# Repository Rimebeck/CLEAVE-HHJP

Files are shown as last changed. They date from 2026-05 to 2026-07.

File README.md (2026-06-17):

# CLEAVE HHJP
日本語配列互換 / 完全無線 / Choc MX両対応のキーボード自作キット「CLEAVE HHJP」のドキュメントリポジトリです。

<p align="center">
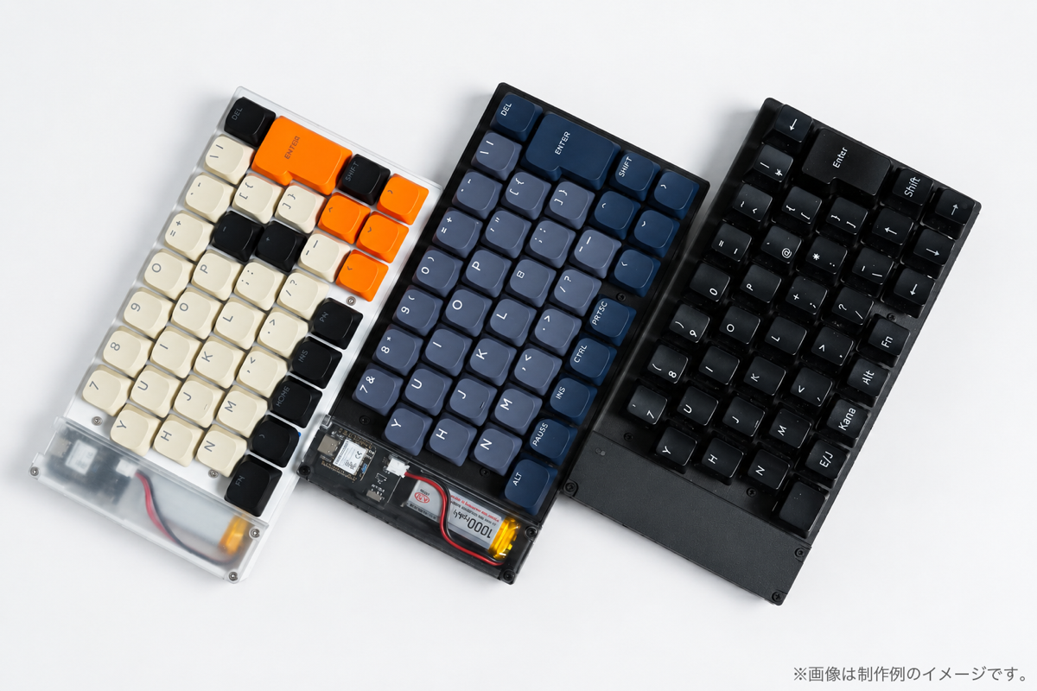
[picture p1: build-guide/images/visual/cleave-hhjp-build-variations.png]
CLEAVE HHJPの複数作例
  
</p>

<p align="center">
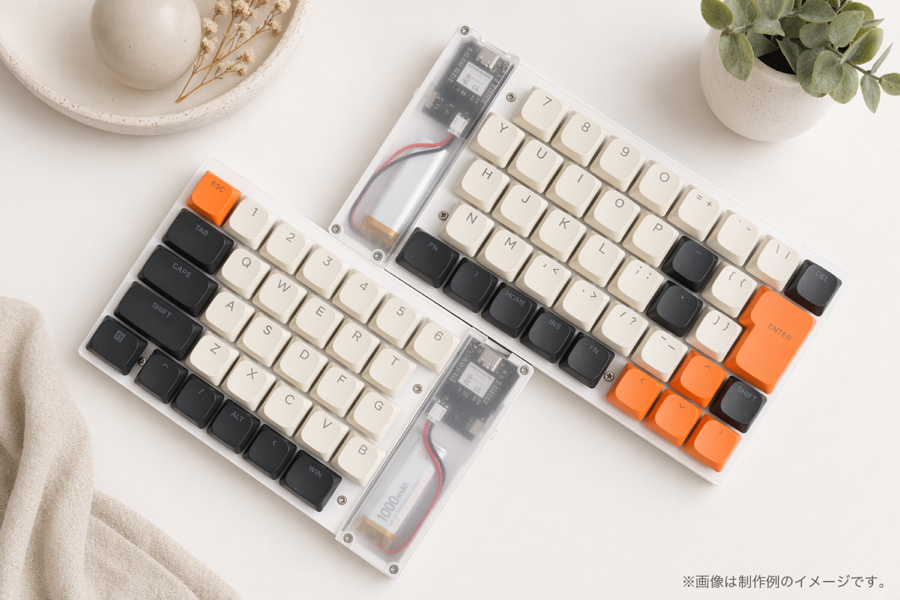
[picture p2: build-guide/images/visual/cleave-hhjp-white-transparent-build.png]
白い透明ケースのCLEAVE HHJP作例
  
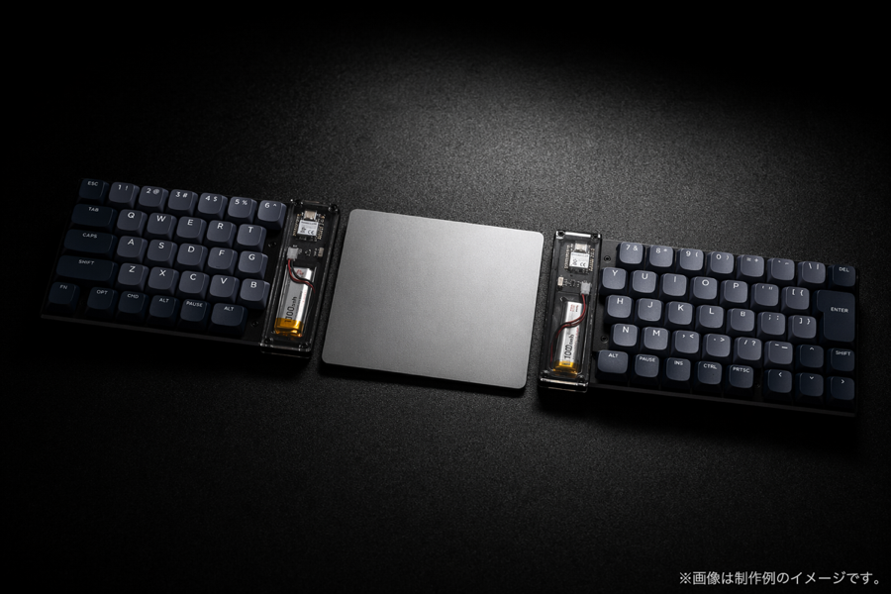
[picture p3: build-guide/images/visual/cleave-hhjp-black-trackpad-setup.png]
黒いCLEAVE HHJPとトラックパッドの作例
  
</p>

購入先：[BOOTH販売ページ](https://rimebeck.booth.pm/items/8395519)

## ドキュメント

- [ビルドガイド](build-guide/README.md)
  組み立て、ファームウェア書き込み、ケース作成、完成後の使い方、カスタマイズ方法をまとめています。

## 関連リンク

- [ファームウェア配布ページ](https://github.com/Rimebeck/Cleave-HHJP/releases)
- [ケースの3Dモデル・PCB 3Dデータ](https://github.com/Rimebeck/Cleave-HHJP/tree/main/models)

## 問い合わせ・不具合報告

ご不明な点はビルドガイドリポジトリの[Issues](https://github.com/Rimebeck/Cleave-HHJP/issues)またはBOOTHの購入者問合せからご連絡ください。

----
QRコードは株式会社デンソーウェーブの登録商標です

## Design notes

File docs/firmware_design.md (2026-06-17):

# ZMKファームウェア設計書
## HHKB JP分割Bluetoothキーボード (CLEAVE HHJP)

---

## 1. プロジェクト概要

### 1.1 キーボード仕様

| 項目 | 仕様 |
|---|---|
| 製品名 | CLEAVE HHJP (HHKB JP分割Bluetoothキーボード) |
| キー配列 | HHKB JP配列ベース |
| 総キー数 | 70キー（左31 + 右39） |
| 分割方式 | 左右分割・無線接続 |
| 接続方式 | Bluetooth 5.0 BLE |
| ホットスワップ | Kailh MX/Chocソケット対応 |

### 1.2 技術スタック

| 要素 | 採用技術 |
|---|---|
| ファームウェア | ZMK (Zephyr Mechanical Keyboard) |
| ビルドシステム | GitHub Actions |
| キーマップ編集 | ZMK Studio対応（GUIによる動的変更可能） |
| 開発環境 | West (Zephyr Build System) |
| 配布形式 | UF2ファイル（USB Mass Storageで書き込み） |

### 1.3 主要機能

- ZMK Studio対応による動的キーマップ変更
- Bluetooth 5デバイス切替
- バッテリー残量表示（内蔵RGB LED）
- 無線分割通信（左右BLE接続）
- スリープ/ウェイク機能
- USB充電（電源スイッチOFF時も充電可能）

---

## 2. ハードウェア仕様

### 2.1 マイコン (MCU)

| 項目 | 仕様 |
|---|---|
| モデル | Seeed XIAO nRF52840 Plus |
| プロセッサ | ARM Cortex-M4 64MHz (Nordic nRF52840) |
| メモリ | 256KB RAM / 1MB Flash |
| Bluetooth | Bluetooth 5.0 / BLE |
| GPIO数 | 20ピン（表面11 + 端面スルーホール9） |
| 技適認証 | 222-257139 |
| 動作電圧 | 3.3V |
| 実装方法 | 直接SMDはんだ付け（ピンヘッダ不使用） |
| 数量 | 2個（左右各1個） |

**採用理由**:
- GPIO 20本（通常版13本）で左右両側の大型マトリックスに対応
- 追加ピンは端面スルーホール（1.27mmピッチ）で裏面パッドへの細線はんだ付け不要
- 内蔵LiPo充電回路（BQ25101）とRGB LED搭載
- 技適認証済みでBluetoothキーボードの販売・頒布が可能

### 2.2 キーマトリックス構成

#### 左側PCB

| 項目 | 仕様 |
|---|---|
| マトリックス | 7列（COL0-6） × 5行（ROW0-4） |
| キー数 | 31キー |
| スキャン方式 | COL2ROW |
| ダイオード | 1N4148W (SOD-123) × 31個 |

**キー配置**:
```
Row 0: Esc, 1, 2, 3, 4, 5, 6
Row 1: Tab, Q, W, E, R, T
Row 2: Ctrl, A, S, D, F, G
Row 3: Shift, Z, X, C, V, B
Row 4: Fn, Win, Cmd, Alt, 英/日, Space (左側)
```

#### 右側PCB

| 項目 | 仕様 |
|---|---|
| マトリックス | 8列（COL0-7） × 5行（ROW0-4） |
| キー数 | 39キー |
| スキャン方式 | COL2ROW |
| ダイオード | 1N4148W (SOD-123) × 39個 |

**キー配置**:
```
Row 0: 7, 8, 9, 0, -, ^, ¥, Backspace
Row 1: Y, U, I, O, P, @, [, Enter
Row 2: H, J, K, L, ;, :, ]
Row 3: N, M, <, >, /, _, ↑, Shift
Row 4: Space (右側), 英/日, カナ, Alt, Fn, ←, ↓, →
```

### 2.3 ピンアサイン

#### 左側PCB - ピン配置

| 機能 | 論理名 | 物理ピン | nRF52840ピン | 備考 |
|---|---|---|---|---|
| COL0 | D0 | P0.02 | P0.02 | 表面パッド |
| COL1 | D1 | P0.03 | P0.03 | 表面パッド |
| COL2 | D2 | P0.28 | P0.28 | 表面パッド |
| COL3 | D3 | P0.29 | P0.29 | 表面パッド |
| COL4 | D4 | P0.04 | P0.04 | 表面パッド |
| COL5 | D5 | P0.05 | P0.05 | 表面パッド |
| COL6 | D6 | P1.11 | P1.11 | 表面パッド |
| ROW0 | D7 | P1.12 | P1.12 | 表面パッド |
| ROW1 | D8 | P1.13 | P1.13 | 表面パッド |
| ROW2 | D9 | P1.14 | P1.14 | 表面パッド |
| ROW3 | D10 | P1.15 | P1.15 | 表面パッド |
| ROW4 | D11 | P0.09 | P0.09 | **端面TH** / NFC1 |
| 予備 | D12 | P0.10 | P0.10 | **端面TH** / NFC2 |

**重要**: D11 (P0.09) はNFCピンのため、`CONFIG_NFCT_PINS_AS_GPIOS=y` の設定が**必須**です。

#### 右側PCB - ピン配置

| 機能 | 論理名 | 物理ピン | nRF52840ピン | 備考 |
|---|---|---|---|---|
| COL0 | D0 | P0.02 | P0.02 | 表面パッド |
| COL1 | D1 | P0.03 | P0.03 | 表面パッド |
| COL2 | D2 | P0.28 | P0.28 | 表面パッド |
| COL3 | D3 | P0.29 | P0.29 | 表面パッド |
| COL4 | D4 | P0.04 | P0.04 | 表面パッド |
| COL5 | D5 | P0.05 | P0.05 | 表面パッド |
| COL6 | D6 | P1.11 | P1.11 | 表面パッド |
| COL7 | D7 | P1.12 | P1.12 | 表面パッド |
| ROW0 | D8 | P1.13 | P1.13 | 表面パッド |
| ROW1 | D9 | P1.14 | P1.14 | 表面パッド |
| ROW2 | D10 | P1.15 | P1.15 | 表面パッド |
| ROW3 | D11 | P0.09 | P0.09 | **端面TH** / NFC1 |
| ROW4 | D12 | P0.10 | P0.10 | **端面TH** / NFC2 |
| 予備 | D13 | P0.13 | P0.13 | **端面TH** / 充電電流制御 |

**重要**: D11 (P0.09) とD12 (P0.10) はNFCピンのため、`CONFIG_NFCT_PINS_AS_GPIOS=y` の設定が**必須**です。

### 2.4 LED仕様

#### ステータス表示LED

| 項目 | 仕様 |
|---|---|
| LED種別 | XIAO nRF52840 Plus内蔵User LED（RGB 3-in-1） |
| 赤色ピン | P0.26 (GPIO_ACTIVE_LOW) |
| 緑色ピン | P0.30 (GPIO_ACTIVE_LOW) |
| 青色ピン | P0.06 (GPIO_ACTIVE_LOW) |
| 制御方法 | zmk-rgbled-widget（外部モジュール） |
| 外部部品 | 不要（MCU内蔵） |

**LED表示パターン** (zmk-rgbled-widget):

| 状態 | 色 | パターン | 表示タイミング |
|---|-----|---|---|
| 高バッテリー残量 (>80%) | 緑 | 約1秒点灯 | 起動時 |
| 中バッテリー残量 (20-80%) | 黄 | 約1秒点灯 | 起動時 |
| BLE接続済み | 青 | 約1秒点灯 | 接続確立時 |
| 低バッテリー残量 (<20%) | 赤 | 約1秒点灯 | 起動時または警告表示時 |
| 未接続 | 赤 | 約1秒点灯 | 切断時 |

#### 充電LED

| 項目 | 仕様 |
|---|---|
| LED種別 | XIAO nRF52840 Plus内蔵充電LED |
| 制御 | 自動（BQ25101 ICによる） |
| 緑色点灯 | 充電中 |
| 消灯 | 充電完了 |

**注**: 充電LEDはUser LEDとは別系統で、ファームウェアからの制御は不要です。

### 2.5 電源仕様

#### バッテリー

| 項目 | 仕様 |
|---|---|
| 種別 | LiPo (リチウムポリマー) |
| 容量選択肢 | 100mAh または 250mAh |
| 公称電圧 | 3.7V |
| 動作範囲 | 3.2V - 4.2V |
| コネクタ | JST PHコネクタ 2ピン |
| 数量 | 2個（左右各1個、独立動作） |

**推定動作時間**:
- 100mAh: アクティブ約1週間 / ディープスリープ約2ヶ月
- 250mAh: アクティブ約2.5週間 / ディープスリープ約5ヶ月

#### 充電回路

| 項目 | 仕様 |
|---|---|
| 充電IC | BQ25101 (XIAO内蔵) |
| 充電電流 | 100mA（P0.13 output-low による ISET 並列抵抗制御） |
| 充電方式 | USB Type-C経由 |
| 充電制御 | 自動（CC/CV方式） |

**充電電流の仕組み**:

BQ25101 の ISET ピンには固定 2.7kΩ 抵抗が接続されている（XIAO 基板上）。
P0.13 も 2.7kΩ を介して ISET に接続されており、GPIO 状態で充電電流を切替可能。

| P0.13 の状態 | 合成 RISET | 充電電流 |
|---|---|---|
| Input / Hi-Z（デフォルト） | 2.7kΩ | 50mA |
| Output LOW（ファームウェア設定） | 2.7k ∥ 2.7k = 1.35kΩ | 100mA |
| Output HIGH（**使用禁止**） | N/A（ISET 異常） | 0mA（充電停止） |

#### 電源スイッチ・バイパス回路

| 項目 | 仕様 |
|---|---|
| スイッチ | MSK-12C02 スライドスイッチ（左右各1個） |
| バイパスダイオード | B5819W ショットキーダイオード (SOD-123) |
| 特殊機能 | 電源スイッチOFF時もUSB給電で充電・動作可能 |

**回路構成**:
```
XIAO BAT+ --+-- [MSK-12C02 スイッチ] --+-- LiPo BAT+
            |                          |
            +-- [B5819W ショットキー] --+
                 (カソードをバッテリー側へ)

XIAO GND -------- LiPo BAT-
```

**動作**:
- スイッチON: 通常動作、バッテリーから直接給電
- スイッチOFF: バッテリーからの給電は停止。USB Type-C接続時はUSB給電により充電・動作可能

### 2.6 分割通信仕様

| 項目 | 仕様 |
|---|---|
| 通信方式 | **完全無線** - Bluetooth 5.0 BLE（左右分割 + ホスト接続） |
| 左側役割 | **セントラル＆ペリフェラル**（右側XIAOへ接続 + ホストPCから接続を受付） |
| 右側役割 | ペリフェラル（左側XIAOにBLE接続） |
| ホスト接続 | **Bluetooth 5.0 BLE**（常時利用は完全無線） |
| USB接続用途 | ファームウェア更新・充電・ZMK Studio接続のみ |
| 通信プロトコル | ZMK Split BLE |

**通信フロー**:
```
[ホストPC/Mac] <-- BLE --> [左側XIAO] <-- BLE --> [右側XIAO]
                           (Central &              (Peripheral)
                            Peripheral)
```

**重要な設計ポイント**:
- **左側XIAOは二重役割**: 右側XIAOに対してはセントラル、ホストPCに対してはペリフェラル
- **常時利用は完全無線**: USB接続はファームウェア更新、充電、デバッグ時のみ使用
- **遅延特性**: 右側キーは左側経由でホストに送信されるため、10-20ms程度の遅延が発生
- **USB接続時の動作**: USB接続中もBluetoothホスト接続が優先され、USBはデバッグログ出力のみに使用

---

## 3. ZMKファームウェアアーキテクチャ

### 3.1 ZMK概要

ZMKは、Zephyr RTOSをベースとした次世代キーボードファームウェアです。以下の特徴があります：

- **無線ファースト設計**: Bluetooth LEを標準サポート
- **低消費電力**: スリープ/アイドル機能による長時間動作
- **Zephyr RTOS**: 堅牢なリアルタイムOS基盤
- **デバイスツリー記述**: ハードウェア構成を宣言的に定義
- **GitHub Actions統合**: プッシュ時に自動ビルド

### 3.2 プロジェクト構造

ZMK用のファームウェアは、**zmk-configリポジトリ**として構築します。以下の構造を採用します：

```
zmk-config/
├── .github/
│   └── workflows/
│       ├── build-firmware.yml     # GitHub Actionsビルド定義
│       └── release.yml            # 手動Release昇格ワークフロー
├── config/
│   ├── boards/
│   │   └── shields/
│   │       └── cleave_hhjp/
│   │           ├── cleave_hhjp.conf            # 共通設定
│   │           ├── cleave_hhjp.dtsi            # 共通デバイスツリー
│   │           ├── cleave_hhjp.keymap          # キーマップ定義
│   │           ├── cleave_hhjp_left.overlay    # 左側ハードウェア定義
│   │           ├── cleave_hhjp_left.conf       # 左側設定
│   │           ├── cleave_hhjp_right.overlay   # 右側ハードウェア定義
│   │           ├── cleave_hhjp_right.conf      # 右側設定
│   │           ├── Kconfig.shield                # シールド宣言
│   │           └── Kconfig.defconfig             # デフォルト設定
│   └── west.yml                   # Westマニフェスト（依存関係定義）
├── build.yaml                     # ビルドターゲット定義
├── docs/
│   └── firmware_design.md         # ファームウェア設計書
└── README.md                      # プロジェクト説明
```

### 3.3 必須ファイル一覧

#### 3.3.1 GitHub Actions設定

| ファイル | 役割 |
|---|---|
| `.github/workflows/build-firmware.yml` | `main` へのpush/PR時にZMKの再利用ワークフローでUF2を生成 |
| `.github/workflows/release.yml` | 生成済みartifactを指定バージョンのGitHub Releaseへ昇格 |

#### 3.3.2 シールド定義ファイル

| ファイル | 役割 |
|---|---|
| `config/boards/shields/cleave_hhjp/Kconfig.shield` | シールド名とボード互換性の宣言 |
| `config/boards/shields/cleave_hhjp/Kconfig.defconfig` | シールド選択時のデフォルト設定 |

#### 3.3.3 ハードウェア定義ファイル (デバイスツリー)

| ファイル | 役割 |
|---|---|
| `cleave_hhjp.dtsi` | 左右共通のデバイスツリー定義（LEDなど） |
| `cleave_hhjp_left.overlay` | 左側キーマトリックス定義（7列×5行） |
| `cleave_hhjp_right.overlay` | 右側キーマトリックス定義（8列×5行） |

#### 3.3.4 設定ファイル (Kconfig)

| ファイル | 役割 |
|---|---|
| `cleave_hhjp.conf` | 左右共通設定（NFC GPIO化、分割BLE、スリープ等） |
| `cleave_hhjp_left.conf` | 左側専用設定（セントラル役割） |
| `cleave_hhjp_right.conf` | 右側専用設定（ペリフェラル役割） |

#### 3.3.5 キーマップファイル

| ファイル | 役割 |
|---|---|
| `cleave_hhjp.keymap` | キー配列定義、レイヤー定義、ZMK Studio設定 |

#### 3.3.6 依存関係・ビルド設定

| ファイル | 役割 |
|---|---|
| `config/west.yml` | Westマニフェスト（zmk-rgbled-widget等の外部依存） |
| `build.yaml` | ビルドターゲット定義（左右両側、ZMK Studio、settings resetを自動ビルド） |

### 3.4 外部依存関係

このキーボードは、以下の外部ZMKモジュールに依存します：

| モジュール | リポジトリURL | 役割 |
|---|---|---|
| zmk-rgbled-widget | `https://github.com/caksoylar/zmk-rgbled-widget` | 内蔵RGB LEDによるステータス表示 |

**west.yml への追加方法**:
- `manifest.remotes` にリポジトリ情報を追加
- `manifest.projects` に依存モジュールを追加
- zmk-configテンプレートから初期化時に自動で含まれる構造を利用

---

## 4. 必須ZMK設定項目

### 4.1 共通設定 (cleave_hhjp.conf)

以下の設定を `cleave_hhjp.conf` に記述します：

| 設定項目 | 値 | 説明 |
|---|-----|---|
| `CONFIG_NFCT_PINS_AS_GPIOS` | `y` | **必須**: D11/D12（NFC1/NFC2）をGPIOとして使用 |
| `CONFIG_ZMK_SPLIT` | `y` | 分割キーボード有効化 |
| `CONFIG_ZMK_SPLIT_BLE` | `y` | Bluetooth分割通信有効化 |
| `CONFIG_BT_CTLR_TX_PWR_PLUS_8` | `y` | BLE送信出力を+8dBmに増強（分割通信の安定化） |
| `CONFIG_ZMK_BATTERY_REPORTING` | `y` | バッテリー残量報告有効化 |
| `CONFIG_ZMK_SPLIT_BLE_CENTRAL_BATTERY_LEVEL_FETCHING` | `y` | セントラル側がペリフェラル側のバッテリー残量取得 |
| `CONFIG_ZMK_SPLIT_BLE_CENTRAL_BATTERY_LEVEL_PROXY` | `y` | ペリフェラル側バッテリー残量をホストに転送 |
| `CONFIG_ZMK_IDLE_TIMEOUT` | `30000` | アイドルタイムアウト 30秒 (30000ms) |
| `CONFIG_ZMK_SLEEP` | `y` | スリープモード有効化 |
| `CONFIG_ZMK_IDLE_SLEEP_TIMEOUT` | `900000` | スリープ移行時間 15分 (900000ms) |
| `CONFIG_SETTINGS` | `y` | キーマップ変更などの永続化に必要 |
| `CONFIG_NVS` | `y` | 設定保存用NVSストレージ有効化 |
| `CONFIG_FLASH` | `y` | フラッシュ書き込み有効化 |
| `CONFIG_FLASH_PAGE_LAYOUT` | `y` | フラッシュページ情報有効化 |
| `CONFIG_FLASH_MAP` | `y` | フラッシュ領域マップ有効化 |

**重要**: `CONFIG_NFCT_PINS_AS_GPIOS=y` がない場合、D11/D12がGPIOとして動作せず、マトリックススキャンが正常に動作しません。

**現状確認メモ**: 本設計では `CONFIG_NFCT_PINS_AS_GPIOS=y` を必須としています。実際の設定ファイルにこの項目がない場合は、ファームウェア修正タスクとして追加を確認してください。

### 4.2 左側設定 (cleave_hhjp_left.conf)

| 設定項目 | 値 | 説明 |
|---|-----|---|
| `CONFIG_ZMK_SPLIT_ROLE_CENTRAL` | `y` | セントラル役割（右側XIAOへの接続） |
| `CONFIG_ZMK_SPLIT_BLE_CENTRAL_PERIPHERALS` | `1` | セントラルが接続するペリフェラル数（右側の1台） |
| `CONFIG_ZMK_STUDIO` | `y` | ZMK Studio有効化（左側/セントラル側のみ） |
| `CONFIG_ZMK_STUDIO_LOCKING` | `n` | ZMK Studioでの変更ロックを無効化 |

**注**: 左側はセントラルとして右側に接続しつつ、ホストPCに対してはペリフェラルとして動作します。ZMKではこの構成が標準でサポートされており、追加設定は不要です。

### 4.3 右側設定 (cleave_hhjp_right.conf)

| 設定項目 | 値 | 説明 |
|---|-----|---|
| `CONFIG_ZMK_STUDIO` | `n` | ZMK Studioは左側/セントラル側のみで有効化 |

**注**: 右側は `CONFIG_ZMK_SPLIT_ROLE_CENTRAL` を設定しないことで、分割BLEのペリフェラルとして動作します。

### 4.4 完全ワイヤレス動作のための重要設定

**完全ワイヤレス動作（USB不使用）を実現するため、以下の設定が重要です**:

| 設定項目 | 値 | 説明 |
|---|-----|---|
| `CONFIG_ZMK_BLE_EXPERIMENTAL_CONN` | `y` | **推奨**: BLE接続の実験的改善（接続安定性向上） |
| `CONFIG_BT_MAX_CONN` | `6` | 最大BLE接続数（右側分割1 + ホスト5デバイス） |
| `CONFIG_BT_MAX_PAIRED` | `6` | 最大ペアリングデバイス数 |

**注**: ZMKは標準で、USB接続時はUSBを優先、USB未接続時は自動的にBluetooth動作に切り替わります。完全ワイヤレス動作のために追加の設定は不要です。

### 4.5 その他推奨設定（オプション）

以下は必要に応じて `cleave_hhjp.conf` に追加可能な設定です：

| 設定項目 | 値 | 説明 |
|---|-----|---|
| `CONFIG_ZMK_USB_LOGGING` | `y` | USB経由でのデバッグログ出力（開発時のみ、常時利用では不要） |
| `CONFIG_BT_GATT_ENFORCE_SUBSCRIPTION` | `n` | GATT購読強制を無効化（一部ホストとの互換性向上） |

---

## 5. デバイスツリー構造

### 5.1 デバイスツリー概要

ZMKでは、ハードウェア構成を**デバイスツリー**（Device Tree）形式で記述します。これはLinuxカーネルやZephyr RTOSで使用される標準的なハードウェア記述方法です。

### 5.2 共通デバイスツリー (cleave_hhjp.dtsi)

左右共通のハードウェア定義を記述します：

**記述内容**:
- zmk-rgbled-widget によるRGB LED制御設定
- User LED (Red: P0.26, Green: P0.30, Blue: P0.06) の定義
- LEDステータス表示のノード定義

**技術的ポイント**:
- `compatible = "zmk,rgbled-widget"`
- GPIOピンは`GPIO_ACTIVE_LOW`指定（XIAO仕様）
- デバイスツリーの`chosen`ノードでグローバル参照可能に設定

### 5.3 左側オーバーレイ (cleave_hhjp_left.overlay)

**記述内容**:
- キーマトリックス: 7列 × 5行
- 列ピン (COL0-6): D0-D6 (P0.02, P0.03, P0.28, P0.29, P0.04, P0.05, P1.11)
- 行ピン (ROW0-4): D7-D11 (P1.12, P1.13, P1.14, P1.15, P0.09)
- ダイオード方向: `col2row`
- キー配置: HHKB JP左側31キーの物理配置

**技術的ポイント**:
- `compatible = "zmk,matrix-transform"`
- 行・列ピンは`<&gpio0 X GPIO_ACTIVE_HIGH>`形式で指定
- 行ピンに`(GPIO_ACTIVE_HIGH | GPIO_PULL_DOWN)`でプルダウン設定
- rc-to-xy座標マッピングで物理配置を定義

### 5.4 右側オーバーレイ (cleave_hhjp_right.overlay)

**記述内容**:
- キーマトリックス: 8列 × 5行
- 列ピン (COL0-7): D0-D7 (P0.02, P0.03, P0.28, P0.29, P0.04, P0.05, P1.11, P1.12)
- 行ピン (ROW0-4): D8-D12 (P1.13, P1.14, P1.15, P0.09, P0.10)
- ダイオード方向: `col2row`
- キー配置: HHKB JP右側39キーの物理配置

**技術的ポイント**:
- 左側と同様の構造
- D11 (P0.09) とD12 (P0.10) はNFCピンのため、`CONFIG_NFCT_PINS_AS_GPIOS=y` が必須
- 右側は列が8列に増加（左側は7列）

---

## 6. キーマップ定義

### 6.1 キーマップファイル構造

`cleave_hhjp.keymap` ファイルには以下を記述します：

1. **physical_layout** - ZMK Studio用の物理レイアウト定義（70キーの座標）
2. **keymap** - 実際のキー割り当て
3. **レイヤー定義** - 複数レイヤー（デフォルト、Fn、Bluetooth制御等）

### 6.2 ZMK Studio対応 - physical_layout

ZMK Studioで動的にキーマップを変更可能にするため、`physical_layout` を定義します：

**記述内容**:
- 70キーすべての物理座標 (x, y) をミリメートル単位で定義
- キーサイズ (width, height) を定義
- キーの回転角度 (rotation) を定義（通常は0）
- transform参照を設定

**技術的ポイント**:
- `compatible = "zmk,physical-layout"`
- `display-name` でレイアウト名を指定
- `keys` プロパティに全キーの座標配列を記述
- ZMK Studioアプリで視覚的にキーマップを編集可能

### 6.3 レイヤー構成

| レイヤー番号 | レイヤー名 | 用途 |
|---|---|---|
| 0 | default_layer | デフォルトキー配列（HHKB JP配列） |
| 1 | fn_layer | Fnキー押下時（F1-F12、メディア、ナビゲーション） |

**デフォルトレイヤー (Layer 0)**:
- HHKB JP配列の標準キー配置
- 左右70キーすべてのキーコードを定義

**Fnレイヤー (Layer 1)**:
- ファンクションキー (F1-F12)
- メディアキー (再生/一時停止、音量調整等)
- 画面輝度調整
- 矢印キー等のナビゲーション
- Bluetoothプロファイル操作（`Fn` + `Ctrl` + `1`〜`5` で `BT_SEL 0`〜`BT_SEL 4`、`Fn` + `Ctrl` + `Backspace` で `BT_CLR`）

**Bluetooth操作の実装メモ**:
- 現行キーマップでは専用のBluetoothレイヤーを追加せず、Fnレイヤー上の `zmk,behavior-mod-morph` で実装します。
- `Ctrl` が押されていない場合、該当キーは通常の `F1`〜`F5` / `Delete` として動作します。

### 6.4 キーコード例

以下はZMKで使用する主なキーコード例です：

| 機能 | ZMKキーコード |
|---|---|
| 通常キー | `&kp A`, `&kp N1`, `&kp ESC` 等 |
| レイヤー切替 | `&mo 1` (押下中のみ), `&to 2` (トグル) |
| Bluetooth | `&bt BT_SEL 0`, `&bt BT_CLR` |
| メディア | `&kp C_PP` (再生/一時停止), `&kp C_VOL_UP` |
| 修飾キー | `&kp LSHIFT`, `&kp LCTRL`, `&kp LALT` |

---

## 7. ZMK Studio完全対応

### 7.1 ZMK Studioとは

ZMK Studioは、ZMKファームウェアのキーマップをGUIで動的に変更できるツールです。以下の特徴があります：

- **リアルタイム変更**: キーボードをPCに接続したまま、キーマップを即座に変更
- **ビジュアル編集**: 物理レイアウトを視覚的に表示し、ドラッグ&ドロップでキー割り当て
- **ファームウェア書き込み不要**: 変更はキーボード内のフラッシュメモリに保存
- **Webアプリ**: ブラウザから https://zmk.studio でアクセス可能

### 7.2 ZMK Studio有効化手順

**1. ファームウェア設定**

`cleave_hhjp.conf` に以下を追加：

```
CONFIG_ZMK_STUDIO=y
```

**2. physical_layout定義**

`cleave_hhjp.keymap` に70キー分の物理座標を定義（6.2節参照）

**3. ビルド・書き込み**

GitHub ActionsでビルドされたUF2ファイルをXIAOに書き込み

**4. ZMK Studioアクセス**

- ブラウザで https://zmk.studio を開く
- **左側キーボードをUSB接続**（ZMK StudioはUSB経由でのみ接続可能）
- 「Connect」ボタンでキーボードを検出
- GUIでキーマップを編集・保存

**重要**: ZMK Studioでの設定変更はUSB接続が必要ですが、設定完了後の常時利用は完全ワイヤレスで動作します。

### 7.3 ZMK Studioで可能な操作

| 操作 | 説明 |
|---|---|
| キー割り当て変更 | 任意のキーに別のキーコードを割り当て |
| レイヤー追加/削除 | 新しいレイヤーを作成、既存レイヤーを削除 |
| Bluetooth設定 | デバイス切替キーの配置変更 |
| マクロ作成 | 複数キー入力のマクロを定義 |
| 設定エクスポート | 現在のキーマップをJSON形式でエクスポート |

---

## 8. ビルドシステム（GitHub Actions）

### 8.1 GitHub Actions概要

このプロジェクトでは、GitHub Actionsを使用して以下を自動化します：

1. `config/`、`build.yaml`、ビルドワークフローへの変更を検知
2. ZMK公式の再利用ワークフローでファームウェアをビルド
3. 左側、右側、settings reset用のUF2ファイルを生成
4. 必要に応じて生成済みartifactをGitHub Releaseへ昇格

### 8.2 ビルドワークフロー (.github/workflows/build-firmware.yml)

**トリガー**:
- `main` ブランチへのプッシュ
- `main` ブランチ向けのPull Request
- `config/` ディレクトリの変更
- `build.yaml` の変更
- `.github/workflows/build-firmware.yml` の変更

**ワークフロー内容**:
```yaml
name: Build ZMK firmware
on:
   push:
      branches:
         - main
      paths:
         - 'config/**'
         - 'build.yaml'
         - '.github/workflows/build-firmware.yml'
   pull_request:
      branches:
         - main
      paths:
         - 'config/**'
         - 'build.yaml'
         - '.github/workflows/build-firmware.yml'

jobs:
   build:
      uses: zmkfirmware/zmk/.github/workflows/build-user-config.yml@v0.3
```

**ビルドターゲット** (`build.yaml` で定義):
- `xiao_ble` + `cleave_hhjp_left rgbled_adapter` (左側、ZMK Studio対応)
- `xiao_ble` + `cleave_hhjp_right rgbled_adapter` (右側)
- `xiao_ble` + `settings_reset` (設定リセット用)

**成果物**:
- Actionsの `firmware` artifact ZIP内に、各ビルドターゲットのUF2ファイルが生成されます。
- ファイル名はZMKのビルドワークフローにより、board/shield構成から生成されます。書き込み時は左側用、右側用、settings reset用を取り違えないようにしてください。

### 8.3 ビルドプロセス

1. **build.yaml読込**: ZMK公式ワークフローが `build.yaml` からビルドマトリックスを生成
2. **Westワークスペース初期化**: `config/west.yml` に基づきZMK本体と外部モジュールを取得
3. **ビルド実行**: `west build` で各ターゲットをビルド
4. **アーティファクトアップロード**: UF2ファイルを `firmware` artifactとして保存
5. **リリース昇格**: 必要に応じて `release.yml` を手動実行し、artifactをReleaseへ添付

### 8.4 build.yaml 定義

**記述内容**:
```yaml
# Copyright (c) 2025
# SPDX-License-Identifier: MIT

---
include:
- { board: xiao_ble, shield: "cleave_hhjp_left rgbled_adapter", snippet: studio-rpc-usb-uart, cmake-args: -DCONFIG_ZMK_STUDIO=y }
- { board: xiao_ble, shield: "cleave_hhjp_right rgbled_adapter" }
- { board: xiao_ble, shield: settings_reset }
```

**ポイント**:
- `xiao_ble` はXIAO nRF52840系のZMK用board名です。
- `rgbled_adapter` はzmk-rgbled-widget連携用の追加shieldです。
- `studio-rpc-usb-uart` と `CONFIG_ZMK_STUDIO=y` は、ZMK Studioを左側（セントラル側）で使うために左側ターゲットだけへ設定します。
- `settings_reset` はBluetoothペアリング情報や永続化設定を初期化するための補助UF2です。

### 8.5 ローカルビルド（Docker）

GitHub Actionsではなくローカルで確認したい場合は、ZMK公式Dockerイメージを使用できます。以下はリポジトリの最上位ディレクトリで実行する例です。

**Westワークスペース初期化（初回のみ）**:
```bash
docker run --rm -v "$PWD":/workspace -w /workspace zmkfirmware/zmk-build-arm:stable \
   sh -c "west init -l config && west update && west zephyr-export"
```

**左側ビルド（ZMK Studio対応）**:
```bash
docker run --rm -v "$PWD":/workspace -w /workspace zmkfirmware/zmk-build-arm:stable \
   west build -d build/left -p -s zmk/app -b xiao_ble -S studio-rpc-usb-uart -- \
      -DSHIELD="cleave_hhjp_left rgbled_adapter" \
      -DZMK_CONFIG=/workspace/config \
      -DCONFIG_ZMK_STUDIO=y

cp build/left/zephyr/zmk.uf2 cleave_hhjp_left-xiao_ble-zmk.uf2
```

**右側ビルド**:
```bash
docker run --rm -v "$PWD":/workspace -w /workspace zmkfirmware/zmk-build-arm:stable \
   west build -d build/right -p -s zmk/app -b xiao_ble -- \
      -DSHIELD="cleave_hhjp_right rgbled_adapter" \
      -DZMK_CONFIG=/workspace/config

cp build/right/zephyr/zmk.uf2 cleave_hhjp_right-xiao_ble-zmk.uf2
```

**settings resetビルド**:
```bash
docker run --rm -v "$PWD":/workspace -w /workspace zmkfirmware/zmk-build-arm:stable \
   west build -d build/settings_reset -p -s zmk/app -b xiao_ble -- \
      -DSHIELD=settings_reset \
      -DZMK_CONFIG=/workspace/config

cp build/settings_reset/zephyr/zmk.uf2 settings_reset-xiao_ble-zmk.uf2
```

**クリーンアップ**:
```bash
rm -rf build
```

---

## 9. ファームウェア構築手順

### 9.1 前提条件

- GitHubアカウント
- Gitクライアントインストール済み
- テキストエディタ（VS Code推奨）

### 9.2 zmk-configリポジトリの初期化

**手順**:

1. **ZMK公式テンプレートを使用**

   https://github.com/zmkfirmware/unified-zmk-config-template にアクセスし、「Use this template」→「Create a new repository」をクリック

2. **リポジトリ名設定**

   リポジトリ名: `zmk-config-hhkb-jp-split` (任意)

   Publicに設定（GitHub Actions無料枠を利用）

3. **ローカルにクローン**

   ```bash
   git clone https://github.com/<あなたのユーザー名>/zmk-config-hhkb-jp-split.git
   cd zmk-config-hhkb-jp-split
   ```

### 9.3 シールド定義ファイルの作成

**手順**:

1. **ディレクトリ作成**

   ```bash
   mkdir -p config/boards/shields/cleave_hhjp
   ```

2. **以下のファイルを作成**

   - `config/boards/shields/cleave_hhjp/Kconfig.shield`
   - `config/boards/shields/cleave_hhjp/Kconfig.defconfig`
   - `config/boards/shields/cleave_hhjp/cleave_hhjp.conf`
   - `config/boards/shields/cleave_hhjp/cleave_hhjp.dtsi`
   - `config/boards/shields/cleave_hhjp/cleave_hhjp_left.overlay`
   - `config/boards/shields/cleave_hhjp/cleave_hhjp_left.conf`
   - `config/boards/shields/cleave_hhjp/cleave_hhjp_right.overlay`
   - `config/boards/shields/cleave_hhjp/cleave_hhjp_right.conf`
   - `config/boards/shields/cleave_hhjp/cleave_hhjp.keymap`

3. **各ファイルの内容を記述**

   各ファイルの詳細は、本設計書の該当セクション（3.3節、4節、5節、6節）を参照し、ハードウェア仕様に基づいて記述します。

### 9.4 west.yml の設定

**手順**:

1. **config/west.yml を編集**

   zmk-rgbled-widget 依存関係を追加：

   ```yaml
   manifest:
     remotes:
       - name: zmkfirmware
         url-base: https://github.com/zmkfirmware
       - name: caksoylar
         url-base: https://github.com/caksoylar
     projects:
       - name: zmk
         remote: zmkfirmware
         revision: main
         import: app/west.yml
       - name: zmk-rgbled-widget
         remote: caksoylar
         revision: main
     self:
       path: config
   ```

### 9.5 build.yaml の設定

**手順**:

1. **build.yaml を編集**

   ```yaml
   ---
   include:
     - board: xiao_ble
       shield: cleave_hhjp_left rgbled_adapter
       snippet: studio-rpc-usb-uart
       cmake-args: -DCONFIG_ZMK_STUDIO=y
     - board: xiao_ble
       shield: cleave_hhjp_right rgbled_adapter
     - board: xiao_ble
       shield: settings_reset
   ```

### 9.6 GitHub Actionsの有効化

**手順**:

1. **.github/workflows/build-firmware.yml を確認**

    このリポジトリでは `build-firmware.yml` がZMK公式の再利用ワークフローを呼び出します。`config/`、`build.yaml`、ワークフロー本体を変更したときにビルドが走ることを確認します。

2. **リポジトリにプッシュ**

   ```bash
   git add .
   git commit -m "Initial HHKB JP split keyboard configuration"
   git push origin main
   ```

3. **GitHub Actionsの実行確認**

   GitHubリポジトリの「Actions」タブでビルドが開始されることを確認します。

4. **ビルド成功後**

   「Actions」→最新のワークフロー実行→「Artifacts」からUF2ファイルをダウンロードできます。

### 9.7 リリース作成（オプション）

**手順**:

1. **ビルドartifactを確認**

   GitHub ActionsのBuild ZMK firmware実行から `firmware` artifactを確認し、リリースに含めるRun IDを控えます。

2. **Promote Firmware to Releaseを手動実行**

   `.github/workflows/release.yml` の `workflow_dispatch` で以下を指定します。

   - `run_id`: artifactがあるActionsのRun ID
   - `version`: `v1.0.0` のようなリリースバージョン
   - `prerelease`: プレリリースにする場合は `true`

3. **Releaseを確認**

   ワークフローがartifactをダウンロードし、指定したタグ名のGitHub ReleaseへUF2ファイルを添付します。

---

## 10. ファームウェア書き込み手順

### 10.1 必要なもの

- 組み立て済みのキーボード（左右両側）
- USB Type-Cケーブル
- ビルド済みUF2ファイル（左右各1つ）

### 10.2 書き込み手順（左側）

1. **ブートローダーモード起動**

   - 左側キーボードの電源スイッチをONにする
   - USB Type-CケーブルでPCに接続
   - XIAOのリセットボタンを**ダブルクリック**
   - オレンジ色のLEDがゆっくり点滅開始（ブートローダーモード）

2. **USBマスストレージデバイスとして認識**

   - PCに「XIAO-SENSE」または「XIAO-nRF52」という名前のドライブがマウントされる

3. **UF2ファイルコピー**

   - 左側用UF2（例: `cleave_hhjp_left-xiao_ble-zmk.uf2`、またはartifact内で `cleave_hhjp_left` を含むUF2）をドライブにドラッグ&ドロップ
   - 自動的に書き込みが開始され、完了後に自動でアンマウント

4. **書き込み完了**

   - 左側キーボードが自動的に再起動
   - User LEDが接続状態に応じた色に約1秒点灯（BLEアドバタイジング開始）

### 10.3 書き込み手順（右側）

左側と同様の手順を右側キーボードでも実行します：

1. 右側キーボードの電源スイッチをONにする
2. USB Type-CケーブルでPCに接続
3. XIAOのリセットボタンを**ダブルクリック**
4. 右側用UF2（例: `cleave_hhjp_right-xiao_ble-zmk.uf2`、またはartifact内で `cleave_hhjp_right` を含むUF2）をコピー
5. 自動的に再起動

### 10.4 ペアリング（完全ワイヤレス動作）

**重要**: このキーボードは**完全ワイヤレス設計**です。常時利用はすべてBluetooth接続で行います。

1. **左右接続（自動）**

   - 左右両側の電源をONにする
   - 左側（セントラル）が右側（ペリフェラル）を自動検出・接続
   - 接続完了後、User LEDが青色に約1秒点灯（接続済み）

2. **ホストPC接続（Bluetooth）**

   - **USB接続を外す**（充電・ファームウェア更新が完了したら抜く）
   - PCのBluetooth設定を開く
   - 「CLEAVE HHJP」という名前のデバイスが表示される
   - ペアリング実行
   - 接続完了後、キーボードが**完全ワイヤレス**で使用可能

3. **複数デバイス切替**

   - Fnレイヤー上のBluetooth操作で最大5台のデバイスを切替可能
   - `Fn` + `Ctrl` + `1`〜`5` で `BT_SEL 0`〜`BT_SEL 4` を実行
   - `Fn` + `Ctrl` + `Backspace` で `BT_CLR` を実行
   - 例: PC、Mac、タブレット、スマートフォン等を切り替えて使用可能

### 10.5 トラブルシューティング

| 症状 | 原因 | 解決方法 |
|---|---|---|
| ブートローダーモードに入らない | リセットボタンのダブルクリック失敗 | ゆっくり2回押す（間隔0.5秒程度） |
| UF2コピー後もドライブが残る | 書き込み失敗 | 正しいUF2ファイルか確認、再度コピー |
| 左右が接続しない | ファームウェア不一致 | 左右両側に正しいUF2を書き込み直す |
| PCに接続できない | Bluetoothドライバー問題 | PCを再起動、Bluetoothをオフ/オン |
| キーが反応しない | マトリックス配線不良 | はんだ付け確認、ダイオード方向確認 |

---

## 11. 動作確認

### 11.1 初期動作確認チェックリスト

**完全ワイヤレス動作の確認**:

- [ ] 左側キーボード電源ON後、User LEDが接続状態に応じた色に約1秒点灯する
- [ ] 右側キーボード電源ON後、User LEDが接続状態に応じた色に約1秒点灯する
- [ ] 左右が自動接続し、User LEDが青色に約1秒点灯する（接続済み）
- [ ] **USB接続なし**でPCのBluetooth設定で「CLEAVE HHJP」が検出される
- [ ] **USB接続なし**でPCとペアリング完了後、全70キーが正常に入力される
- [ ] **完全ワイヤレス状態**でFnキー押下時のレイヤー切替が動作（F1-F12等）
- [ ] **完全ワイヤレス状態**でBluetoothレイヤーによるデバイス切替が動作
- [ ] USB充電時、充電LEDが緑色点灯（充電中。電源スイッチOFFでもUSB給電中は動作可能）
- [ ] USB充電完了後、充電LEDが消灯（充電完了）

**ZMK Studio確認（USB接続時のみ）**:

- [ ] ZMK Studio (https://zmk.studio) でキーボードが検出される（USB接続必須）
- [ ] ZMK Studioでキーマップ変更が可能
- [ ] キーマップ変更後、USB接続を外しても設定が保持される

### 11.2 LED動作確認

| 条件 | 期待されるLED表示 |
|---|---|
| 電源ON直後（バッテリー>80%） | 緑色に約1秒点灯 |
| BLEアドバタイジング開始時 | 黄色に約1秒点灯 |
| BLE接続済み | 青色に約1秒点灯 |
| バッテリー残量<20% | 赤色に約1秒点灯 |
| USB充電中 | 充電LED緑色点灯 |
| USB充電完了 | 充電LED消灯 |

### 11.3 ZMK Studio動作確認（USB接続時のみ）

**注意**: ZMK StudioはUSB接続時のみ使用可能です。設定変更後は、USB接続を外して完全ワイヤレスで動作させることを推奨します。

1. ブラウザで https://zmk.studio を開く
2. **左側キーボードをUSB接続**（完全ワイヤレス動作中の場合は一時的にUSB接続）
3. 「Connect」ボタンをクリック
4. 「CLEAVE HHJP」が表示されることを確認
5. 接続後、70キーの物理レイアウトが表示されることを確認
6. 任意のキーをクリックし、別のキーコードに変更
7. 「Save」ボタンで保存
8. キーボードを再起動せずに、変更したキーが動作することを確認
9. **USB接続を外し、Bluetooth接続で変更が保持されていることを確認**

---

## 12. カスタマイズ・拡張

### 12.1 キーマップのカスタマイズ

**方法1: ZMK Studioで変更（推奨）**
- GUIで直感的に変更可能
- ファームウェア再ビルド不要

**方法2: keymapファイル編集**
- `config/boards/shields/cleave_hhjp/cleave_hhjp.keymap` を編集
- より高度なカスタマイズ（マクロ、コンボ等）が可能
- 編集後、Gitにコミット・プッシュしてGitHub Actionsで自動ビルド

### 12.2 レイヤーの追加

1. `cleave_hhjp.keymap` の `keymap` ノード内に新しいレイヤーを追加
2. `bindings` プロパティに70キー分のキーコードを定義
3. 既存レイヤーに新レイヤーへの切替キー（`&mo 3` 等）を配置

### 12.3 マクロの追加

ZMKのマクロ機能を使用して、複数キー入力を1キーで実行可能：

1. `keymap` ファイルに `macros` ノードを追加
2. マクロを定義（例: `ZMK_MACRO(hello, ...)`）
3. キーマップでマクロを割り当て（例: `&hello`）

### 12.4 コンボの追加

複数キー同時押しで別のキーを出力：

1. `keymap` ファイルに `combos` ノードを追加
2. コンボを定義（例: A+Sで Escを出力）
3. タイムアウト設定（デフォルト50ms）

### 12.5 スリープ時間の変更

`cleave_hhjp.conf` で以下を変更：

- `CONFIG_ZMK_IDLE_TIMEOUT`: アイドルタイムアウト（ミリ秒）
- `CONFIG_ZMK_IDLE_SLEEP_TIMEOUT`: スリープ移行時間（ミリ秒）

### 12.6 Bluetooth出力パワーの調整

分割通信の距離や安定性を調整：

- `CONFIG_BT_CTLR_TX_PWR_PLUS_8`: +8dBm（最大）
- `CONFIG_BT_CTLR_TX_PWR_PLUS_4`: +4dBm
- `CONFIG_BT_CTLR_TX_PWR_0`: 0dBm（デフォルト）

---

## 13. デバッグ・ログ出力

### 13.1 USB経由のログ出力

開発時のデバッグには、USB経由でログを出力可能です：

**設定**:
`cleave_hhjp.conf` に以下を追加：

```
CONFIG_ZMK_USB_LOGGING=y
```

**ログ確認方法**:

**macOS**:
```bash
screen /dev/tty.usbmodem* 115200
```

**Linux**:
```bash
screen /dev/ttyACM0 115200
```

**Windows**:
- Tera TermやPuTTY等のシリアルターミナルでCOMポートに接続

### 13.2 ログレベルの設定

より詳細なログを出力：

```
CONFIG_LOG=y
CONFIG_ZMK_LOG_LEVEL_DBG=y
```

---

## 14. リファレンス

### 14.1 公式ドキュメント

| 項目 | URL |
|---|-----|
| ZMK公式ドキュメント | https://zmk.dev/ |
| ZMK Studio | https://zmk.studio |
| Zephyr RTOS | https://docs.zephyrproject.org/ |
| Nordic nRF52840 | https://www.nordicsemi.com/Products/nRF52840 |
| Seeed XIAO nRF52840 | https://wiki.seeedstudio.com/XIAO_BLE/ |

### 14.2 関連リポジトリ

| 項目 | URL |
|---|-----|
| ZMK本体 | https://github.com/zmkfirmware/zmk |
| zmk-config テンプレート | https://github.com/zmkfirmware/unified-zmk-config-template |
| zmk-rgbled-widget | https://github.com/caksoylar/zmk-rgbled-widget |

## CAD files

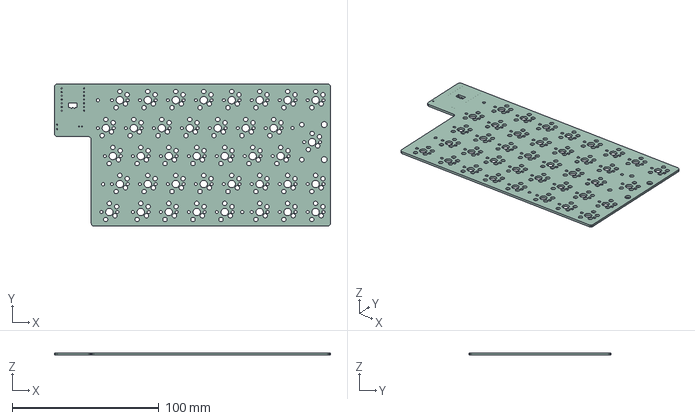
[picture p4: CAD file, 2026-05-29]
models/pcb/right.step
188.0 x 97.0 x 1.51 mm

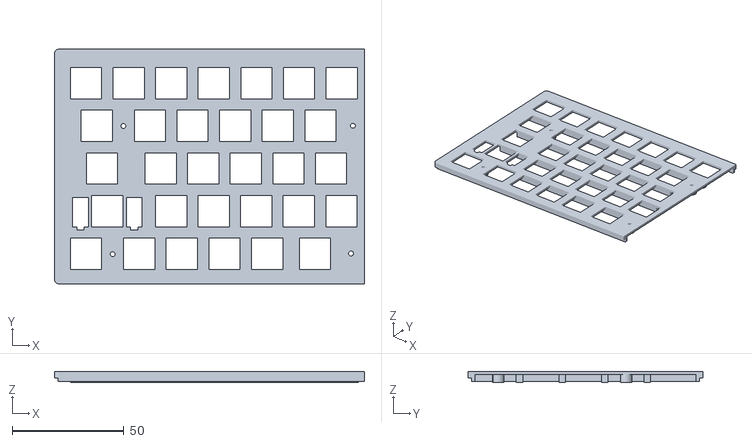
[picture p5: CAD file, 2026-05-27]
models/top_plate_mx_left.stl
138.6 x 105.0 x 5.10

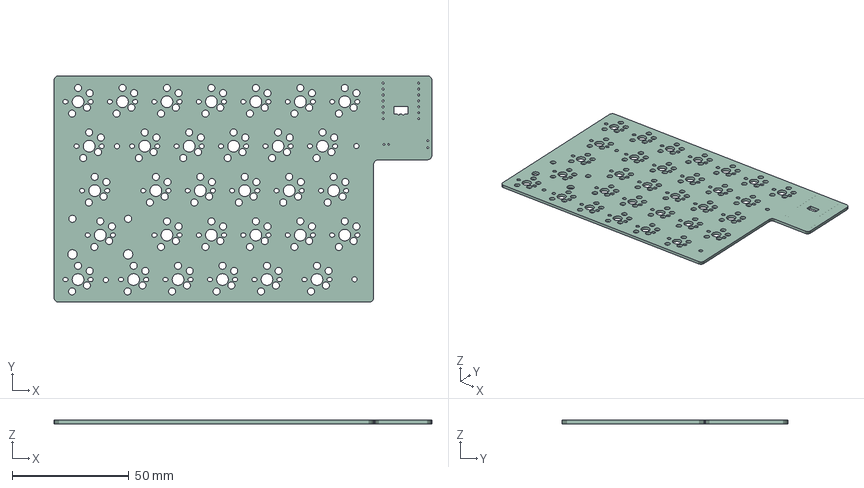
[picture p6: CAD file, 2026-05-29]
models/pcb/left.step
162.0 x 97.0 x 1.51 mm

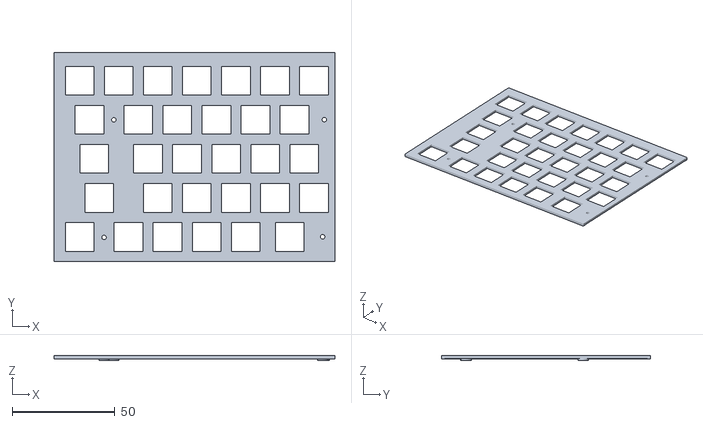
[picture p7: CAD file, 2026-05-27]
models/top_plate_choc_left.stl
137.0 x 101.8 x 2.29

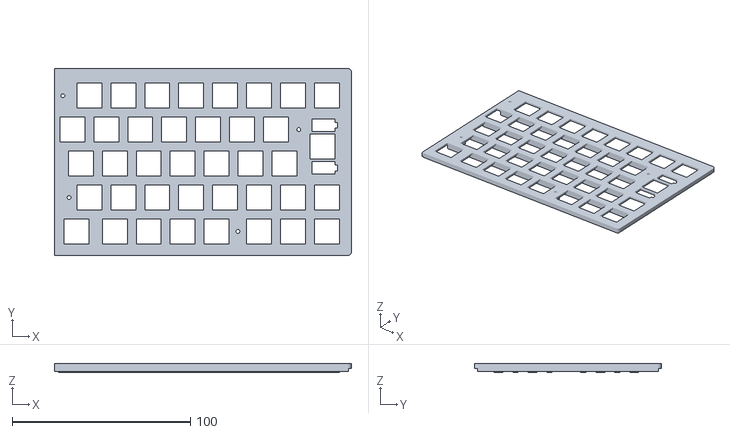
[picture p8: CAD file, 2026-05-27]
models/top_plate_mx_right.stl
166.8 x 105.0 x 5.10

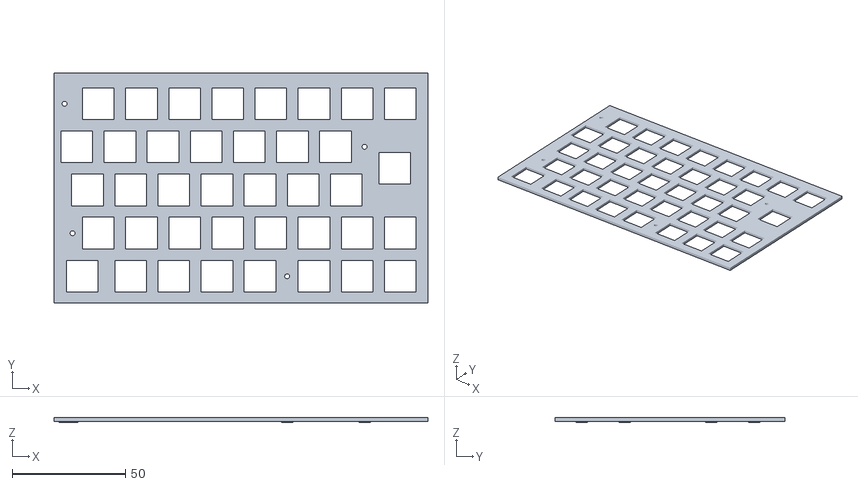
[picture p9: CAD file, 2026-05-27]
models/top_plate_choc_right.stl
165.2 x 101.8 x 2.29

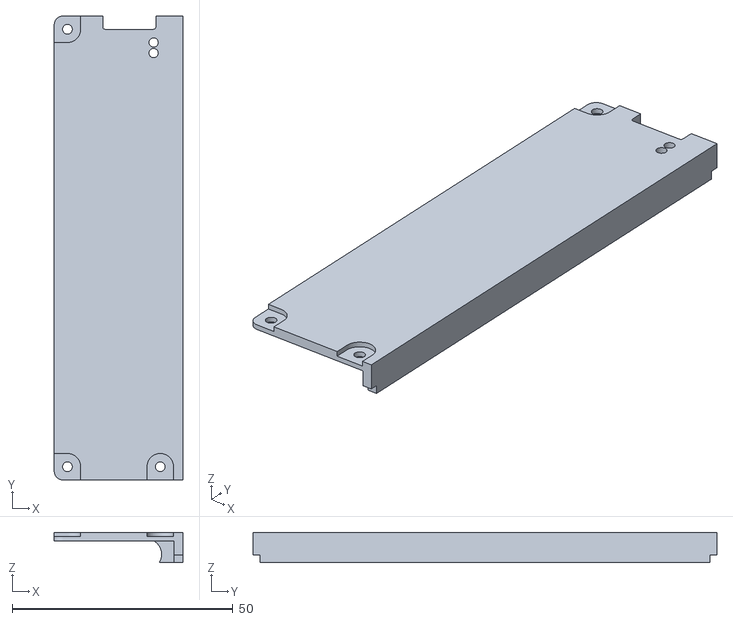
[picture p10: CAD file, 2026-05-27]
models/top_cover_right.stl
29.1 x 105.0 x 6.90

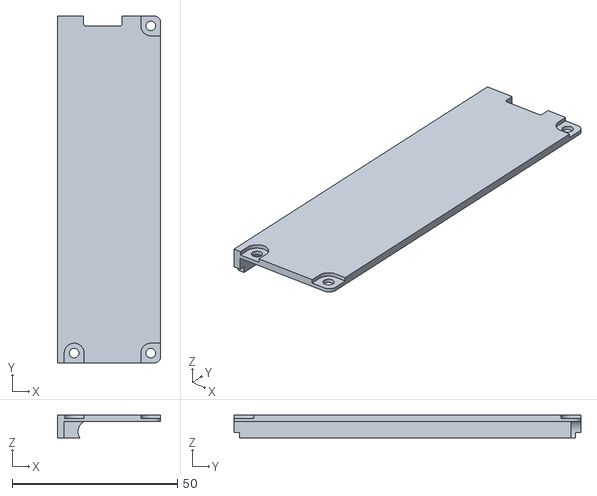
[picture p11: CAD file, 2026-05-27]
models/top_cover_left_no_indicator_hole.stl
31.3 x 105.0 x 6.90

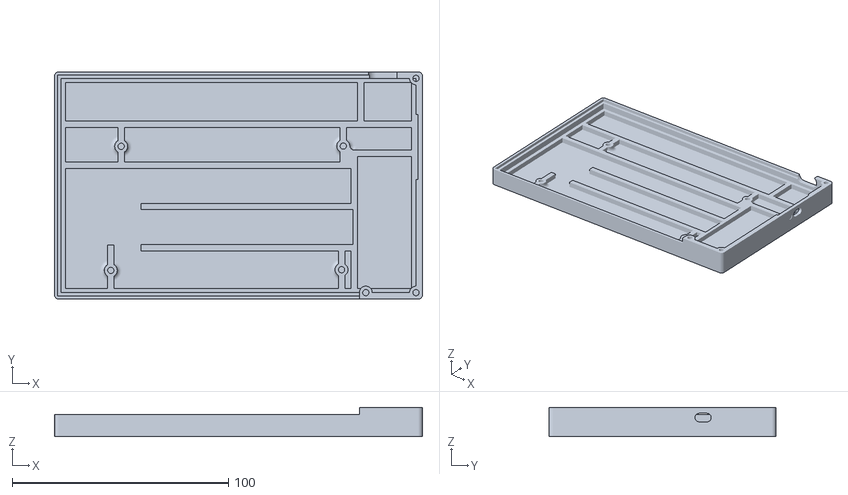
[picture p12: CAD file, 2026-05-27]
models/base_case_left.stl
170.0 x 105.0 x 13.5

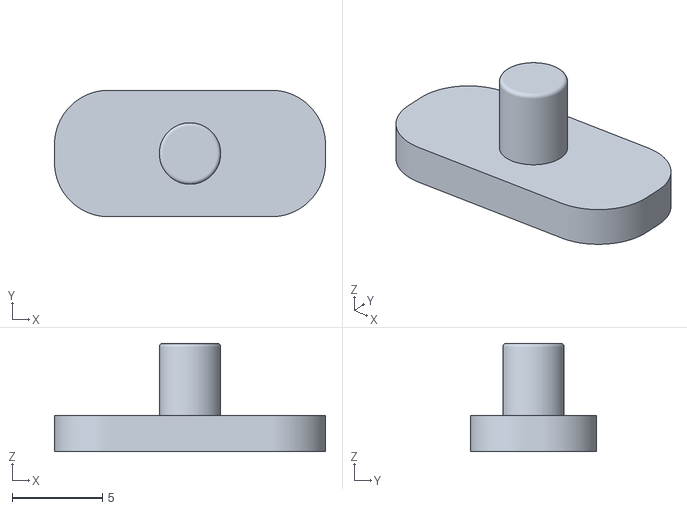
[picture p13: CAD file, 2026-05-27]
models/power_switch_knob.stl
15.0 x 7.00 x 6.00

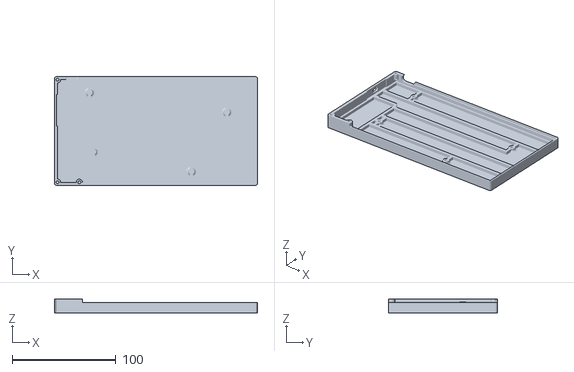
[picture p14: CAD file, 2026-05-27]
models/base_case_right.stl
196.0 x 105.0 x 13.5

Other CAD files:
models/top_cover_right_no_indicator_hole.stl
models/top_cover_left.stl

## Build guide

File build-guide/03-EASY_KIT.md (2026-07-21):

# CLEAVE HHJP お手軽キット組み立てガイド

[目次に戻る](README.md)

お手軽キットは、電子部品の実装とファームウェアの書き込みが完了した状態で届きます。このガイドでは、付属のケースへ基板を組み込みます。

## 目次

- [キット内容](#キット内容)
- [ケースの構成](#ケースの構成)
- [組み立て前の状態確認](#組み立て前の状態確認)
- [組み立て手順](#組み立て手順)
- [参考: 完成状態](#参考-完成状態)

## キット内容

部品一覧の画像はホワイト版です。基板、スペーサー、ネジなどは色違いの場合があります。

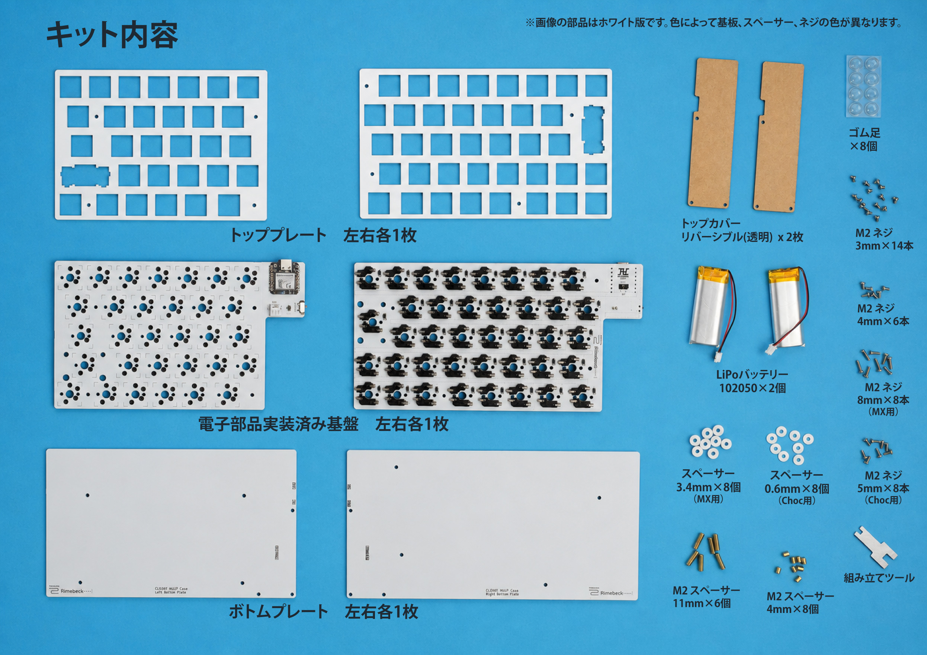
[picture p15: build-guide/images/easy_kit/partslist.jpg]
お手軽キットの内容


### キットに含まれるもの

| 部品名 | 数量 | 備考 |
|---|---:|---|
| 電子部品実装済み基板 | 左右各1枚 | ファームウェア書き込み・基板単体動作確認済み |
| トッププレート | 左右各1枚 | MX/Choc共通 |
| ボトムプレート | 左右各1枚 |  |
| トップカバー | 2枚 | リバーシブル、透明 |
| LiPoバッテリー 102050 | 2個 |  |
| M2スペーサー 4mm | 8個 | ボトムプレートと基板の固定用 |
| M2スペーサー 11mm | 6個 | ボトムプレートとトップカバーの固定用 |
| スペーサー 3.4mm | 8個 | MXスイッチ使用時 |
| スペーサー 0.6mm | 8個 | Chocスイッチ使用時 |
| M2 3mmネジ | 14本 |  |
| M2 4mmネジ | 6本 | トップカバー固定用 |
| M2 8mmネジ | 8本 | MXスイッチ使用時 |
| M2 5mmネジ | 8本 | Chocスイッチ使用時 |
| ゴム足 | 8個 |  |
| 組み立てツール | 1個 | 六角スペーサー押さえ・バッテリーコネクタ外し |

### 組み立てツールの使い方

付属の組み立てツールは、六角スペーサーの固定とバッテリーコネクタの取り外しに使用します。

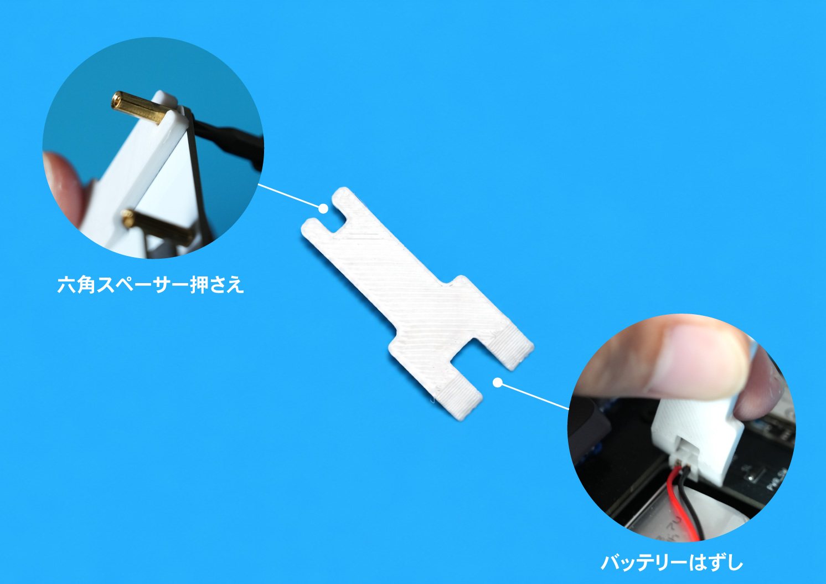
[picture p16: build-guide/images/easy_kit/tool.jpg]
組み立てツールの六角スペーサー押さえとバッテリーコネクタ外しの使い方


- **六角スペーサー押さえ**：ネジを締める際に六角スペーサーを挟み、空回りしないように押さえます。

> [!IMPORTANT]
> 組み立てツールは、六角スペーサーを回すためのスパナではありません。ツールでスペーサーを押さえ、反対側のM2ネジをプラス精密ドライバーで締めてください。ツールは樹脂製のため、スパナのように回してトルクをかけると溝が広がり、スペーサーを保持できなくなるおそれがあります。

- **バッテリーコネクタ外し**：ツールをコネクタのハウジングに掛け、基板に対してまっすぐ引き抜きます。ケーブルを持って引っ張らないでください。

### 別途用意するもの

#### 部品・材料

| 必要性 | 部品・材料 | 数量 | 備考 |
|---|---|---:|---|
| 必須 | 両面テープ | 適量 | スペーサーとバッテリーの固定用 |
| 必須 | お好みのMXまたはChocキースイッチ | 70個 |  |
| 必須 | お好みのMXまたはChocキーキャップ | 70個分 | JIS配列 |

#### 道具

| 必要性 | 道具 | 数量 | 備考 |
|---|---|---:|---|
| 必須 | プラス精密ドライバー | 1本 |  |
| 任意 | ピンセット | 1本 | 両面テープの貼り付けに使用 |

## ケースの構成

ケースは、ボトムプレートとトッププレートでPCBを挟み込む「サンドイッチ構造」です。加えてトップカバーなどを組み合わせて作成します。

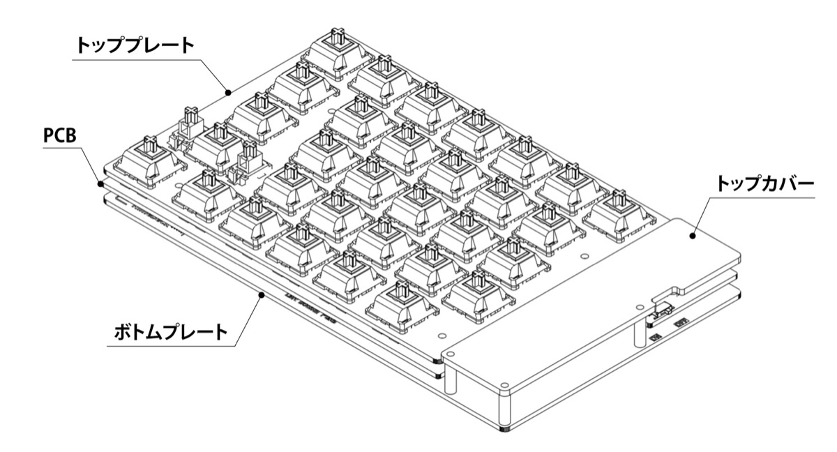
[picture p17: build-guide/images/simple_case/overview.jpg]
ケースの概略図


## 組み立て前の状態確認

お手軽キットは、基板の電子部品実装、ファームウェア書き込み、基板単体での動作確認が完了しています。組み立てを始める前に、以下を確認してください。

- USBケーブルを基板から外している
- 左右の電源スイッチがOFFになっている
- バッテリーを接続していない

## 組み立て手順

> [!NOTE]
> **左右両方で作業してください**
>
> このガイドでは写真が左側のみ掲載されている場合がありますが、特に記載がない限り、同じ手順を左右の両方で行ってください。

### 1. 部品の確認

「キット内容」に記載した付属部品と、別途用意する部品・材料・道具が揃っていることを確認します。

MXスイッチを使用する場合は3.4mmスペーサーとM2 8mmネジ、Chocスイッチを使用する場合は0.6mmスペーサーとM2 5mmネジを使用します。

**完了チェック**

- [ ] 組み立てに必要な部品・材料・道具をすべて用意した
- [ ] 使用するスイッチに合ったスペーサーとネジを確認した

### 2. スペーサーネジの取り付け

ボトムプレートの印字がされている面に、M2スペーサー 4mmとM2スペーサー 11mmを配置し、それぞれ裏面からM2 3mmネジで固定します。
4mmと11mmの取り付け位置は下図を参考にしてください。

緑色：4mm / オレンジ色：11mm

#### 右側

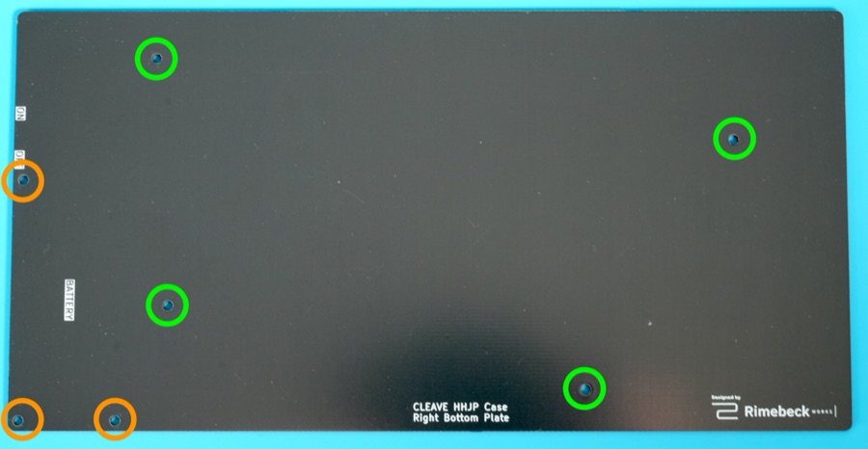
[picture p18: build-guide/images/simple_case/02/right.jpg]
右側スペーサー取り付け


#### 左側

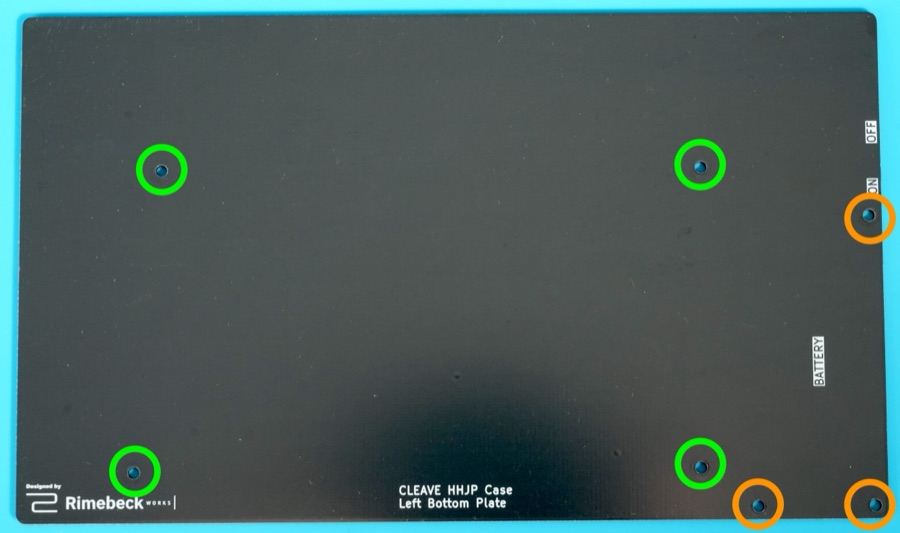
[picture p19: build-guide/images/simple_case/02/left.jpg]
左側スペーサー取り付け


このステップが完了すると以下のようになります。

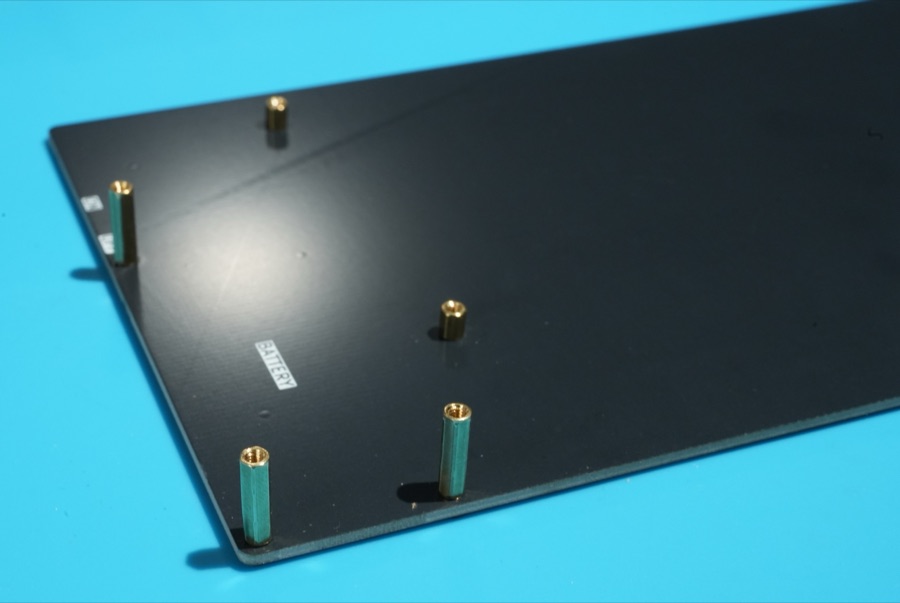
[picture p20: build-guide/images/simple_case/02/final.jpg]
ボトムプレートにスペーサーを取り付けた状態


**完了チェック**

- [ ] 4mmスペーサーを全8箇所取り付けた
- [ ] 11mmスペーサーを全6箇所取り付けた

### 3. スペーサーの取り付け

トッププレートの裏面（文字が印字してある面）に、使用するスイッチに合ったスペーサーを取り付けます。

- MX互換スイッチ：3.4mmスペーサー
- ChocV1/V2互換スイッチ：0.6mmスペーサー

ネジ穴を塞がないように両面テープでトッププレートとスペーサーを貼り付けます。穴とスペーサーにネジを通して位置決めすると、正確に貼り付けられます。

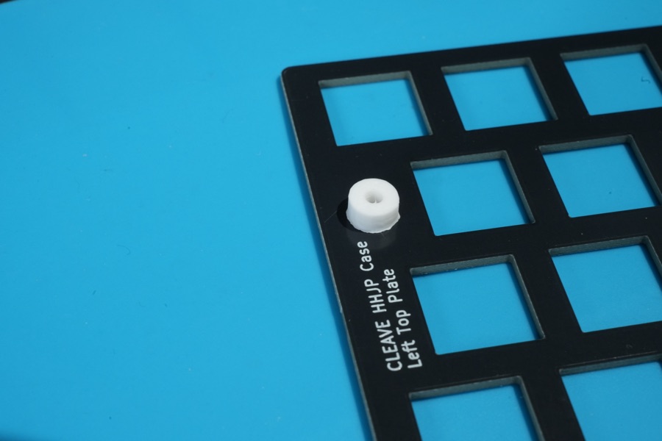
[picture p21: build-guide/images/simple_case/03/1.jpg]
トッププレートにスペーサーを貼り付けた状態


> [!NOTE]
> 画像はわかりやすいようにトッププレートとスペーサーの色を変えていますが、実際にはトッププレートと同系色のスペーサーが付属します。

**完了チェック**

- [ ] 使用するスイッチに応じたスペーサーを全8箇所取り付けた

### 4. キースイッチ取り付け

MX互換スイッチまたはChocV1/V2互換スイッチをトッププレートにはめ込みます。

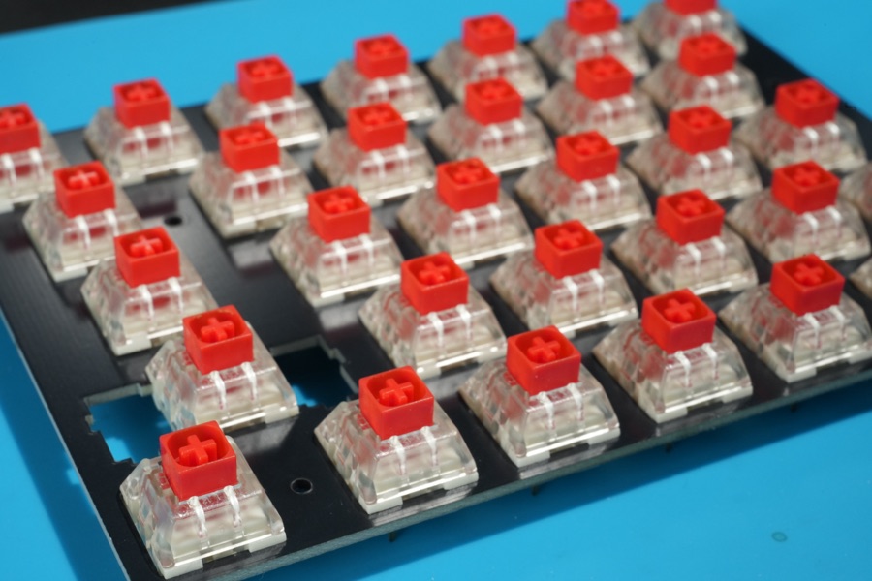
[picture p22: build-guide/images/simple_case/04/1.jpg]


PCBを確認しながら、スイッチの上下の向きに注意してください。

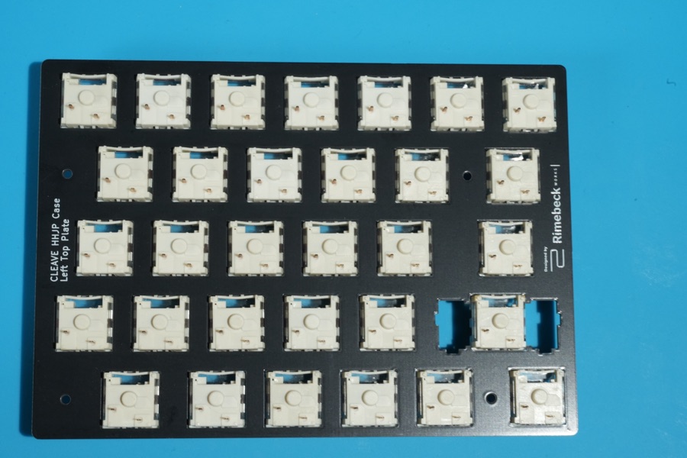
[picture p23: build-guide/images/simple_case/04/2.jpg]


> [!NOTE]
> 右側エンターキーのみ、スタビライザー穴の都合上スイッチが保持されづらくなっています。そのスイッチのみ次のステップで取り付けても問題ありません。

**完了チェック**

- [ ] 70個のスイッチがトッププレートにはまっている
- [ ] スイッチの向きが正しい

### 5. トッププレートの取り付け

MXスタビライザーを使う場合は、このタイミングでPCBへ取り付けます。トッププレートやPCBと干渉しないことを確認しながら、PCBの左右それぞれにスタビライザーをはめ込みます。

PCBにスイッチを差し込みながらトッププレートとPCBを組み合わせます。一気に差し込まず、端のスイッチから徐々にソケットへ差し込んでください。スペーサーがずれないように注意します。

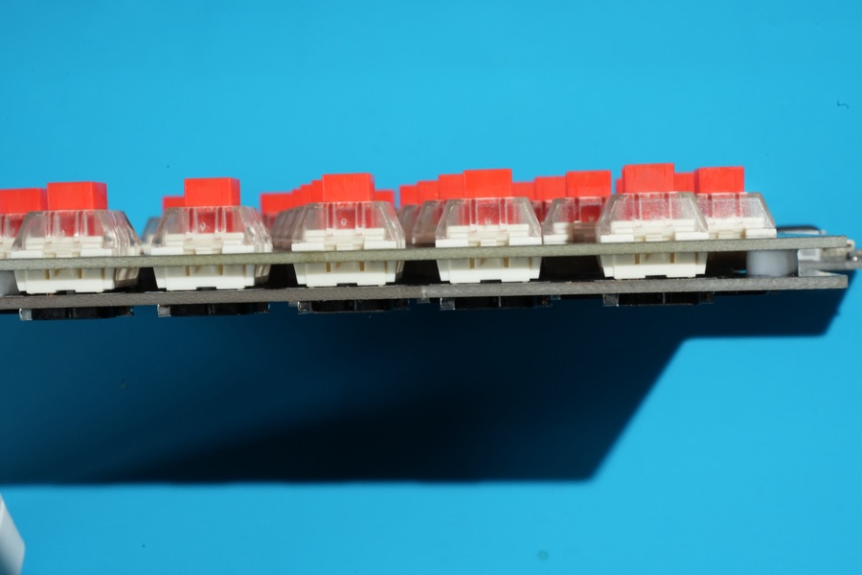
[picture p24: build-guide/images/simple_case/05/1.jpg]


> [!NOTE]
> Chocスイッチを使用する場合、PCBとトッププレートの隙間が微小になりますが、接触することはありません。接触している場合は、スイッチがトッププレートに完全にはまっていない状態のことがあります。
>
> 参考画像：
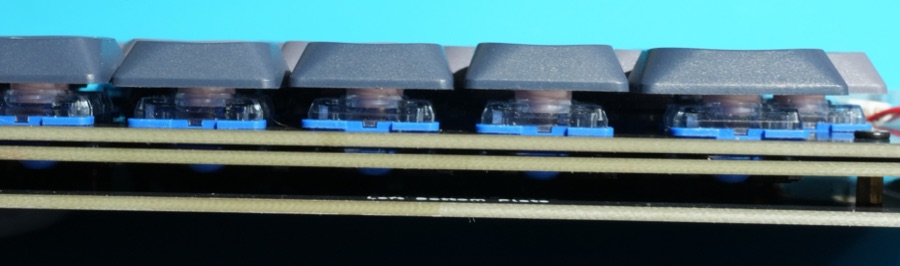
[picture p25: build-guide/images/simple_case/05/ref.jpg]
> 

スイッチのピンが折れ曲がらないように注意します。PCBを裏返して、ソケットにピンが正常に差し込まれていることを確認します。

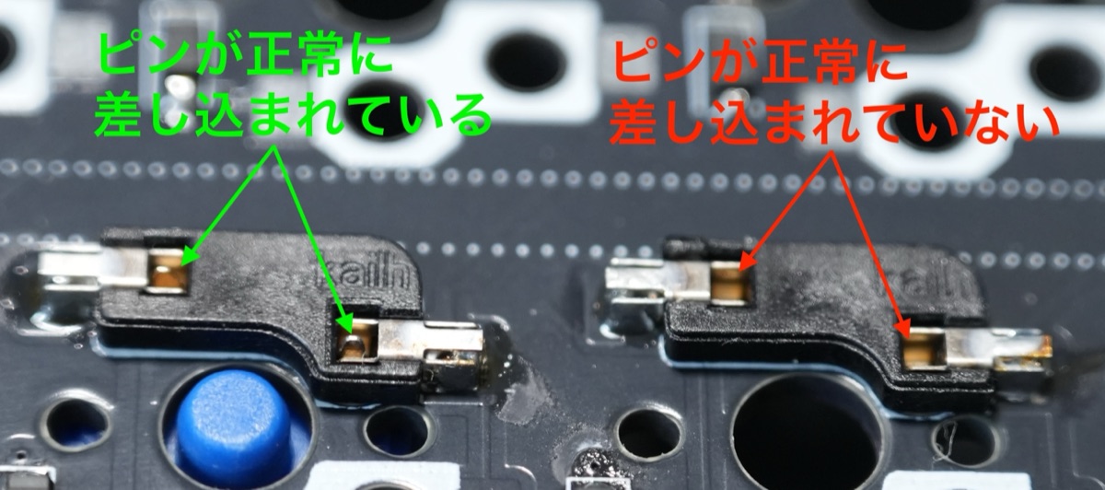
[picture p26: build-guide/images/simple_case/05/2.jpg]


完了すると以下のようになります。

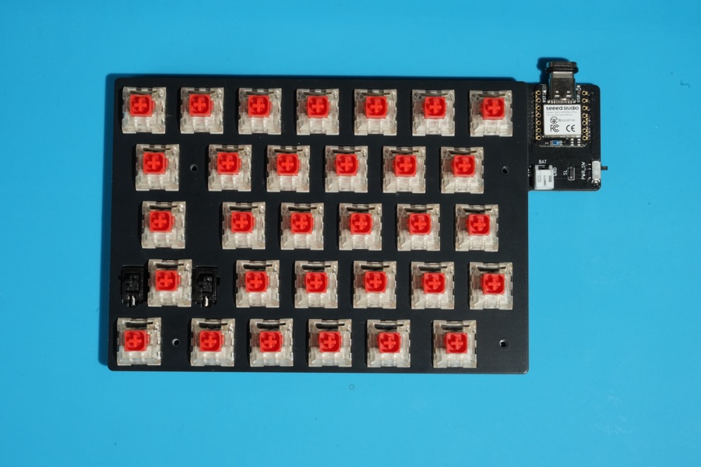
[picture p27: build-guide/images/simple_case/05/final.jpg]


**完了チェック**

- [ ] スイッチがトッププレートとPCBの両方に正しく入っている
- [ ] スイッチのピンが曲がらず、PCBのソケットに入っている

### 6. PCBの取り付け

M2スペーサー 4mmを取り付けたボトムプレートに、PCB、トッププレート、キースイッチが一体になった部品を装着します。

- MX互換スイッチ：M2 8mmネジ
- ChocV1/V2互換スイッチ：M2 5mmネジ

トッププレートのネジ穴とボトムプレートの4mmスペーサーの位置を合わせ、左右それぞれ4箇所をトッププレート側からネジ止めします。組み立てツールは回さず、六角スペーサー押さえでスペーサーを固定したまま、反対側のM2ネジをプラス精密ドライバーで締めてください。

**完了チェック**

- [ ] 左右それぞれ4箇所を、使用するスイッチに合ったM2ネジで固定した
- [ ] ネジを締めすぎてケースやトッププレートが変形していない

### 7. バッテリーの固定

USBケーブルを抜き、電源スイッチがOFFになっていることを再確認します。LiPoバッテリーをコネクタに差し込み、ボトムプレートの「BATTERY」と記載された部分に両面テープで貼り付けます。

| シルクスクリーンの印刷 | 極性 |
|---|---|
| BAT+ | 正極（赤色のケーブル） |
| GND | 負極（黒色のケーブル） |

> [!CAUTION]
> LiPoバッテリーはショートや強い曲げ、穴あき、圧迫で発熱・発火する可能性があります。赤黒のリード線やコネクタ端子を金属工具で同時に触れないでください。バッテリーやケーブルがネジ穴、トップカバー、PCBに挟まれないことも確認してください。

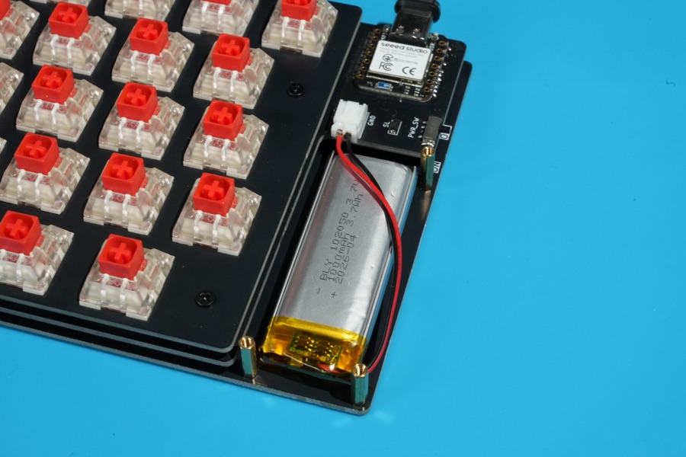
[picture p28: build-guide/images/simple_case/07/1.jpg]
バッテリーをケース内のスペースに収めた状態


**完了チェック**

- [ ] バッテリーコネクタが奥まで差し込まれている
- [ ] `BAT+`に赤色のケーブル、`GND`に黒色のケーブルが接続されている
- [ ] バッテリーがケース内のスペースに収まっている
- [ ] バッテリーやケーブルがトップカバー、PCBなどに挟まれない
- [ ] バッテリーがケース内で動かないように固定されている

### 8. トップカバーの取り付け

トップカバーの裏表の保護フィルムを剥がし、透明な状態にします。左右それぞれ3箇所をM2 4mmネジで固定します。

組み立てツールは回さず、六角スペーサー押さえでスペーサーを固定したまま、反対側のM2ネジをプラス精密ドライバーで締めてください。

> [!NOTE]
> トップカバーはリバーシブルです。左右どちらにも同じトップカバーを裏返して取り付けられます。

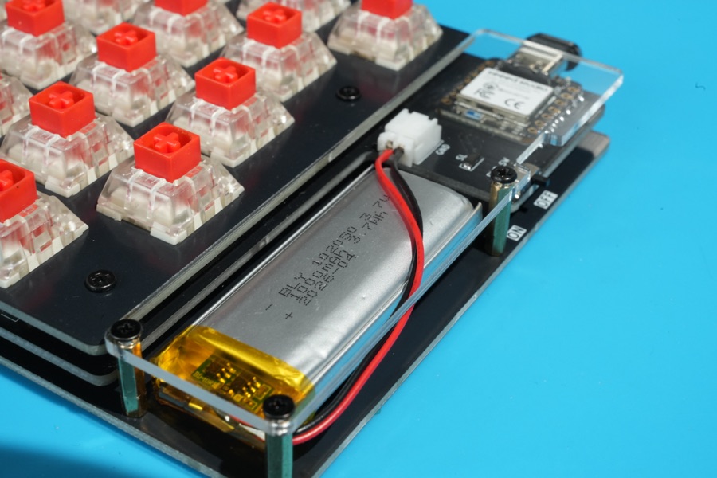
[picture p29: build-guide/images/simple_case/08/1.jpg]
トップカバーの取り付け


**完了チェック**

- [ ] トップカバーを左右それぞれ3箇所のM2 4mmネジで固定した

### 9. ゴム足の取り付け

本体を裏返して、ボトムプレートの四隅にゴム足を貼り付けます。ネジを避けて貼り付けてください。

キーボードに傾斜を付けたい場合は、奥側のみに貼り付けることもできます。

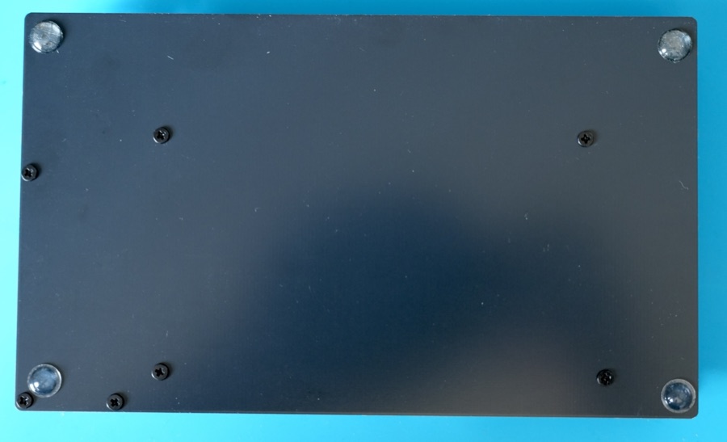
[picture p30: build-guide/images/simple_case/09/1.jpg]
ゴム足の取り付け


**完了チェック**

- [ ] ゴム足を貼り、キーボードを置いたときにがたつきがない

## 参考: 完成状態

ケースの組み立てが完了すると、以下のような状態になります。お好みのキーキャップを取り付ければ使用準備は完了です。

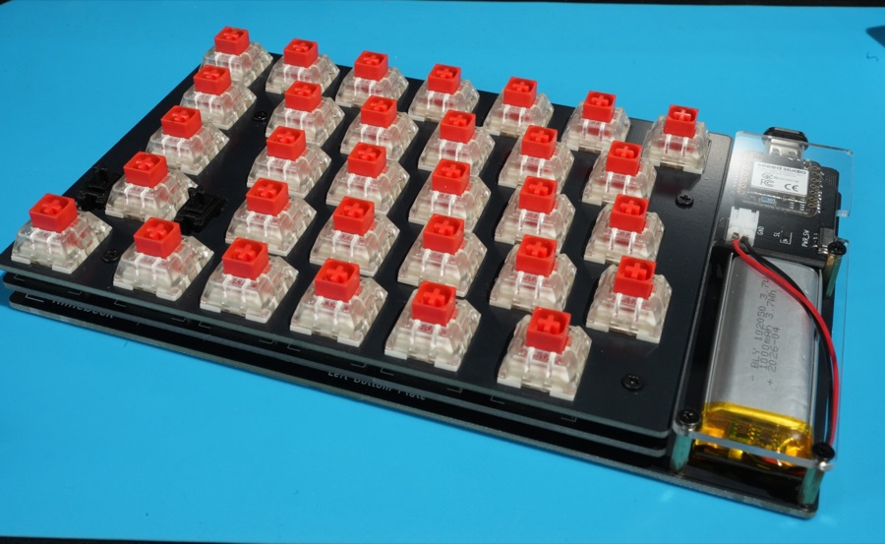
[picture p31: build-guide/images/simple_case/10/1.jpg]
完成状態


## ステップの完了

お手軽キットの組み立てが完了しました。次のガイドでキーボードの使い方を確認してください。

- [次: 完成後の使い方](04-USAGE.md)
- [目次に戻る](README.md)

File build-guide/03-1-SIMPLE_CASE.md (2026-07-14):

# CLEAVE HHJP 簡易ケースビルドガイド

[目次に戻る](README.md)

簡易ケースキットを使用して、CLEAVE HHJP のケースを作成する方法について説明します。

## 目次

- [ケースの構成](#ケースの構成)
- [ケース組み立て前の状態確認](#ケース組み立て前の状態確認)
- [ケース組み立て手順](#ケース組み立て手順)
- [参考: 完成状態](#参考-完成状態)

## ケースの構成

簡易ケースは、ボトムプレートとトッププレートでPCBを挟み込む「サンドイッチ構造」のケースです。加えてトップカバーなどを組み合わせて作成します。

簡易ケースの概略図

## ケース組み立て前の状態確認

基板単体でのファームウェア書き込みと動作確認が済んだら、以下の状態に応じてケースへ組み込みます。

| 現在の状態 | 進め方 |
|---|---|
| 前のステップで動作確認のためにキースイッチやバッテリーを取り付けている | いったんスイッチやバッテリーを外してください。このガイドで他の部品と組み合わせて組み立て直します。 |
| キースイッチやバッテリーをまだ取り付けていない | このガイドの手順に沿って進めてください。 |

## ケース組み立て手順

> [!NOTE]
> **左右両方で作業してください**
>
> このガイドでは写真が左側のみ掲載されていますが、特に記載がない限り、同じ手順を左右の両方で行ってください。

### 1. 簡易ケース部品の確認
組み立てを始める前に、以下の簡易ケースキットの内容物、本体キットから流用する部品、別途用意する材料・道具が揃っていることを確認します。

#### 簡易ケースキットの内容物
| 部品名 | 数量 | 備考 |
|---|---|---|
|ボトムプレート|左右各1枚||
|トッププレート|左右各1枚||
|トップカバー|2枚||
|スペーサー M2ネジ付き 4mm|8個|ボトムケース - 基板|
|スペーサー M2ネジ付き 11mm|6個|ボトムケース - トップカバー|
|スペーサー ネジなし 3.4mm|8個|MXスイッチ使用時 / 3Dプリント品|
|スペーサー ネジなし 0.6mm|8個|Chocスイッチ使用時 / 3Dプリント品|
|M2 3mmネジ|14本||
|M2 5mmネジ|8本|Chocスイッチ使用時|
|ゴム足|8個||

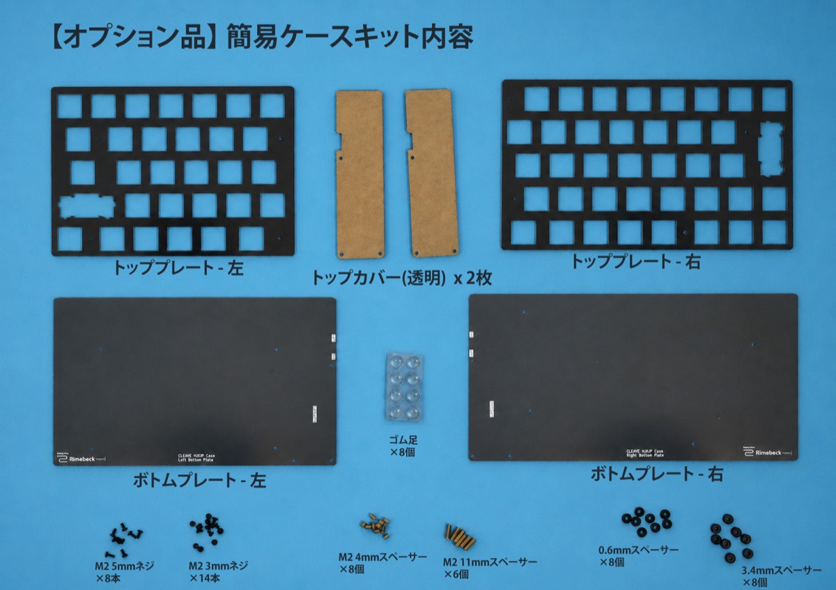
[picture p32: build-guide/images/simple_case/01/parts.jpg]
簡易ケースキット内容


#### 本体キットの標準ケース用部品から流用する部品
| 部品名 | 数量 | 備考 |
|---|---|---|
|M2 4mmネジ|6本|トップカバー固定用|
|M2 8mmネジ|8本|MXスイッチ使用時|

> [!NOTE]
> 簡易ケースでは、トッププレート固定用のネジ長が標準ケースと異なります。MX互換スイッチではM2 8mmネジ、ChocV1/V2互換スイッチではM2 5mmネジを使用します。

#### 別途用意する材料
| 部品名 | 数量 | 備考 |
|---|---|---|
|両面テープ（0.1mm厚程度）|適量|スペーサー固定用|

#### 別途用意する道具
| 道具名 | 数量 | 備考 |
|---|---|---|
|プラス精密ドライバー|必須||
|ピンセット|任意||
|スパナ・ラジオペンチ|任意|対辺3mmの六角スペーサーを保持できるもの|

**完了チェック**

- [ ] 簡易ケース組み立てに必要な部品・道具をすべて用意した

### 2. スペーサーネジの取り付け
ボトムプレートの印字がされている面にスペーサー M2ネジ付き 4mmとスペーサー M2ネジ付き 11mmを配置し、それぞれ裏面からM2 3mmネジで固定します。
4mmと11mmどちらを取り付けるかは下記の図を参考にしてください。

緑色：4mm / オレンジ色：11mm

#### 右側
右側スペーサー取り付け

#### 左側
左側スペーサー取り付け

このステップが完了すると以下のようになります。

ボトムプレートにスペーサーを取り付けた状態

**完了チェック**

- [ ] 4mm スペーサーを全8箇所取り付けた
- [ ] 11mmスペーサーを全6箇所取り付けた

### 3. スペーサーの取り付け
トッププレートの裏面（文字が印字してある面）にスペーサーを取り付けます。
- MX互換スイッチを使用する場合は3.4mm 
- ChocV1/V2互換スイッチを使用する場合は0.6mm

のスペーサーを使用します。ネジ穴を塞がないように両面テープでトッププレートとスペーサーを貼り付けます。
このときに穴とスペーサーにネジを通して位置決めをすると正確に貼り付けることができます。

トッププレートにスペーサーを貼り付けた状態

> [!NOTE]
> 画像はわかりやすいようにトッププレートとスペーサーの色を変えていますが、実際にはトッププレートと同系色のスペーサーが提供されます。

**完了チェック**

- [ ] 使用するスイッチに応じたスペーサーを全8箇所取り付けた

### 4. キースイッチ取り付け
MX互換スイッチとChocV1/V2互換スイッチのどちらかをトッププレートにはめ込みます。

トッププレートにキースイッチを取り付けた状態

PCBを確認しながらスイッチの上下の向き（ピンが上下どちらに位置するか）に注意してください。

トッププレートにキースイッチを取り付けた状態

> [!NOTE]
> 右側エンターキーのみスタビライザー穴の都合上スイッチが保持されづらくなっています。そのスイッチのみ次のステップで取り付けても問題ありません。

**完了チェック**

- [ ] スイッチがトッププレートにはまっており、向きが正しい

### 5. トッププレートの取り付け
**MXスタビライザーを使う場合はこのタイミングでPCBへ取り付けます。トッププレートやPCBと干渉しないことを確認しながらPCBの左右それぞれにスタビライザーをはめ込みます。**

PCBにスイッチを差し込みながらトッププレートとPCBを組み合わせます。
一気に差し込むのではなく、端のスイッチから徐々にソケットに差し込むと安定的に差し込めます。
スペーサーがずれないように注意してください。

PCBとトッププレートでキースイッチを挟み込んだ状態

> [!NOTE]
> Chocスイッチを使用する場合、PCBとトッププレートの隙間が微小になりますが、接触することはありません。
> 接触している場合はスイッチがトッププレートに完全にはまっていない状態なので完全にはめ込んでください。
> 参考画像：
> PCBとトッププレートでキースイッチを挟み込んだ状態

このときにスイッチのピンが折れ曲がらないように注意します。PCBを裏返してソケットにピンが正常に差し込まれているか確認できます。

PCBとトッププレートでキースイッチを挟み込んだ状態

完了すると以下のようになります。（MXスイッチ、スタビライザーありの場合）

PCBとトッププレートでキースイッチを挟み込んだ状態

**完了チェック**

- [ ] スイッチがトッププレートとPCBの両方に正しく入っている
- [ ] スイッチのピンが曲がらず、PCBのソケットに入っている

### 6. PCBの取り付け
「2. スペーサーネジの取り付け」でネジ付きスペーサーを装着したボトムプレートにPCBとトッププレートとキースイッチが一体になった部品を装着します。

- MX互換スイッチを使用する場合はM2 8mmネジ（本体キットの標準ケース用部品を流用）
- ChocV1/V2互換スイッチを使用する場合はM2 5mmネジ

を使用します。

トッププレートのネジ穴とボトムプレートの4mmスペーサーの位置が合うように調整し、左右それぞれ4箇所をトッププレート側からネジ止めします。
このときにネジ付きスペーサーが緩まないようにスパナやラジオペンチなどで押さえながら取り付けると確実にネジを締め付けることができます。

**完了チェック**

- [ ] 左右それぞれ4箇所を、使用するスイッチに合った長さのM2ネジで固定した
- [ ] ネジを締めすぎてケースやトッププレートが変形していない

### 7. バッテリーの固定
バッテリーをコネクタに差し込み、ボトムプレートの「BATTERY」と記載のある部分に両面テープで貼り付けます。

|シルクスクリーンの印刷|極性|
|---|---|
|BAT+|正極（赤色のケーブル）|
|GND|負極（黒色のケーブル）|

> [!CAUTION]
> LiPoバッテリーはショートや強い曲げ、穴あき、圧迫で発熱・発火する可能性があります。接続作業中はUSBケーブルを抜き、電源スイッチをOFFにします。赤黒のリード線やコネクタ端子を金属工具で同時に触れないでください。
> バッテリーの極性を間違えて接続するとマイコンが壊れて修復不能になる場合があります。バッテリーやケーブルがネジ穴、トップカバー、PCBに挟まれないことも確認してください。

バッテリーをケース内のスペースに収めた状態

**完了チェック**

- [ ] バッテリーコネクタが奥まで差し込まれている
- [ ] `BAT+`に赤色のケーブル、`GND`に黒色のケーブルが接続されている
- [ ] バッテリーがケース内のスペースに収まっている
- [ ] バッテリーやケーブルがトップカバー、PCBなどに挟まれない
- [ ] バッテリーがケース内で動かないように固定されている

### 8. トップカバーの取り付け
裏表の保護フィルムを剥がして透明なアクリルの状態にしたトップカバーを左右それぞれ3箇所のM2 4mmネジ（本体キットの標準ケース用部品を流用）で固定します。
このときにネジ付きスペーサーが緩まないようにスパナやラジオペンチなどで押さえながら取り付けると確実にネジを締め付けることができます。

> [!NOTE]
> トップカバーはリバーシブルです。左右どちらにも同じトップカバーを裏返して取り付けることができます。

トップカバーの取り付け

**完了チェック**

- [ ] トップカバーを左右それぞれ3箇所のM2 4mmネジで固定した

### 9. ゴム足の取り付け
本体を裏返してボトムプレートにゴム足を貼り付けます。ネジを避けてボトムプレートの四隅に貼り付けます。
キーボードに傾斜を付けたい場合は奥側のみに貼り付けることもできます。お好みに応じて位置や個数を変更してください。

ゴム足の取り付け

**完了チェック**

- [ ] ゴム足を貼り、キーボードを置いたときにがたつきがないことを確認した

## 参考: 完成状態
ケースの組み立てが完了すると、以下のような状態になります。
お好みのキーキャップを取り付ければ使用準備は完了です。

完成状態

## ステップの完了
ついにキーボードが完成しました。
次のガイドではこのキーボードの使い方を確認しましょう。
- [前: ファームウェアのダウンロード・書き込み・接続確認](02-FIRMWARE.md)
- [次: 完成後の使い方](04-USAGE.md)
- [目次に戻る](README.md)

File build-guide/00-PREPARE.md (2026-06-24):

# CLEAVE HHJP 準備ガイド

[目次に戻る](README.md)

CLEAVE HHJP を組み立てる前に、購入・発注・作業環境の準備をまとめて行うためのガイドです。
基板組み立てとケース組み立ての各ガイドでは、このガイドで用意した部品を使って作業する前提で説明します。

## 目次

- [購入・発注前に決めること](#購入発注前に決めること)
- [用意する道具](#用意する道具)
- [電子部品・基板まわり](#電子部品基板まわり)
- [キースイッチ関連](#キースイッチ関連)
- [ケース関連](#ケース関連)
- [準備完了チェック](#準備完了チェック)

## 購入・発注前に決めること

部品を購入・発注する前に、以下を決めておくと必要なものをまとめて揃えやすくなります。

| 決めること | 選択肢 | 影響するもの |
|---|---|---|
| 使用するキースイッチ | MX互換 / ChocV1・V2互換 / 両対応 | ホットスワップソケット、キースイッチ、キーキャップ、トッププレート、トッププレート固定ネジ |
| ケース作成方法 | 標準ケース（3Dプリント） / 簡易ケースキット / オリジナルケースを設計 | ケース部品、ケース部材、参照するケースガイド |
| 標準ケース選択時の部品用意方法と素材 | 自家プリント / 3Dプリントサービス（JLC3DP等）に発注 | 標準ケース用3Dプリント部品、ケース部材 |
| 標準ケース選択時のトップカバータイプ | インジケーター穴あり / 穴なし | トップカバーのモデル、透明プラ棒の有無 |
| MX用スタビライザー | 使う / 使わない | 2Uスタビライザー |

> [!TIP]
> MXとChocの両方に対応させたい場合は、MX用とChoc用のホットスワップソケットを両方実装します。
> 完成後に切り替えるには、交換先のスイッチ、キーキャップ、トッププレート、対応する長さのM2ネジも必要です。

## 用意する道具

| 道具 | 説明 |
|---|---|
| はんだごてセット | 基板部品のはんだ付けと、ベースケースへのインサートナット熱圧入に使用します。 |
| 先細ピンセット | 小さいチップ部品を扱うために使用します。 |
| マスキングテープ | スルーホールタイプの部品をはんだ付けする際の固定に使用します。 |
| テスター | 電気的な導通テストやバッテリー極性の確認に使用します。必須ではありませんが、強く推奨します。 |
| 精密ドライバー | ケース組み立て時にM2ネジを締めるために使用します。 |
| ニッパーまたはカッター | フォームテープ、滑り止め、透明プラ棒の長さ調整に使用します。 |
| USB Type-Cケーブル | ファームウェアの書き込み、動作確認、充電に使用します。 |

## 電子部品・基板まわり

キットには、基板、基板実装用の電子部品、ケース組み立て用のネジ類などが含まれます。下の表で、キット付属品と別途用意する部品を確認してください。

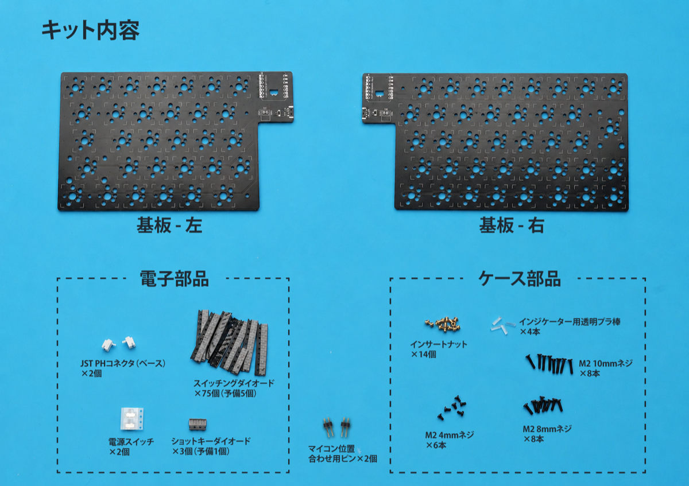
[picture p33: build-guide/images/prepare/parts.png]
CLEAVE HHJPのキット内容


CLEAVE HHJPをキーボードとして動作させるために最低限必要な部品は以下の通りです。

| 役割 | 部品名 | 数量 | キット付属 | 備考 |
|---|---|---|---|---|
| 基板 | CLEAVE HHJP 基板 - 右 | 1 | ◯ |  |
| 基板 | CLEAVE HHJP 基板 - 左 | 1 | ◯ |  |
| 電源スイッチ | MSK-12C02 2.5H | 2 | ◯ | ノブが高い2.5Hを推奨 |
| スイッチングダイオード | 1N4148W (SOD-123) | 70 | ◯ | チップ表面に「T4」と表記があるもの |
| ショットキーバリアダイオード | B5819W (SOD-123) | 2 | ◯ | チップ表面に「SL」と表記があるもの |
| バッテリーコネクタ | PHコネクター ベース付ポスト サイド型 2P | 2 | ◯ |  |
| 位置合わせ用 | 1x2ピンヘッダ（2.54mmピッチ） | 2 | ◯ | XIAO nRF52840 Plus実装時の位置合わせに一時的に使用します。本実装には使用しません。ロットによりXIAO nRF52840 Plusに付属していることがあります。 |
| バッテリー | LiPoバッテリー JST PHコネクタ付き | 2 |  | 標準ケース・簡易ケースキットは最大102050サイズ（厚み10mm × 幅20mm × 長さ50mm）のバッテリーまで対応。購入先例: [Amazon](https://www.amazon.co.jp/dp/B0GFD6DQPP) |
| マイコンボード | XIAO nRF52840 Plus | 2 |  | 左右両側に1個ずつ。"Plus"が必要です。購入先例: [スイッチサイエンス](https://www.switch-science.com/products/10468) / [遊舎工房](https://shop.yushakobo.jp/products/10946) / [seeedstudio公式ストア](https://jp.seeedstudio.com/Seeed-Studio-XIAO-nRF52840-Plus-p-6359.html) |

## キースイッチ関連

CLEAVE HHJPは、MX互換スイッチとChocV1/V2互換スイッチの両方に対応しており、1つの基板にMX用とChoc用の両方のホットスワップソケットを実装しておくと、一度組み立てた後も気分によって切り替えることも可能です。
使うスイッチのタイプに応じて、以下の部品を用意してください。

### MX互換スイッチを使用する場合

| 役割 | 部品名 | 数量 | 備考 |
|---|---|---|---|
| ホットスワップソケット | CPG151101S11 | 70 | 購入先例: [Amazon](https://www.amazon.co.jp/dp/B0BVH64NXR) |
| キースイッチ | MX互換 | 70 |  |
| キーキャップ | MX互換 | 70個分 | キーレイアウトに合わせて用意します。 |
| スタビライザー | PCBマウント2U | 2 | 任意。購入先例: [遊舎工房](https://shop.yushakobo.jp/products/a0500st) |

### ChocV1/V2互換スイッチを使用する場合

| 役割 | 部品名 | 数量 | 備考 |
|---|---|---|---|
| ホットスワップソケット | CPG135001S30 | 70 | 購入先例: [遊舎工房](https://shop.yushakobo.jp/products/a01ps?variant=37665172553889) |
| キースイッチ | ChocV1/V2 | 70 |  |
| キーキャップ | 使用するChocスイッチのステムに合うキーキャップ | 70個分 | キーレイアウトに合わせて用意します。 |

## ケース関連

CLEAVE HHJP のケース作成方法は、標準ケース、簡易ケースキット、オリジナルケースの3つです。
どの方法を選ぶかによって、準備するケース部品や参照するガイドが変わります。

| 方法 | 説明 | 用意するもの | 参照先 |
|---|---|---|---|
| 標準ケース（3Dプリント） | 配布されているSTLを3Dプリントしてケースを作成する方式です。 | 配布STL、3Dプリント部品、インサートナット、M2ネジ、フォームテープなど | [標準ケースビルドガイド](03-0-STANDARD_CASE.md) |
| 簡易ケースキット | ボトムプレートとトッププレートでPCBを挟み込む、サンドイッチ構造のケースキットを使う方式です。 | 簡易ケースキット、M2ネジ、スペーサー固定用の両面テープなど | [簡易ケースビルドガイド](03-1-SIMPLE_CASE.md) |
| オリジナルケース（STEP参照） | PCB外形STEPデータを元に、自分でケース構造を設計・製作する方式です。 | PCB外形STEPデータ、CAD環境、独自に設計・製作したケース部品 | [オリジナルケース作成ガイド](03-2-CUSTOM_CASE.md) |

ここで決めたケース方式に応じて、ファームウェア書き込みと基板単体確認のあとに該当するケースガイドへ進みます。

### 標準ケース用3Dプリント部品

標準ケースを作る場合は、以下の3Dプリント部品を用意します。使用するキースイッチとトップカバーのタイプに合わせて、表の選択条件から必要なモデルを選びます。

後からMX/Chocを切り替えたい場合は、両方のトッププレートを用意しておきます。

| 部品 | モデルファイル | 必要数 | 選択条件 |
|---|---|---|---|
| 左ベースケース | [base_case_left.stl](../models/base_case_left.stl) | 1個 | 必須 |
| 右ベースケース | [base_case_right.stl](../models/base_case_right.stl) | 1個 | 必須 |
| 電源スイッチノブ | [power_switch_knob.stl](../models/power_switch_knob.stl) | **2個** | 必須 |
| 左トップカバー | [top_cover_left.stl](../models/top_cover_left.stl) | 1個 | インジケーター穴ありを選択する場合 |
| 右トップカバー | [top_cover_right.stl](../models/top_cover_right.stl) | 1個 | インジケーター穴ありを選択する場合 |
| 左トップカバー | [top_cover_left_no_indicator_hole.stl](../models/top_cover_left_no_indicator_hole.stl) | 1個 | 穴なし。透明樹脂などを使用する場合 |
| 右トップカバー | [top_cover_right_no_indicator_hole.stl](../models/top_cover_right_no_indicator_hole.stl) | 1個 | 穴なし。透明樹脂などを使用する場合 |
| 左MXトッププレート | [top_plate_mx_left.stl](../models/top_plate_mx_left.stl) | 1枚 | MX互換スイッチを使用する場合 |
| 右MXトッププレート | [top_plate_mx_right.stl](../models/top_plate_mx_right.stl) | 1枚 | MX互換スイッチを使用する場合 |
| 左Chocトッププレート | [top_plate_choc_left.stl](../models/top_plate_choc_left.stl) | 1枚 | ChocV1/V2互換スイッチを使用する場合 |
| 右Chocトッププレート | [top_plate_choc_right.stl](../models/top_plate_choc_right.stl) | 1枚 | ChocV1/V2互換スイッチを使用する場合 |

上の表から、決めた構成に対応するモデルを選んで3Dプリントします。
簡易ケースキットを使う場合は、ここに記載している標準ケース用3Dプリント部品は使用しません。キット内容物は[簡易ケースビルドガイド](03-1-SIMPLE_CASE.md#1-簡易ケース部品の確認)で確認してください。
オリジナルケースを作る場合は、[PCB外形STEPデータ](../models/pcb)を参照して独自に設計します。

### 標準ケースのベースケース素材の選び方

標準ケースの左右のベースケースは、ケース組み立て時にインサートナットをはんだごてで熱圧入するため、ベースケースには熱可塑性樹脂を選びます。
JLC3DPで発注する場合は、以下の印刷方法と材料が熱可塑性樹脂として使えます。

| 印刷方法 | 材料 |
|---|---|
| MJF | PA12-HP Nylon |
| MJF | PAC-HP Nylon |
| MJF | PA11-HP Nylon |
| SLS | 3301PA Nylon |
| SLS | 3201PA-F Nylon |
| SLS | 1172 Pro Nylon |
| FDM | PLA Plastic |
| FDM | ABS Plastic |
| FDM | ASA Plastic |
| FDM | PA12-CF Plastic（カーボンファイバー入りPA12） |
| FDM | TPU（実用的には非推奨） |

> [!TIP]
> 左右のベースケース素材はPA12-HP Nylonが強度と仕上がりのバランスがよくおすすめですが、ほかの候補と比べるとやや高めです。

> [!NOTE]
> ベースケースは薄く広い構造上、多少の反りが発生することがありますが、PCBをネジ止めすることにより矯正できる場合がほとんどです。
> 気になる場合はドライヤーなどで加熱することで多少の矯正効果が期待できます。

ベースケース以外のトップカバー、電源スイッチノブ、トッププレートはインサートナットを熱圧入しないため、SLA（レジン）やアクリルなど、見た目や加工方法に合わせて自由に選んで構いません。例えばトップカバーを8001レジン（透明や半透明）で印刷するとバッテリーやマイコンが透けて見えます。

### 標準ケースで3Dプリント部品以外に用意する部材

標準ケースでは、3Dプリントしたケース部品に加えて、以下の部材も必要になります。

| 役割 | 部品名 | 数量 | キット付属 | 備考 |
|---|---|---|---|---|
| インサートナット | M2xL3xOD3.2 | 14個 | ◯ |  |
| ネジ | M2 8mm | 8本 | ◯ | Chocトッププレート用 |
| ネジ | M2 10mm | 8本 | ◯ | MXトッププレート用 |
| ネジ | M2 4mm | 6本 | ◯ | トップカバー用 |
| インジケーターランプ | 直径2mm透明プラ棒（3mm程度） | 4本 | ◯ | インジケーター穴ありトップカバーを使う場合に使用。穴なしまたは透明トップカバーを使う場合は不要 |
| フォームテープ | フォームテープ2mm厚/~3mm幅 | 2m程度 |  | 購入例: [Amazon](https://www.amazon.co.jp/dp/B0CG9N7B5M)<br>購入例は幅5mmのため、半分程度に割いて使用します。 |
| バッテリー固定用両面テープ | 薄手の両面テープ | 2枚程度 |  | ケース内でバッテリーを固定するために使用します。 |
| 滑り止めシート | ポロンシートなど |  |  | 任意。購入例: [Amazon](https://www.amazon.co.jp/gp/product/B00G4682FY) |

## 準備完了チェック

- [ ] 使用するキースイッチの種類（MX / Choc / 両対応）を決めた
- [ ] ケース作成方法（標準ケース / 簡易ケースキット / オリジナルケース）を決めた
- [ ] 標準ケースを選ぶ場合は、ケース部品の用意方法（自家プリント / 3Dプリントサービスに発注）を決めた
- [ ] 標準ケースを選ぶ場合は、トップカバーのタイプ（インジケーター穴あり / 穴なし）を決めた
- [ ] 必要な工具とUSB Type-Cケーブルを用意した
- [ ] 必要な部品をすべて揃えた

準備ができたら、次のガイドに進んでください。

- [次: 基板組み立てガイド](01-ASSEMBLY.md)
- [目次に戻る](README.md)

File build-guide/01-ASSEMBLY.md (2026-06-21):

# CLEAVE HHJP 基板組み立てガイド

[目次に戻る](README.md)

このガイドでは、[準備ガイド](00-PREPARE.md)で用意した部品を基板へ実装します。
使用するキースイッチに対応したホットスワップソケット、XIAO nRF52840 Plus、LiPoバッテリーなどを手元に揃えてから作業を始めてください。

> [!NOTE]
> 電子部品実装済み版をご購入いただいた場合はこのガイドの「5. XIAO nRF52840 Plusのはんだ付け」と「バッテリーの接続（基板単体での動作確認準備）」のみ行ってください。

## 目次

- [組み立て手順](#組み立て手順)
- [テスターを使った導通テスト](#テスターを使った導通テスト)
- [バッテリーの接続（基板単体での動作確認準備）](#バッテリーの接続基板単体での動作確認準備)
- [ステップの完了](#ステップの完了)

## 組み立て手順

### 1. ホットスワップソケットのはんだ付け
基板のウラ面（CLEAVE HHJPのロゴが印刷されている方）を上にして置きます。
左右の基板で、使用するソケット種別ごとに合計70箇所（右39箇所、左31箇所）へホットスワップ用のソケットをはんだ付けします。
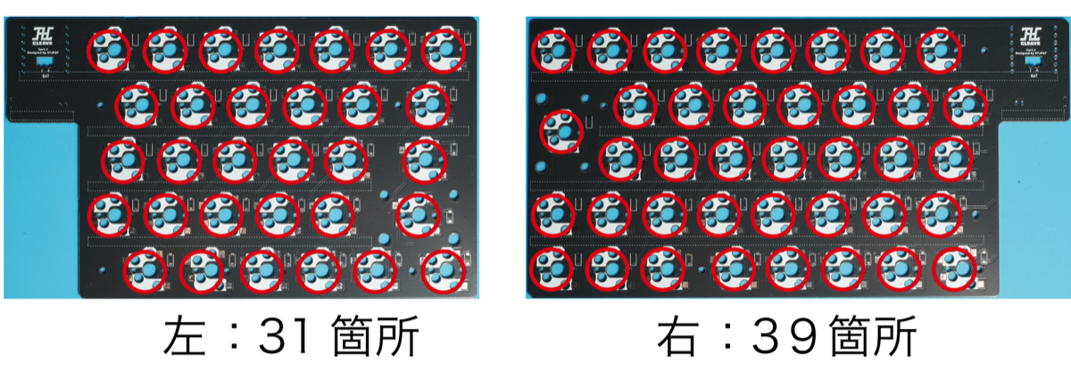
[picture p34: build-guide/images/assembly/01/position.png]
ホットスワップソケットの実装位置


MX/Choc両対応をする場合は、MX用70個とChoc用70個の両方を実装します。どちらかのみの場合は対応する片方のソケットを実装してください。
<u>Chocソケットはリバーシブルに見えますが、向きがあります。面取がされている方をシルクスクリーンに合わせて実装してください。</u>

| 取り付ける部品 | 取り付け基板箇所 |
|---|---|
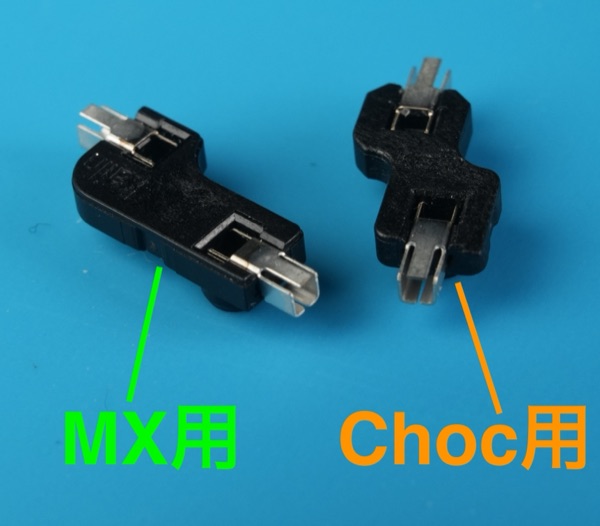
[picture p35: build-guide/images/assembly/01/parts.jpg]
ホットスワップソケット部品
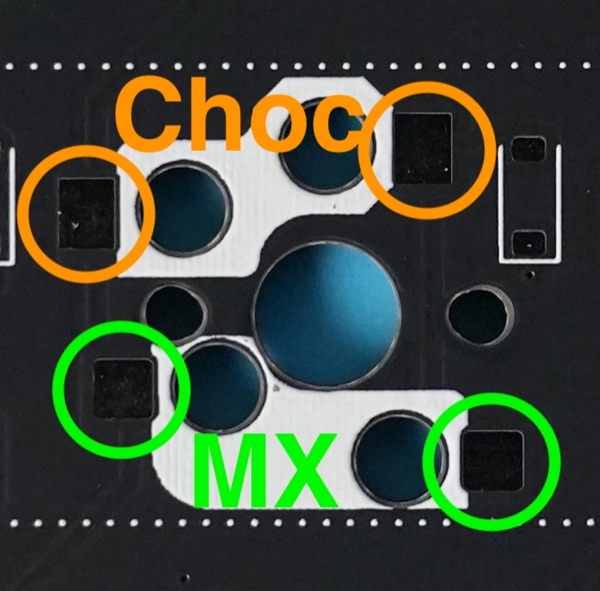
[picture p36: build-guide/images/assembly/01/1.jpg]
ホットスワップソケットを取り付ける基板上の位置
|  |  |

> [!NOTE]
> **はんだ付けのコツ**
>
> はじめにどちらか一方のランドに予備はんだをし、それを溶かしながらソケットを載せます。ソケットとはんだが馴染んだらはんだごてを離し、残るもう片方のパッドとソケットをはんだ付けします。
>
> スイッチソケットのはんだパッドは他の部品と比較して広く、熱容量が大きいため十分に加熱してください。

ソケットのはんだ付けが完了すると以下のような状態になります。（画像はMX/Choc両対応の例）

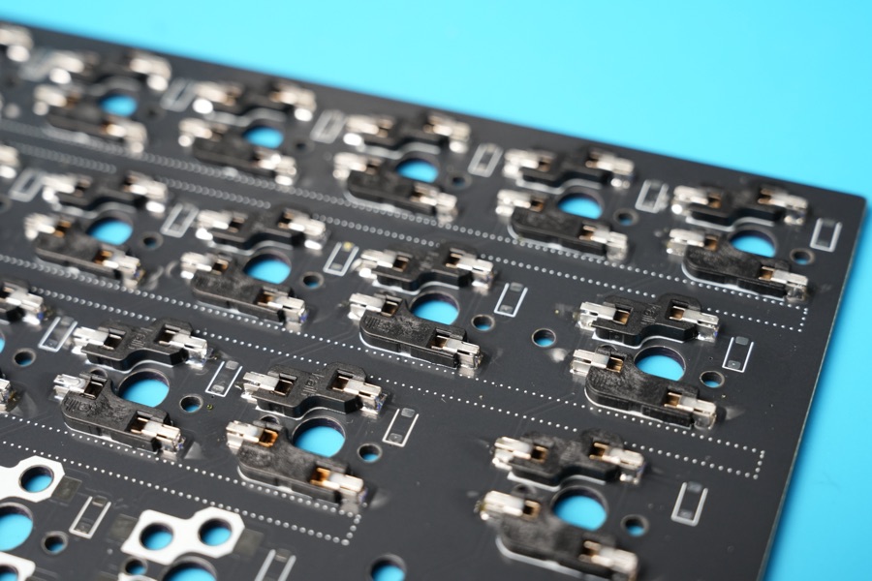
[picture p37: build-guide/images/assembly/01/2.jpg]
MXとChoc両対応でホットスワップソケットをはんだ付けした状態


**完了チェック**

- [ ] 使用する構成に必要なソケットを、ソケット種別ごとに左右合計70箇所（右39箇所、左31箇所）へ実装した
- [ ] ソケットが基板に密着していて、浮いている箇所がない
- [ ] はんだがランドとソケット端子の両方に流れている

### 2. スイッチングダイオードのはんだ付け
左右の基板で合計70箇所（右39箇所、左31箇所）にスイッチングダイオード（チップ表面に「T4」と表記があるもの）をはんだ付けします。
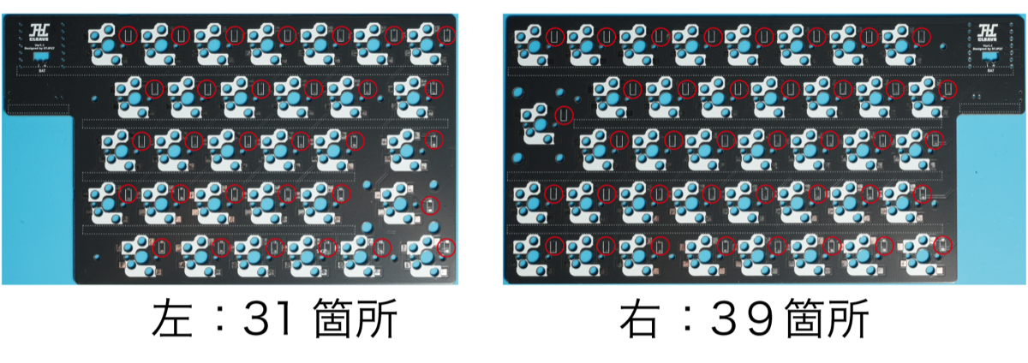
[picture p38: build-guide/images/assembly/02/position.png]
スイッチングダイオードの実装位置


> [!IMPORTANT]
> ダイオードには向きがあります。フットプリントのコの字に閉じている方をダイオードの線がついている方（カソード）に合わせます。

| 取り付ける部品 | 取り付け基板箇所 |
|---|---|
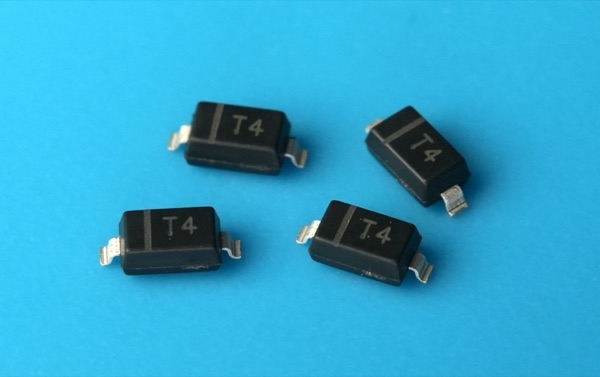
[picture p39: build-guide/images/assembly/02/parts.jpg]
スイッチングダイオード部品
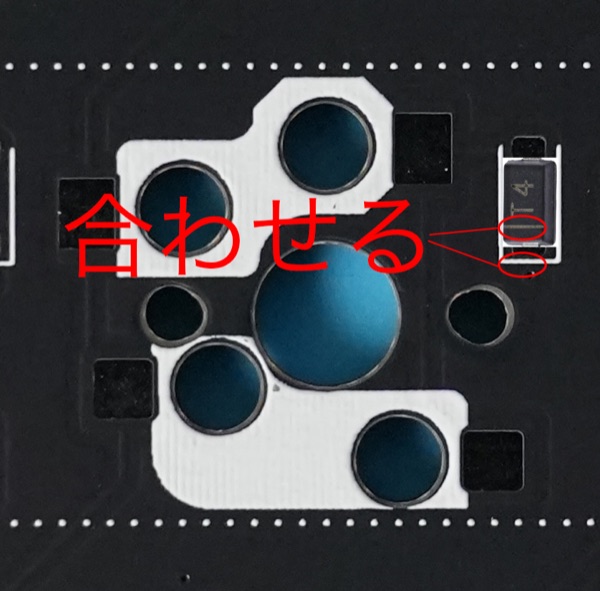
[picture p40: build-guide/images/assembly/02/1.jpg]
スイッチングダイオードを取り付ける基板上の位置
|  |  |

スイッチングダイオードのはんだ付けが完了すると以下のような状態になります。（画像はMX/Choc両ソケット対応の例）
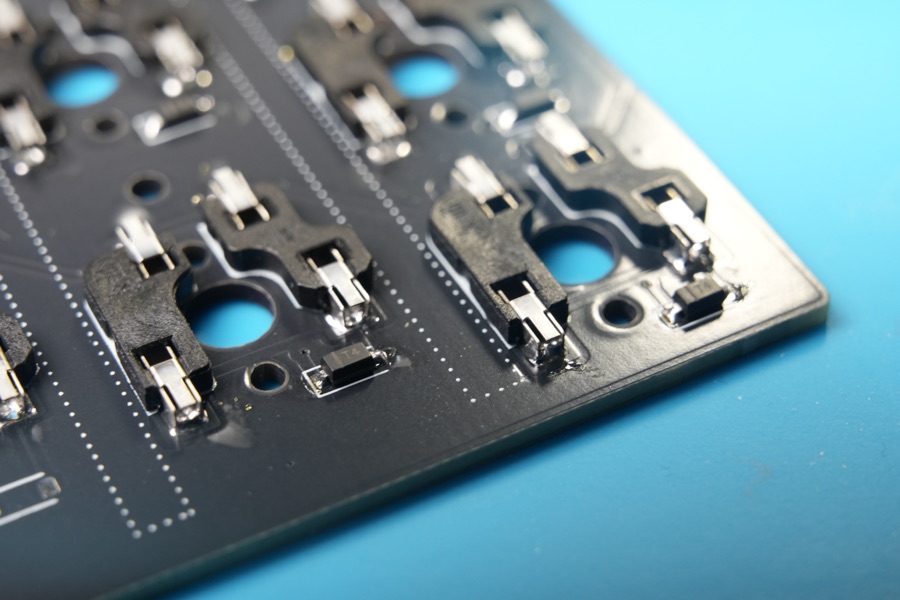
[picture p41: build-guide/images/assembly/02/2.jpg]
スイッチングダイオードをはんだ付けした状態


**完了チェック**

- [ ] 右39箇所、左31箇所にスイッチングダイオードを実装した
- [ ] すべてのダイオードの線がフットプリントのコの字側に合っている
- [ ] 浮いているダイオードや片側だけ未はんだの箇所がない

これで基板ウラ面の実装は完了しました。続いて基板を裏返しにしてオモテ面の実装をします。

### 3. 電源スイッチのはんだ付け
基板オモテ面の`PWR_SW`とシルクスクリーンが印刷されている箇所に電源スイッチ「MSK-12C02」を実装します。
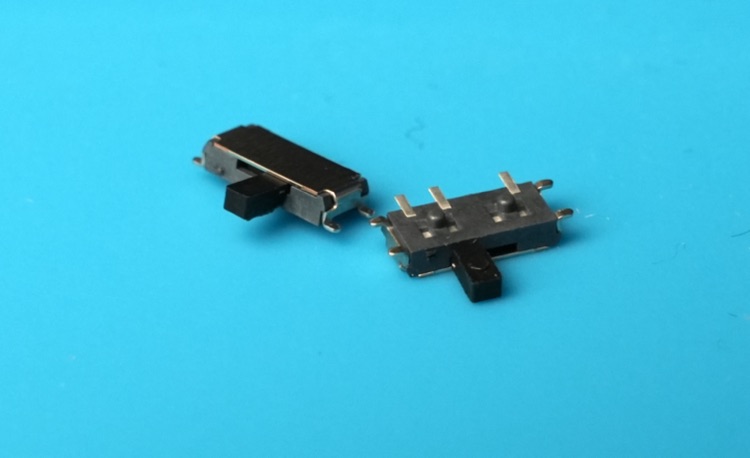
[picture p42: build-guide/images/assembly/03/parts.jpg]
電源スイッチ MSK-12C02 部品


位置合わせ用の穴が2つ空いているので、それに合わせて3つのピンをはんだ付けします。
固定できたらスイッチ両脇にある固定用のはんだパッドもはんだ付けして固定します。

> [!NOTE]
> 左右の基板で向かい合うようにどちらもはんだ付けします。

電源スイッチのはんだ付けが完了すると以下のような状態になります。

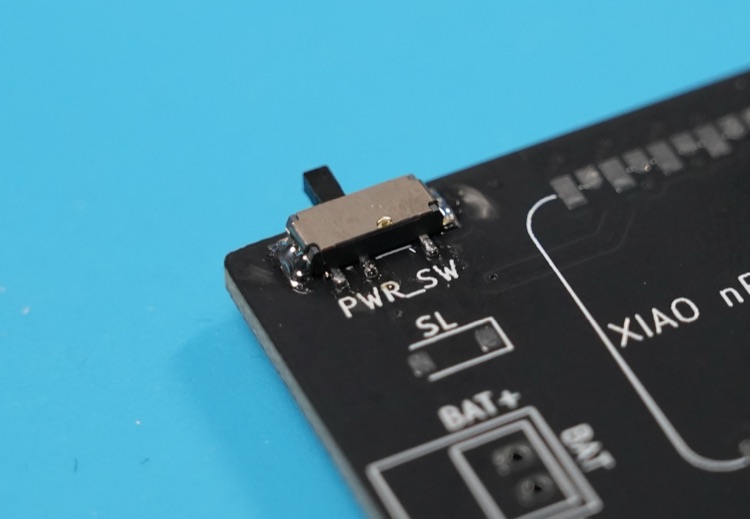
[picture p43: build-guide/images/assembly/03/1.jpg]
電源スイッチを基板に実装した状態


**完了チェック**

- [ ] 左右の基板に電源スイッチを実装した
- [ ] スイッチ本体が基板に密着している
- [ ] 3本のピンと両脇の固定用パッドをはんだ付けした
- [ ] スイッチのノブを動かしても部品がぐらつかない

> [!WARNING]
> これ以降の作業では、基板からはみ出した電源スイッチのノブに過剰な負荷（落下・衝撃）をかけないように注意してください。過剰な負荷がかかると電源スイッチが破損するおそれがあります。心配な場合はマスキングテープ等で養生したり、電源スイッチの取り付けを組み立ての最後にしても問題ありません。

### 4. ショットキーダイオードのはんだ付け
バッテリー充電の逆流防止ダイオード（チップ表面に「SL」と表記があるもの）を実装します。

| 取り付ける部品 | 取り付け基板箇所 |
|---|---|
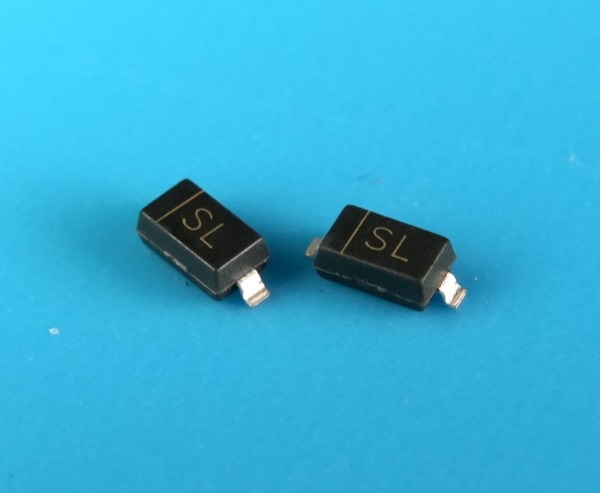
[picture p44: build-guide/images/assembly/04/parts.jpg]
ショットキーバリアダイオード部品
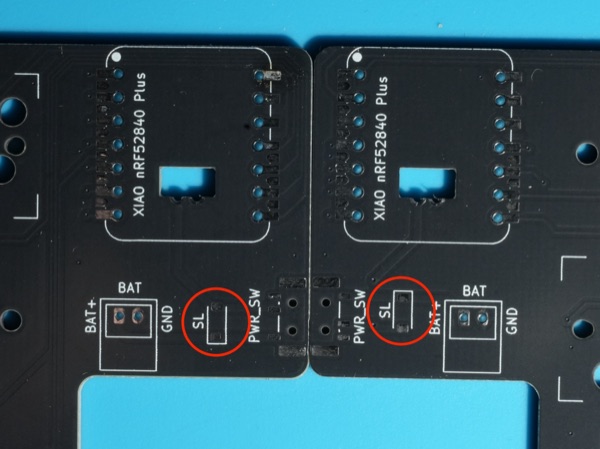
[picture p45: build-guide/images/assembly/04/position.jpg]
ショットキーダイオードを取り付ける基板上の位置
|  |  |

> [!IMPORTANT]
> ショットキーダイオードは左右の基板で向きが異なります。はんだ付け前に、フットプリントのコの字側とダイオードの線（カソード）が合っていることを左右それぞれ確認してください。

> [!TIP]
> 下の図で、左基板と右基板それぞれの取り付け向きを確認します。
>
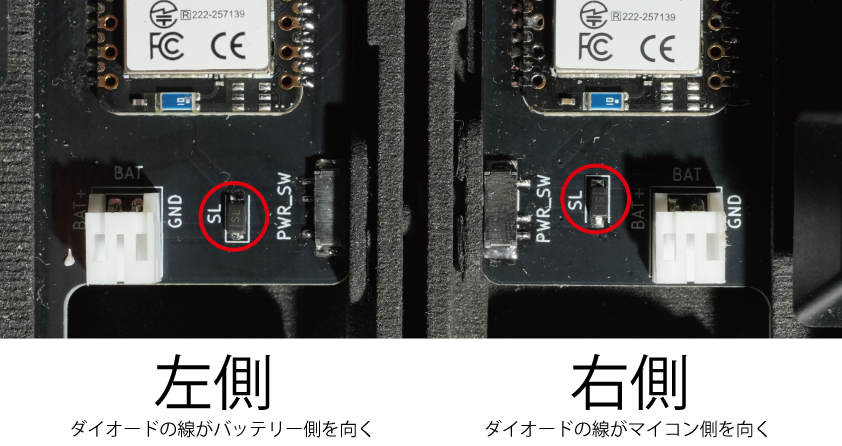
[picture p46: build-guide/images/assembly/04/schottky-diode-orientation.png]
左基板と右基板のショットキーダイオードの向き
> 

ダイオードのはんだ付けが完了すると以下のような状態になります。

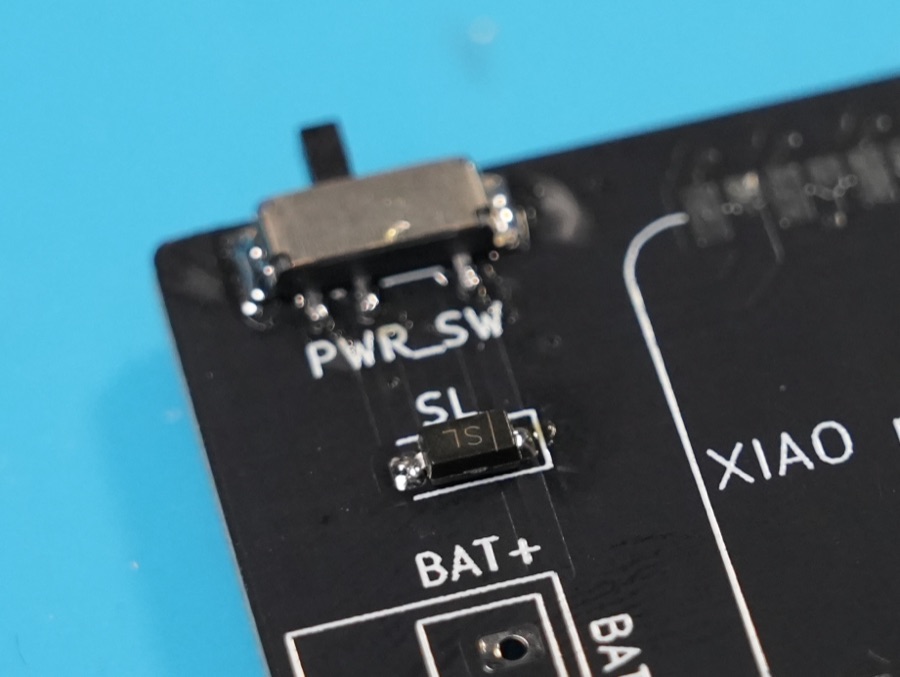
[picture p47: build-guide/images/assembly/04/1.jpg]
ショットキーダイオードをはんだ付けした状態


**完了チェック**

- [ ] 左右の基板にショットキーダイオードを実装した(左右で取り付け向きが異なることに注意)
- [ ] ダイオードの線がフットプリントのコの字側に合っている

### 5. XIAO nRF52840 Plusのはんだ付け
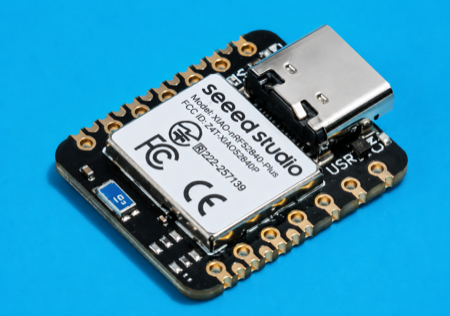
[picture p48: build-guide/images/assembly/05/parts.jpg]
XIAO nRF52840 Plus部品


XIAO nRF52840 Plusはピンの間が非常に狭く、位置合わせがこの作業の成功を左右します。以下のステップでキーボード本体の基板とXIAO nRF52840 Plusの位置合わせをしてください。

白い「XIAO nRF52840 Plus」と書かれたラベルが見えるオモテ面を上にしてXIAO nRF52840 Plusを乗せます。USB Type-Cコネクタが基板の外周側を向き、XIAOの端面パッドと基板側のパッドが左右とも揃う向きで取り付けます。

> [!NOTE]
> 準備ガイドで用意した位置合わせ用ピンヘッダは、この工程でXIAO nRF52840 Plusの位置を合わせるためだけに使います。
> ピンヘッダははんだ付けせず、仮止め後に抜き取ります。

| 手順 | 画像 |
|---|---|
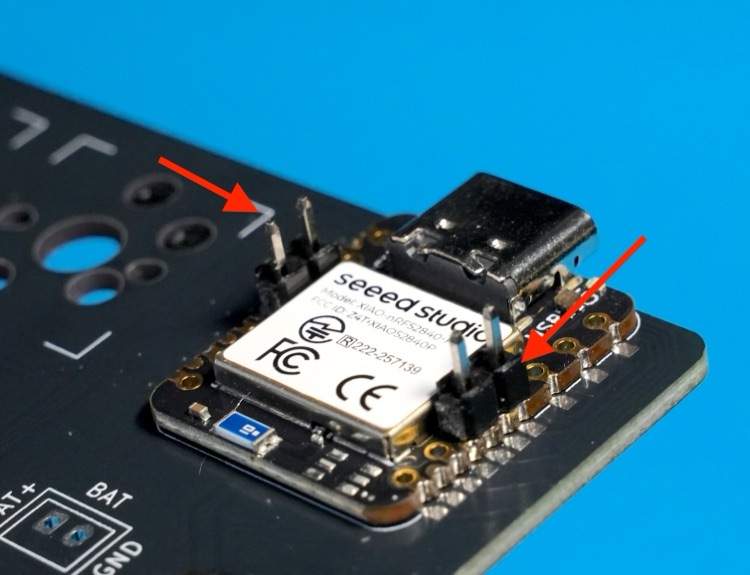
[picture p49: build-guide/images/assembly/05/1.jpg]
XIAO nRF52840 Plusを基板上に載せ、ピンヘッダで位置合わせしている状態
| XIAOを基板のオモテ面に乗せて"**その上から**"位置合わせ用ピンヘッダを任意のスルーホールに差し込んで位置を合わせます。 |  |
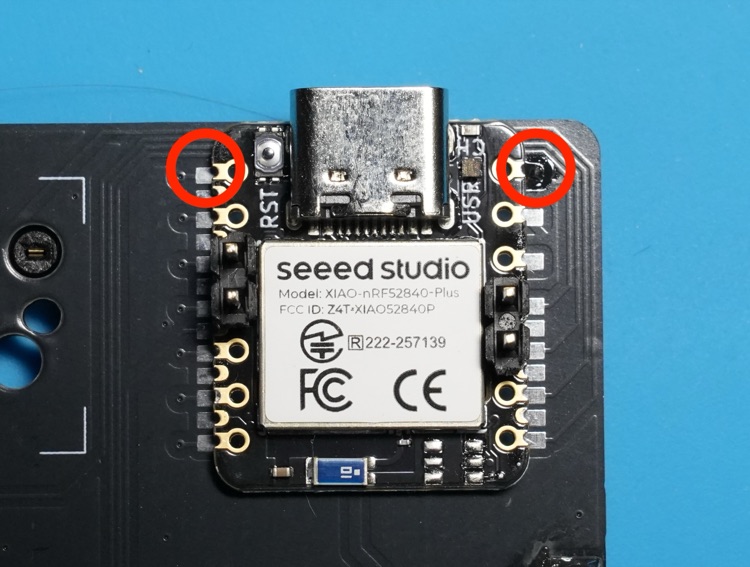
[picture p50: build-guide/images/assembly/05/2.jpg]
XIAO nRF52840 Plusの端のパッドを仮止めした状態
| 両側面の端を1つずつはんだ付けして仮止めします。このときにマイコンが基板から浮いていないことを確認してください。 |  |
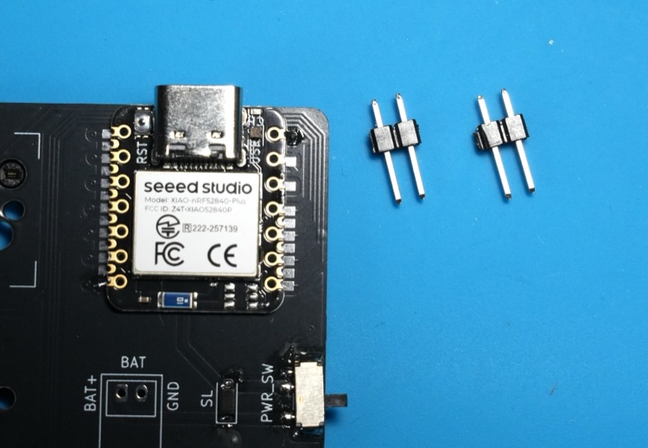
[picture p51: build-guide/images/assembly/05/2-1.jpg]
仮止め後に位置合わせ用ピンヘッダを抜いた状態
| ピンヘッダを抜きます。 |  |
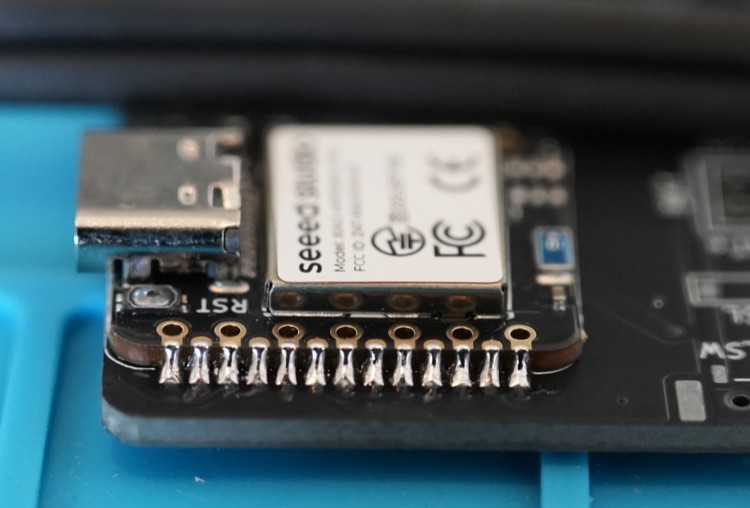
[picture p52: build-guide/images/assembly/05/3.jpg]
XIAO nRF52840 Plusの全パッドをはんだ付けした状態
| XIAO nRF52840 Plusの全てのパッドを本はんだ付けします。 |  |

> [!IMPORTANT]
> XIAO nRF52840 Plusはピンの間が非常に狭く、はんだがブリッジしやすいため、はんだ付け後に目視とテスターの導通チェックモードで各ピンがショートしていないことを確認することを推奨します。
> 
> キーボードとして最低限動作させるだけであれば、以下の画像で赤く示したパッドをはんだ付けすれば十分です。ただし、マイコンのモゲ防止のため、可能な限りすべてのパッドをはんだ付けして固定することを推奨します。
> 
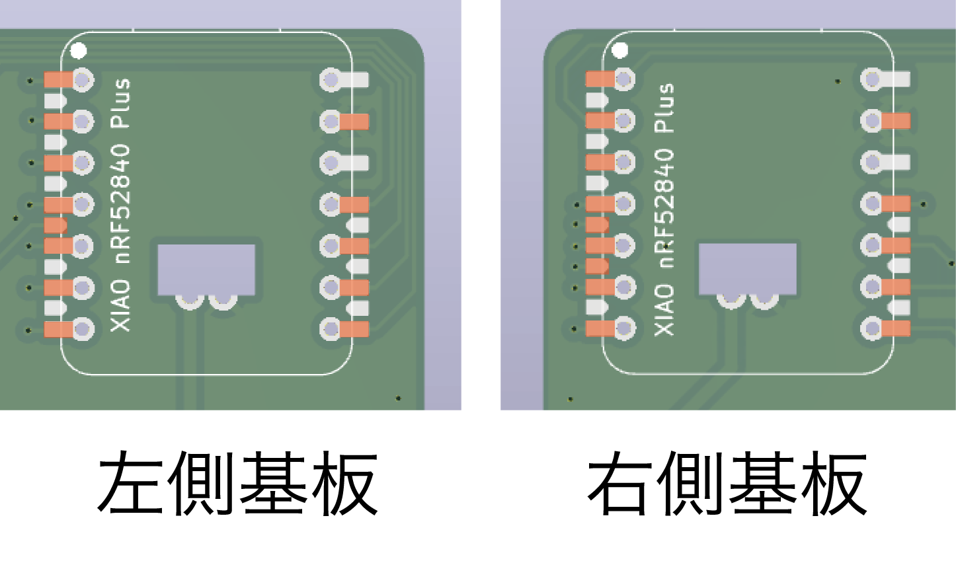
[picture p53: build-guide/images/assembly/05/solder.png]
XIAO nRF52840 Plus必須はんだ付けパッド
> 

基板を裏返してウラ面のバッテリーパッドの2箇所もはんだ付けして完了です。

> [!NOTE]
> キーボード本体のバッテリーパッドはスルーホールの穴を半分に削った際の銅箔の切れ端が付いていることがあります。
> その場合はピンセットなどで取り除き、パッドが銀色であることを確認してからはんだ付けします。
> パッドの銅箔は非常に剥がれやすいため慎重に取り除いてください。
> 
> 万が一、スルーホール部分の銅箔が剥がれてしまっても、XIAO nRF52840 Plus側のバッテリーパッドと基板ウラ面のパッドが確実にはんだ付けできていればれば、そのまま使用できます。

| ウラ面のバッテリーパッド | はんだ付け後 |
|---|---|
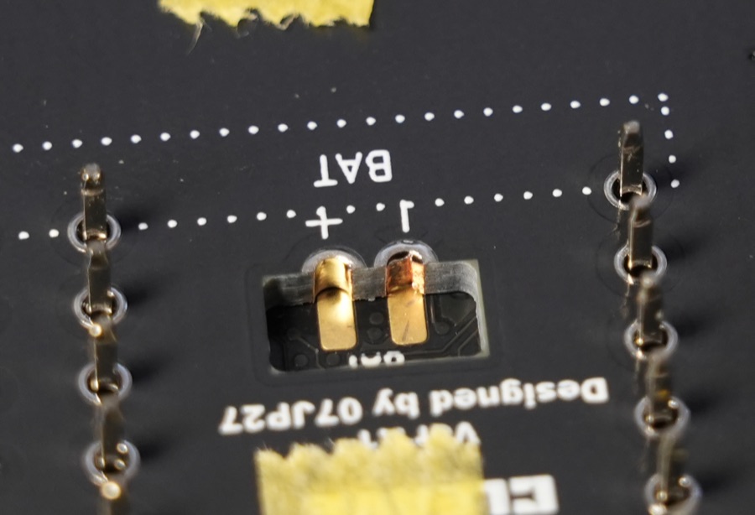
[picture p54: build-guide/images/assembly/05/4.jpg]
XIAO nRF52840 Plusウラ面のバッテリーパッド
|  | ウラ面のバッテリーパッドをはんだ付けした状態 |

> [!NOTE]
> 左右の基板どちらも同じようにはんだ付けします。

**完了チェック**

- [ ] XIAO nRF52840 Plusの向きが左右とも正しい
- [ ] XIAO nRF52840 Plusが基板に対して浮かず、水平に載っている
- [ ] すべてのピンにはんだが回っている
- [ ] 隣り合うピンがブリッジしていないことを目視またはテスターで確認した

### 6. バッテリーコネクタのはんだ付け
バッテリー用のJST PHコネクタを基板に取り付けます。

バッテリー用JST PHコネクタ部品

コネクタの開口部を基板の外向きになるようにスルーホールに差し込み、マスキングテープなどで固定してウラ面からはんだ付けします。

| オモテ面から差し込んで | ウラ面からはんだ付け |
|---|---|
| バッテリーコネクタを基板のオモテ面から差し込んだ状態 | バッテリーコネクタを基板のウラ面からはんだ付けした状態 |

> [!NOTE]
> 左右の基板どちらも同じようにはんだ付けします。

**完了チェック**

- [ ] 左右の基板にバッテリーコネクタを実装した
- [ ] コネクタの開口部が基板の外側を向いている
- [ ] コネクタが基板に対して傾かず、奥まで差し込まれている
- [ ] ウラ面のピンにはんだが十分に回っている

### 7. キースイッチの仮取り付け（基板単体での動作確認準備）
> [!NOTE]
> このステップは、ファームウェア書き込み後のキー入力確認を、ケースへ組み込む前に基板単体で行えるようにするための仮取り付けです。

「1. ホットスワップソケットのはんだ付け」ではんだ付けしたソケットに差し込むようにMX/Chocどちらかのスイッチを差し込みます。
スイッチの種類によっては位置合わせ穴に隙間ができる場合がありますが、ケース装着時にトッププレートで固定するため問題ありません。MX構成でスタビライザーを使用する場合は、このタイミングで仮取り付けして、取り付け位置や干渉がないことを確認します。

- 右：39個
- 左：31個

基板単体での動作確認準備としてキースイッチを仮取り付けした状態

**完了チェック**

- [ ] スイッチのピンが曲がらず、ソケットにまっすぐ入っている
- [ ] ファームウェア書き込み後のキー入力確認に使うキースイッチを仮取り付けした
- [ ] スイッチを押しても大きく傾いたり抜けたりしない

## テスターを使った導通テスト
### Col方向のテスト
画像の赤丸で示したソケット端子は、同じ赤線でつながっている端子同士が導通します。
テスターを導通モード（短絡すると音が鳴るモード）にして、赤線でつながっている端子同士にプローブを当て、導通することを確認します。
| 左基板 | 右基板 |
|---|---|
| 左基板の列方向導通テスト位置 | 右基板の列方向導通テスト位置 |

### Row方向のテスト（ダイオード含む）
各スイッチ位置では、赤丸で示したソケット端子とダイオード片側のパッドが同じRow配線につながっています。まずテスターを導通モードにして、赤丸同士が導通することを確認します。

赤丸と青丸の間にはダイオードが入っているため、導通モードではなくダイオードモードで確認します。ダイオードモードではプローブの極性が関係するため、赤丸側に+プローブ、青丸側にCOM（黒色）プローブを当ててください。

Row方向で導通する赤丸同士と、ダイオードモードで確認する赤丸と青丸の位置

### 不良時の対応

**Col方向のテスト、またはRow方向の赤丸同士が導通しない場合**

- ソケット端子やダイオード片側のパッドが、基板のランドとはんだでつながっていない可能性があります。
- 該当箇所のはんだ付けを確認し、はんだごてで再加熱します。
- 端子とランドの両方にはんだが流れていない場合は、少量のはんだを足して接続し直します。

**Row方向の赤丸と青丸をダイオードモードで確認できない場合**

- まず、赤丸側に+プローブ、青丸側にCOM（黒色）プローブを当てているか確認します。
- 極性が正しくても反応しない場合は、ダイオードの向きを確認します。
- ダイオードが逆向きの場合は、はんだ吸い取り線などで外して実装し直します。
- 向きが正しく、はんだ付けにも問題がない場合は、ダイオードの部品不良が考えられるため交換します。

## バッテリーの接続（基板単体での動作確認準備）
> [!NOTE]
> このステップは、ファームウェア書き込み後の接続確認・動作確認を、ケースへ組み込む前に基板単体で行えるようにするための接続手順です。

接続前にUSBケーブルを抜き、左右の電源スイッチがOFFになっていることを確認します。
スイッチのピンが2本ある側へノブをスライドするとOFFです。左右でスイッチの向きが逆になるため注意してください。

電源スイッチをOFFにする方向

その後、LiPoバッテリーの極性に注意しながら、赤黒2本のリード線を以下のシルクスクリーン印刷に合わせて差し込みます。
|シルクスクリーンの印刷|極性|
|---|---|
|BAT+|正極（赤色のケーブル）|
|GND|負極（黒色のケーブル）|

> [!CAUTION]
> LiPoバッテリーはショートや強い曲げ、穴あき、圧迫で発熱・発火する可能性があります。赤黒のリード線やコネクタ端子を金属工具で同時に触れないでください。
> バッテリーの極性を間違えて接続するとマイコンが壊れて修復不能になる場合があります。十分注意してください。極性が不安な場合はテスターで電圧を測るなどして極性を確認することを推奨します。

LiPoバッテリーをBAT+とGNDの極性に合わせて接続した状態

**完了チェック**

- [ ] 左右それぞれのバッテリーを接続した
- [ ] `BAT+`に赤色のケーブル、`GND`に黒色のケーブルが接続されている
- [ ] コネクタが奥まで差し込まれている
- [ ] ケーブルや端子がショートしそうな状態になっていない

> [!NOTE]
> すでにバッテリーに付いているJST PHコネクタの極性が逆になっている場合、以下のサイトの方法を参考に極性を差し換えてください。
> [コネクタの自作！電子工作の圧着工具と圧着方法](https://xn--p8jqu4215bemxd.com/archives/397#:~:text=%E3%81%8F%E3%81%AA%E3%82%8A%E3%81%BE%E3%81%99%E3%80%82-,%E3%82%B3%E3%83%8D%E3%82%AF%E3%82%BF%E3%83%94%E3%83%B3%E3%81%AE%E5%A4%96%E3%81%97%E6%96%B9,-%E3%81%82%EF%BC%81%E9%96%93%E9%81%95)

## ステップの完了
おめでとうございます！これではんだ付けが必要な実装は全て完了しました。
次のステップでは左右それぞれのXIAO nRF52840 Plusへファームウェアを書き込み、基板単体で接続確認を行います。

- [前: 準備ガイド](00-PREPARE.md)
- [次: ファームウェアのダウンロード・書き込み・接続確認](02-FIRMWARE.md)
- [目次に戻る](README.md)

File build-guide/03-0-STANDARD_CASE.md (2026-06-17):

# CLEAVE HHJP 標準ケースビルドガイド

[目次に戻る](README.md)

配布されている3Dモデルを3Dプリントして、CLEAVE HHJP の標準ケースを作成する方法について説明します。

## 目次

- [ケースの構成](#ケースの構成)
- [ケース組み立て前の状態確認](#ケース組み立て前の状態確認)
- [ケース組み立て手順](#ケース組み立て手順)
- [参考: 完成状態](#参考-完成状態)

## ケースの構成

ケースは、ベースケース（Base case）、PCB、トッププレート、トップカバー、キースイッチなどを組み合わせて作成します。

CLEAVE HHJPのケース分解図

3Dプリント部品、ケース部材、素材の選び方は[準備ガイドのケース関連](00-PREPARE.md#ケース関連)にまとめています。

## ケース組み立て前の状態確認

基板単体でのファームウェア書き込みと動作確認が済んだら、以下の状態に応じてケースへ組み込みます。

| 現在の状態 | 進め方 |
|---|---|
| キースイッチを基板単体での動作確認準備として仮取り付けしている | いったんスイッチを外し、このガイドの「4. キースイッチ取り付け」でトッププレートと一緒に取り付け直します。 |
| MXスタビライザーを使う | 仮取り付け済みの場合は外す必要はありません。まだ取り付けていない場合は、キースイッチを取り付ける前にPCBへ取り付けます。トッププレートやPCBと干渉しないことを確認しながら組み込みます。 |
| バッテリーを基板単体での動作確認準備として接続している | ケースへ組み込む前にいったんバッテリーを外し、このガイドの「8. バッテリーの固定」で接続し直して収まりと固定を確認します。 |
| キースイッチやバッテリーをまだ取り付けていない | このガイドの手順に沿って、キースイッチ取り付けとバッテリー固定を行います。 |

## ケース組み立て手順

> [!NOTE]
> **左右両方で作業してください**
>
> このガイドでは写真や説明が片側のみの場合がありますが、特に記載がない限り、同じ手順を左用・右用の両方で行ってください。

### 1. ケース部品の確認
組み立てを始める前に、準備ガイドで決めた構成の部品が揃っていることを確認します。

**確認するもの**

- 左右のベースケース
- 左右のトップカバー
- 左右の電源スイッチノブ
- 使用するキースイッチに対応した左右のトッププレート
- インサートナット、M2ネジ、フォームテープ
- インジケーター穴ありトップカバーを使う場合は、透明プラ棒
- 必要に応じて滑り止めシート

**完了チェック**

- [ ] 選択した構成に必要なケース部品をすべて用意した
- [ ] 組み立てに必要なネジ、インサートナット、フォームテープなどの部材を用意した
- [ ] ねじ穴、インサートナット穴、スイッチ穴などに造形残りや穴詰まりがない

### 2. インサートナットの取り付け
下図の赤丸で示した左右それぞれ7箇所に、インサートナットをはんだごてで熱圧入します。
ナットの上面とケースの上面が揃うところまで押し込みます。
インサートナットの取り付け位置

インサートナットは細い方をケース側に向けて差し込みます。
インサートナットの向き

はんだごてのこて先でインサートナットを温めながら、ケースの穴にまっすぐ押し込みます。
ナットの上面がケースの天面と同じ高さになるまで押し込み、はんだごてを抜きます。
このときにピンセットなどでナットが抜けないようにナットの上面を押さえながらはんだごてを抜くと確実です。
はんだごてでインサートナットを熱圧入している状態

以下のような状態になればOKです。
ベースケースのインサートナットを熱圧入した状態

**完了チェック**

- [ ] 左右それぞれ7箇所にインサートナットを取り付けた
- [ ] インサートナットの上面がケースの上面から大きく飛び出していない
- [ ] インサートナットが傾いていない
- [ ] ネジを軽く入れて、無理なく回ることを確認した

### 3. フォームテープの貼り付け
下図のオレンジ色で示した梁の部分にフォームテープを貼ります。
インサートナットやネジ穴を塞がないようにしてください。
フォームテープの貼付位置

ベースケース内側の梁にフォームテープを貼った状態

**完了チェック**

- [ ] フォームテープがケース内側の梁に沿って貼られている
- [ ] インサートナットやネジ穴をフォームテープで塞いでいない

### 4. キースイッチ取り付け
MX互換スイッチとChocV1/V2互換スイッチでは、使用するトッププレートが異なります。
上下の向きに注意してスイッチをトッププレートにはめ込みます。
トッププレートにキースイッチを取り付けた状態

**完了チェック**

- [ ] 使用するキースイッチに合ったトッププレートを用意した
- [ ] スイッチのピンが曲がっていない
- [ ] スイッチがトッププレートにはまっている

### 5. トッププレートの取り付け
PCBにスイッチを差し込みながらサンドイッチします。
このときにスイッチのピンが折れ曲がらないように注意します。一気に差し込むのではなく、端のスイッチから徐々にソケットに差し込むと安定的に差し込めます。
PCBとトッププレートでキースイッチを挟み込んだ状態

**完了チェック**

- [ ] スイッチがトッププレートとPCBの両方に正しく入っている
- [ ] スイッチのピンが曲がらず、PCBのソケットに入っている

### 6. 電源スイッチノブの取り付け
ケースの内側から電源スイッチノブを差し込みます。

| 電源スイッチノブをケースの裏側から通して→ | ケースの外側にノブを出す |
|---|---|
| 電源スイッチノブをケースの裏側から通す状態 | 電源スイッチノブがケース外側に出た状態 |

**完了チェック**

- [ ] 電源スイッチノブを取り付け、引っかからず左右に動くことを確認した

### 7. PCBの取り付け
ベースケースにPCBとトッププレートとキースイッチが一体になった部品を装着します。
電源スイッチの窪みにPCBの電源スイッチのノブが刺さるようにスライドさせながらはめ込みます。

PCB、トッププレート、キースイッチをベースケースに収めた状態

トッププレートのフチがベースケースにぴったり合うように調整し、左右それぞれ4箇所を、ChocトッププレートではM2 8mm、MXトッププレートではM2 10mmのネジで固定します。

トッププレートを固定するM2ネジ位置

**完了チェック**

- [ ] PCB、トッププレート、キースイッチがベースケースに収まっている
- [ ] 電源スイッチノブで基板上の電源スイッチを操作できる
- [ ] トッププレートのフチがベースケースに沿っている
- [ ] 左右それぞれ4箇所を、使用するトッププレートに合った長さのM2ネジで固定した
- [ ] ネジを締めすぎてケースやトッププレートが変形していない

### 8. バッテリーの固定
外しておいたバッテリーをコネクタに差し込み直して、バッテリー用のスペースに格納します。
バッテリーが振動などで破損しないように、バッテリー裏面を両面テープなどでケースに固定することを強く推奨します。

|シルクスクリーンの印刷|極性|
|---|---|
|BAT+|正極（赤色のケーブル）|
|GND|負極（黒色のケーブル）|

> [!CAUTION]
> LiPoバッテリーはショートや強い曲げ、穴あき、圧迫で発熱・発火する可能性があります。接続作業中はUSBケーブルを抜き、電源スイッチをOFFにします。赤黒のリード線やコネクタ端子を金属工具で同時に触れないでください。
> バッテリーの極性を間違えて接続するとマイコンが壊れて修復不能になる場合があります。バッテリーやケーブルがネジ穴、トップカバー、PCBに挟まれないことも確認してください。

バッテリーをケース内のスペースに収めた状態

**完了チェック**

- [ ] バッテリーコネクタが奥まで差し込まれている
- [ ] `BAT+`に赤色のケーブル、`GND`に黒色のケーブルが接続されている
- [ ] バッテリーがケース内のスペースに収まっている
- [ ] バッテリーやケーブルがネジ穴、トップカバー、PCBに挟まれない
- [ ] バッテリーがケース内で動かないように固定されている

### 9. インジケーターの取り付け
> [!NOTE]
> インジケーター穴ありトップカバーを使う場合のみ行います。穴なしトップカバーを使う場合は、このステップは実施不要です。

直径2mm透明プラ棒（3mm程度）をトップカバーに差し込みます。
FDMプリントなど熱収縮がある素材と3Dプリント方法の場合、プラ棒が入らない場合があるため、カッターやドリルなどで穴径を広げます。
接着はまだしません。

トップカバーのインジケーター穴に透明プラ棒を差し込んだ状態

**完了チェック**

- [ ] 透明プラ棒を左右それぞれ必要な位置に差し込んだ

### 10. トップカバーの取り付け
インジケーターを付けた場合はここでPCBとインジケーターの隙間を調整し、上面に出ている不要な分はニッパーなどで切って調整したあとに接着剤などを使ってカバーの側から接着してください。
トップカバーをベースケースに固定した状態

トップカバーを左右それぞれ3箇所のM2 4mmネジで固定します。
トップカバーを固定するM2ネジ位置

**完了チェック**

- [ ] （インジケーターありの場合）透明プラ棒の長さを調整して固定した
- [ ] トップカバーを左右それぞれ3箇所のM2 4mmネジで固定した
- [ ] トップカバーが浮かず、ベースケースに沿っている

### 11. キーキャップの取り付け
用意したキーキャップをスイッチに装着します。

**完了チェック**

- [ ] すべてのキーキャップを取り付けた
- [ ] キーキャップが隣のキーやケースに干渉せず、必要なキーを押せることを確認した

### 12. 滑り止めの取り付け（任意）
3Dプリントしたケースや使うデスクの材質によってはキーボードが滑ることがあるので、お好みに応じてケースの裏側に両面テープなどでポロンシートやすべり止めシートを貼り付けます。

**完了チェック**

- [ ] 必要に応じて滑り止めを貼り、キーボードを置いたときにがたつきがないことを確認した

## 参考: 完成状態
ケースの組み立てが完了すると、以下のような状態になります。写真はChocキースイッチとChoc用キーキャップを使用した例です。

ChocキースイッチとChoc用キーキャップで組み立てたCLEAVE HHJPの完成状態

## ステップの完了
ついにキーボードが完成しました。
次のガイドではこのキーボードの使い方を確認しましょう。
- [前: ファームウェアのダウンロード・書き込み・接続確認](02-FIRMWARE.md)
- [次: 完成後の使い方](04-USAGE.md)
- [目次に戻る](README.md)

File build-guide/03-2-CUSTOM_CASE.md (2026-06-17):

# CLEAVE HHJP オリジナルケース作成ガイド

[目次に戻る](README.md)

このガイドでは、PCB外形STEPデータを参照して CLEAVE HHJP のオリジナルケースを作る場合に確認することをまとめます。

## 目次

- [このガイドの位置付け](#このガイドの位置付け)
- [参照できるデータ](#参照できるデータ)
- [設計前に決めること](#設計前に決めること)
- [設計時のチェックポイント](#設計時のチェックポイント)
- [製作後の組み込み確認](#製作後の組み込み確認)
- [ステップの完了](#ステップの完了)

## このガイドの位置付け

オリジナルケースは、標準ケースや簡易ケースキットを使わず、自分でケース構造を設計・製作する選択肢です。
配布されているSTEPファイルはPCB外形の参照用であり、ケースとしてそのまま使えるデータではありません。

> [!IMPORTANT]
> オリジナルケースの設計・製作は自己責任で行ってください。
> PCB、LiPoバッテリー、USBポート、電源スイッチ、キースイッチ、ネジなどに無理な力がかからないように設計し、組み込み後に安全性を確認してください。

## 参照できるデータ

左右PCBの外形データとして、以下のSTEPファイルを参照できます。これらはKiCadから出力したmm単位のデータです。

| 対象 | ファイル |
|---|---|
| 左PCB | [left.step](../models/pcb/left.step) |
| 右PCB | [right.step](../models/pcb/right.step) |

標準ケースの構造を参考にしたい場合は、[ケースの3Dモデル](../models)も確認できます。

## 設計前に決めること

ケースを設計する前に、以下を決めておくと必要な寸法や固定方法を整理しやすくなります。

| 決めること | 確認する内容 |
|---|---|
| 使用するキースイッチ | MX互換、ChocV1/V2互換、または両対応にするかを決めます。 |
| トッププレート構造 | スイッチをどの部品で保持し、PCBへどのように固定するかを決めます。 |
| バッテリー位置 | 使用するLiPoバッテリーのサイズ、固定方法、ケーブルの逃げを決めます。 |
| 電源スイッチの操作方法 | 基板上の電源スイッチに指やノブが無理なく届く構造を決めます。 |
| USBポートへのアクセス | ファームウェア書き込み、充電、ZMK Studio使用時にUSB Type-Cケーブルを接続できる形状にします。 |
| ケース固定方法 | ネジ、スペーサー、インサートナットなど、PCBやトッププレートに無理がかからない固定方法を決めます。 |

## 設計時のチェックポイント

設計中は、少なくとも以下を確認してください。

- PCB外形、部品実装面、XIAO nRF52840 Plus、バッテリーコネクタ、ホットスワップソケットがケースと干渉しない
- キースイッチのピンが曲がらず、ホットスワップソケットへまっすぐ入る
- キースイッチ、キーキャップ、トッププレート、ケースが互いに干渉しない
- 電源スイッチをON/OFFでき、スイッチ本体に横方向の過剰な力がかからない
- USB Type-Cケーブルを無理なく抜き差しできる
- LiPoバッテリーが圧迫、穴あき、強い曲げ、ショートの危険がない状態で固定できる
- バッテリーケーブルがネジ、トップカバー、PCBなどに挟まれない
- 金属部品を使う場合、PCBの露出パッドやバッテリー端子と短絡しない

> [!CAUTION]
> LiPoバッテリーはショートや強い曲げ、穴あき、圧迫で発熱・発火する可能性があります。
> ケース設計時は、バッテリー本体とケーブルに力がかからず、導電部へ触れない固定方法を必ず確保してください。

## 製作後の組み込み確認

製作したケースに基板を組み込む前に、まずケース単体でネジ穴、スイッチ穴、USBポート周辺、電源スイッチ周辺に加工不良や干渉がないか確認します。

基板、キースイッチ、バッテリーを組み込んだら、以下を確認します。

- [ ] 左右の基板がケース内で動かないように固定されている
- [ ] スイッチのピンが曲がらず、ソケットに入っている
- [ ] バッテリーコネクタが奥まで差し込まれている
- [ ] `BAT+`に赤色のケーブル、`GND`に黒色のケーブルが接続されている
- [ ] バッテリーやケーブルがケース、ネジ、PCBに挟まれていない
- [ ] USB Type-Cケーブルを接続できる
- [ ] 電源スイッチを操作できる
- [ ] 左右すべてのキーが入力できる

標準ケースや簡易ケースの組み込み手順を参考にしたい場合は、[標準ケースビルドガイド](03-0-STANDARD_CASE.md)または[簡易ケースビルドガイド](03-1-SIMPLE_CASE.md)も確認してください。

## ステップの完了

オリジナルケースへの組み込みが完了したら、完成後の使い方を確認します。

- [前: ファームウェアのダウンロード・書き込み・接続確認](02-FIRMWARE.md)
- [次: 完成後の使い方](04-USAGE.md)
- [目次に戻る](README.md)

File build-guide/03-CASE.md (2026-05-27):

# CLEAVE HHJP ケースビルドガイド

[目次に戻る](README.md)

配布されている3Dモデルを使用して、CLEAVE HHJP のケースを作成する方法について説明します。

## 目次

- [ケースの構成](#ケースの構成)
- [ケース組み立て前の状態確認](#ケース組み立て前の状態確認)
- [ケース組み立て手順](#ケース組み立て手順)
- [参考: 完成状態](#参考-完成状態)

## ケースの構成

ケースは、ベースケース（Base case）、PCB、トッププレート、トップカバー、キースイッチなどを組み合わせて作成します。

CLEAVE HHJPのケース分解図

ケースに必要な3Dプリント部品、ケース部材、素材の選び方は[準備ガイドのケース関連](00-PREPARE.md#ケース関連)で確認してください。

## ケース組み立て前の状態確認

基板単体でのファームウェア書き込みと動作確認が済んだら、以下の状態に応じてケースへ組み込みます。

| 現在の状態 | 進め方 |
|---|---|
| キースイッチを基板単体での動作確認準備として仮取り付けしている | いったんスイッチを外し、このガイドの「4. キースイッチ取り付け」でトッププレートと一緒に取り付け直します。 |
| MXスタビライザーを使う | 仮取り付け済みの場合は外す必要はありません。まだ取り付けていない場合は、キースイッチを取り付ける前にPCBへ取り付けます。トッププレートやPCBと干渉しないことを確認しながら組み込みます。 |
| バッテリーを基板単体での動作確認準備として接続している | ケースへ組み込む前にいったんバッテリーを外し、このガイドの「8. バッテリーの固定」で接続し直して収まりと固定を確認します。 |
| キースイッチやバッテリーをまだ取り付けていない | このガイドの手順に沿って、キースイッチ取り付けとバッテリー固定を行います。 |

## ケース組み立て手順

> [!NOTE]
> **左右両方で作業してください**
>
> このガイドでは写真や説明が片側のみの場合がありますが、特に記載がない限り、同じ手順を左用・右用の両方で行ってください。

### 1. ケース部品の確認
組み立てを始める前に、[準備ガイドのケース関連](00-PREPARE.md#ケース関連)で用意した部品が揃っていることを確認します。
3Dプリント部品のモデル選択、ベースケース素材、トップカバーのタイプは準備ガイドで決めた内容に従ってください。

**確認するもの**

- 左右のベースケース
- 左右のトップカバー
- 左右の電源スイッチノブ
- 使用するキースイッチに対応した左右のトッププレート
- インサートナット、M2ネジ、フォームテープ
- インジケーター穴ありトップカバーを使う場合は、透明プラ棒
- 必要に応じて滑り止めシート

**完了チェック**

- [ ] 選択した構成に必要なケース部品をすべて用意した
- [ ] 組み立てに必要なネジ、インサートナット、フォームテープなどの部材を用意した
- [ ] ねじ穴、インサートナット穴、スイッチ穴などに造形残りや穴詰まりがない

### 2. インサートナットの取り付け
下図の赤丸で示した左右それぞれ7箇所に、インサートナットをはんだごてで熱圧入します。
ナットの上面とケースの上面が揃うところまで押し込みます。
インサートナットの取り付け位置

インサートナットは細い方をケース側に向けて差し込みます。
インサートナットの向き

はんだごてのこて先でインサートナットを温めながら、ケースの穴にまっすぐ押し込みます。
ナットの上面がケースの天面と同じ高さになるまで押し込み、はんだごてを抜きます。
このときにピンセットなどでナットが抜けないようにナットの上面を押さえながらはんだごてを抜くと確実です。
はんだごてでインサートナットを熱圧入している状態

以下のような状態になればOKです。
ベースケースのインサートナットを熱圧入した状態

**完了チェック**

- [ ] 左右それぞれ7箇所にインサートナットを取り付けた
- [ ] インサートナットの上面がケースの上面から大きく飛び出していない
- [ ] インサートナットが傾いていない
- [ ] ネジを軽く入れて、無理なく回ることを確認した

### 3. フォームテープの貼り付け
下図のオレンジ色で示した梁の部分にフォームテープを貼ります。
インサートナットやネジ穴を塞がないようにしてください。
フォームテープの貼付位置

ベースケース内側の梁にフォームテープを貼った状態

**完了チェック**

- [ ] フォームテープがケース内側の梁に沿って貼られている
- [ ] インサートナットやネジ穴をフォームテープで塞いでいない

### 4. キースイッチ取り付け
MX互換スイッチとChocV1/V2互換スイッチでは、使用するトッププレートが異なります。
上下の向きに注意してスイッチをトッププレートにはめ込みます。
トッププレートにキースイッチを取り付けた状態

**完了チェック**

- [ ] 使用するキースイッチに合ったトッププレートを用意した
- [ ] スイッチのピンが曲がっていない
- [ ] スイッチがトッププレートにはまっている

### 5. トッププレートの取り付け
PCBにスイッチを差し込みながらサンドイッチします。
このときにスイッチのピンが折れ曲がらないように注意します。一気に差し込むのではなく、端のスイッチから徐々にソケットに差し込むと安定的に差し込めます。
PCBとトッププレートでキースイッチを挟み込んだ状態

**完了チェック**

- [ ] スイッチがトッププレートとPCBの両方に正しく入っている
- [ ] スイッチのピンが曲がらず、PCBのソケットに入っている

### 6. 電源スイッチノブの取り付け
ケースの内側から電源スイッチノブを差し込みます。

| 電源スイッチノブをケースの裏側から通して→ | ケースの外側にノブを出す |
|---|---|
| 電源スイッチノブをケースの裏側から通す状態 | 電源スイッチノブがケース外側に出た状態 |

**完了チェック**

- [ ] 電源スイッチノブを取り付け、引っかからず左右に動くことを確認した

### 7. PCBの取り付け
ベースケースにPCBとトッププレートとキースイッチが一体になった部品を装着します。
電源スイッチの窪みにPCBの電源スイッチのノブが刺さるようにスライドさせながらはめ込みます。

PCB、トッププレート、キースイッチをベースケースに収めた状態

トッププレートのフチがベースケースにぴったり合うように調整し、左右それぞれ4箇所を、ChocトッププレートではM2 8mm、MXトッププレートではM2 10mmのネジで固定します。

トッププレートを固定するM2ネジ位置

**完了チェック**

- [ ] PCB、トッププレート、キースイッチがベースケースに収まっている
- [ ] 電源スイッチノブで基板上の電源スイッチを操作できる
- [ ] トッププレートのフチがベースケースに沿っている
- [ ] 左右それぞれ4箇所を、使用するトッププレートに合った長さのM2ネジで固定した
- [ ] ネジを締めすぎてケースやトッププレートが変形していない

### 8. バッテリーの固定
外しておいたバッテリーをコネクタに差し込み直して、バッテリー用のスペースに格納します。
バッテリーが振動などで破損しないように、バッテリー裏面を両面テープなどでケースに固定することを強く推奨します。

|シルクスクリーンの印刷|極性|
|---|---|
|BAT+|正極（赤色のケーブル）|
|GND|負極（黒色のケーブル）|

> [!CAUTION]
> LiPoバッテリーはショートや強い曲げ、穴あき、圧迫で発熱・発火する可能性があります。接続作業中はUSBケーブルを抜き、電源スイッチをOFFにします。赤黒のリード線やコネクタ端子を金属工具で同時に触れないでください。
> バッテリーの極性を間違えて接続するとマイコンが壊れて修復不能になる場合があります。バッテリーやケーブルがネジ穴、トップカバー、PCBに挟まれないことも確認してください。

バッテリーをケース内のスペースに収めた状態

**完了チェック**

- [ ] バッテリーコネクタが奥まで差し込まれている
- [ ] `BAT+`に赤色のケーブル、`GND`に黒色のケーブルが接続されている
- [ ] バッテリーがケース内のスペースに収まっている
- [ ] バッテリーやケーブルがネジ穴、トップカバー、PCBに挟まれない
- [ ] バッテリーがケース内で動かないように固定されている

### 9. インジケーターの取り付け
> [!NOTE]
> インジケーター穴ありトップカバーを使う場合のみ行います。穴なしトップカバーを使う場合は、このステップは実施不要です。

直径2mm透明プラ棒（3mm程度）をトップカバーに差し込みます。
FDMプリントなど熱収縮がある素材と3Dプリント方法の場合、プラ棒が入らない場合があるため、カッターやドリルなどで穴径を広げます。
接着はまだしません。

トップカバーのインジケーター穴に透明プラ棒を差し込んだ状態

**完了チェック**

- [ ] 透明プラ棒を左右それぞれ必要な位置に差し込んだ

### 10. トップカバーの取り付け
インジケーターを付けた場合はここでPCBとインジケーターの隙間を調整し、上面に出ている不要な分はニッパーなどで切って調整したあとに接着剤などを使ってカバーの側から接着してください。
トップカバーをベースケースに固定した状態

トップカバーを左右それぞれ3箇所のM2 4mmネジで固定します。
トップカバーを固定するM2ネジ位置

**完了チェック**

- [ ] （インジケーターありの場合）透明プラ棒の長さを調整して固定した
- [ ] トップカバーを左右それぞれ3箇所のM2 4mmネジで固定した
- [ ] トップカバーが浮かず、ベースケースに沿っている

### 11. キーキャップの取り付け
用意したキーキャップをスイッチに装着します。

**完了チェック**

- [ ] すべてのキーキャップを取り付けた
- [ ] キーキャップが隣のキーやケースに干渉せず、必要なキーを押せることを確認した

### 12. 滑り止めの取り付け（任意）
3Dプリントしたケースや使うデスクの材質によってはキーボードが滑ることがあるので、お好みに応じてケースの裏側に両面テープなどでポロンシートやすべり止めシートを貼り付けます。

**完了チェック**

- [ ] 必要に応じて滑り止めを貼り、キーボードを置いたときにがたつきがないことを確認した

## 参考: 完成状態
ケースの組み立てが完了すると、以下のような状態になります。写真はChocキースイッチとChoc用キーキャップを使用した例です。

ChocキースイッチとChoc用キーキャップで組み立てたCLEAVE HHJPの完成状態

## ステップの完了
ついにキーボードが完成しました。
次のガイドではこのキーボードの使い方を確認しましょう。
- [次: 完成後の使い方](04-USAGE.md)
- [目次に戻る](README.md)

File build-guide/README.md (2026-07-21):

# CLEAVE HHJP ビルドガイド

CLEAVE HHJP の組み立て、ファームウェア書き込み、ケース作成、完成後の使い方、カスタマイズ方法をまとめたガイドです。

> [!WARNING]
> CLEAVE HHJPを組み立てる際は、関連するガイドをよく読んでから作業を開始してください。
> ガイドを遵守しない場合、故障や事故の原因となる可能性があります。

## 概算費用

総額：¥20,000~

工具代と送料を除いた目安です。価格は購入先、在庫、為替、MX/Choc両対応か、選ぶケース方式や素材によって大きく変わります。

| 項目 | 目安 | 内容 |
|---|---|---|
| キット | 7,000円 | PCB、ダイオード、電源スイッチ、バッテリーコネクタ、ケース用ネジ類など |
| マイコン | 4,000円程度 | XIAO nRF52840 Plus 2個 |
| ケース部品 | 自家プリント: 約1,000〜3,000円<br>外注: 約8,000〜10,000円 | 標準ケースを3Dプリントする場合の目安です。簡易ケースキットやオリジナルケースでは必要な部品と費用が変わります。 |
| 購入者が独自に用意するもの | 〜5,000円 | LiPoバッテリー、ホットスワップソケット、フォームテープ、滑り止めなど |

※キースイッチおよびキーキャップは上記に含まれません。

## ビルドの進め方

### お手軽キット

お手軽キットは、電子部品の実装とファームウェアの書き込みが完了した状態で届きます。[お手軽キット組み立てガイド](03-EASY_KIT.md)から開始し、組み立てが完了したら[完成後の使い方](04-USAGE.md)、必要に応じて[カスタマイズガイド](05-CUSTOMIZE.md)へ進んでください。

### 通常キット

このガイドでは、必要なものをまとめて準備したあと、基板を組み立て、ファームウェアを書き込んで基板単体で動作確認し、その後、準備ガイドで決めたケース方式に沿ってケースへ組み込む流れを標準的な進め方とします。

> [!NOTE]
> ガイド内の画像には、開発途中の基板やケースが写っているものが含まれます。
> そのため実際の見た目と完全には一致しない場合がありますが、説明している箇所には影響ありません。

| 順番 | ガイド | 作業の位置付け |
|---|---|---|
| 0 | [準備ガイド](00-PREPARE.md) | 購入・発注前に決めること、必要な工具、電子部品、選ぶケース方式ごとに必要な部材を確認します。 |
| 1 | [基板組み立てガイド](01-ASSEMBLY.md) | 準備した部品を基板へ実装し、ファームウェア書き込み後の基板単体確認に備えてキースイッチとバッテリーを接続します。 |
| 2 | [ファームウェアのダウンロード・書き込み・接続確認](02-FIRMWARE.md) | 左右それぞれのXIAO nRF52840 PlusへUF2ファイルを書き込み、基板単体で動作確認します。 |
| 3-A | [標準ケースビルドガイド](03-0-STANDARD_CASE.md) | 配布されている3Dモデルを使って標準ケースを作成し、基板を組み込みます。 |
| 3-B | [簡易ケースビルドガイド](03-1-SIMPLE_CASE.md) | 簡易ケースキットを使って基板を組み込みます。 |
| 3-C | [オリジナルケース作成ガイド](03-2-CUSTOM_CASE.md) | STEPファイルを参照して、独自に設計したケースへ基板を組み込みます。 |
| 4 | [完成後の使い方](04-USAGE.md) | ケース組み立て後の最終確認、電源、Bluetooth接続、充電方法を確認します。 |
| 5 | [カスタマイズガイド](05-CUSTOMIZE.md) | 必要に応じてキーマップやファームウェア設定の変更方法を確認します。 |

ケース方式は、購入・発注前に[準備ガイド](00-PREPARE.md#ケース関連)で決めておきます。
ケースなしの状態での常用は端子短絡などの危険性があるため推奨しません。

## ビルド関連リンク

- [ファームウェア配布ページ](https://github.com/Rimebeck/Cleave-HHJP/releases)
- [ケースの3Dモデル・PCB 3Dデータ](https://github.com/Rimebeck/Cleave-HHJP/tree/main/models)
- [ZMK Studio](https://zmk.studio)

## 問い合わせ・不具合報告

ご不明な点はビルドガイドリポジトリの[Issues](https://github.com/Rimebeck/Cleave-HHJP/issues)またはBOOTHの購入者問合せからご連絡ください。

## 著作権・利用条件

本ビルドガイドに掲載している文章、写真、図版などの著作権は、特に記載のない限りRimebeck Worksに帰属します。
無断転載、再配布、本キーボードに関連する用途以外での利用はご遠慮ください。

引用、紹介、レビュー、個人利用の範囲での参照については、出典として本リポジトリまたはBOOTH販売ページへのリンクを記載してください。

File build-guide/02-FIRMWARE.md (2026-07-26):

# ファームウェアのダウンロード・書き込み・接続確認

[目次に戻る](README.md)

CLEAVE HHJPはファームウェアをダウンロードし、左右それぞれのXIAO nRF52840 Plusへ書き込み、接続確認を行います。

## 目次

- [ファームウェアのダウンロード](#ファームウェアのダウンロード)
- [ブートローダーモードへの入り方](#ブートローダーモードへの入り方)
- [ファームウェアの書き込み](#ファームウェアの書き込み)
- [接続確認・動作確認](#接続確認動作確認)
- [トラブルシューティング](#トラブルシューティング)

## ファームウェアのダウンロード

[ファームウェアのダウンロードページ](https://github.com/Rimebeck/Cleave-HHJP/releases)から最新バージョンの以下のUF2ファイルをダウンロードしてください。

- `settings_reset-seeeduino_xiao_ble-zmk.uf2`
- `cleave_hhjp_left rgbled_adapter-seeeduino_xiao_ble-zmk.uf2`
- `cleave_hhjp_right rgbled_adapter-seeeduino_xiao_ble-zmk.uf2`

> [!NOTE]
> `settings_reset`用ファームウェアは、分割キーボードのペアリングやBluetooth接続に関する設定を初期化するために書き込むクリーンアップ用のファームウェアです。

## ブートローダーモードへの入り方

XIAO nRF52840 Plusをブートローダーモードにすると、`XIAO-SENSE`（別の名前で認識される場合があります）という名前のUSBドライブとして認識されます。

1. PCと書き込み対象のXIAO nRF52840 PlusをUSB Type-Cケーブルで接続します。
2. RESETボタンを爪楊枝の柄側など尖りすぎていない道具を使って素早く2回押します。（ダブルクリック）

    XIAO nRF52840 PlusのRESETボタン位置

3. `XIAO-SENSE`（別の名前で認識される場合があります）ドライブが表示されます。

## ファームウェアの書き込み

UF2ファイルは、`XIAO-SENSE`ドライブへドラッグ&ドロップ、またはFinder / エクスプローラーからコピーして書き込みます。

1. 左側のXIAO nRF52840 Plusをブートローダーモードにします。
2. `XIAO-SENSE`ドライブに`settings_reset-seeeduino_xiao_ble-zmk.uf2`を書き込みます。
3. 書き込みが完了すると`XIAO-SENSE`ドライブが消え、自動的に再起動します。
4. もう一度ブートローダーモードにします。
5. `XIAO-SENSE`ドライブに`cleave_hhjp_left rgbled_adapter-seeeduino_xiao_ble-zmk.uf2`を書き込みます。
6. 右側も同様に、`settings_reset-seeeduino_xiao_ble-zmk.uf2`と`cleave_hhjp_right rgbled_adapter-seeeduino_xiao_ble-zmk.uf2`を順番に書き込みます。
7. 両方の書き込みが完了したら、次の接続確認・動作確認に進みます。
> [!NOTE]
> macOSではUF2ファイルのコピー後にエラーが表示される場合がありますが、コピー後に`XIAO-SENSE`ドライブが消えて自動的に再起動していれば、書き込みは完了しています。

## 接続確認・動作確認

ケースへ組み込む前に、左右の基板がBluetoothで接続でき、仮取り付けしたキースイッチが入力として認識されることを確認します。

1. 近くに他のCLEAVE HHJPがある場合は、ほかのペアの電源を切ります。
2. 左右のUSBケーブルを抜き、左右の電源スイッチをONにします。左右間のペアリングは電源を入れると自動的に行われます。
3. 右側のXIAO nRF52840 Plusの内蔵LEDを確認します。右側のLEDは左右のキーボード間の接続状態を示し、左側と接続済みになると青色、ペアリング待ちや接続先の左側を探している間は黄色、未接続のときは赤色に一回点灯します。これは充電LEDとは別の表示です。
4. PCやスマートフォンのBluetooth設定を開き、`CLEAVE HHJP`を選択して接続します。
5. 左側のXIAO nRF52840 Plusの内蔵LEDを確認します。左側のLEDはPCやスマートフォンとの接続状態を示し、ファーム書き込み直後など空のBluetoothプロファイルでペアリング待ちになっている間は黄色、接続済みになると青色に一回点灯します。
6. 以下のリンクからキーテスターを開き、仮取り付けしたキースイッチを押します。
https://rimebeck.github.io/Keyboard-tester/?keyboard=wlsphhjp

7. 左右どちらの基板に取り付けたキースイッチも入力できることを確認します。

`CLEAVE HHJP`が表示されない、接続できない、または一部のキーが反応しない場合は、[トラブルシューティング](#トラブルシューティング)を確認してください。

> [!NOTE]
> 左右のペアリングは、ZMKがシールド名から生成するBluetooth UUIDを使って自動的に行われます。複数のCLEAVE HHJPを同時にセットアップすると意図しない左右の組み合わせでペアリングされる可能性があるため、初回セットアップ時やペアリングリセット後は1ペアずつ電源を入れてください。一度正しくペアリングが確立すれば、以降は複数ペアを同時に使用しても問題ありません。

## トラブルシューティング

### ブートローダーモードに入らない

- RESETボタンを素早く2回押しているか確認します。うまく入らない場合は、少し間隔を空けて2回押し直してください。
- USB Type-Cケーブルが充電専用ではなく、データ通信に対応しているものか確認します。
- `XIAO-SENSE`ドライブが表示されない場合は、一度USBケーブルを抜き差ししてから再度RESETボタンを2回押します。
- 左右をケースに入れた後は、RESETボタンに工具が届くか確認してから作業してください。

### UF2コピー後にドライブが消えない

UF2ファイルの書き込みが成功すると、`XIAO-SENSE`ドライブは自動的に消えて再起動します。

- コピーしたUF2ファイルが対象の側と合っているか確認します。左側には`cleave_hhjp_left...uf2`、右側には`cleave_hhjp_right...uf2`を書き込みます。
- `settings_reset`を書き込んだ後は、もう一度ブートローダーモードに入ってから左右それぞれのUF2を書き込みます。
- ドライブが消えない場合は、ファイルを削除してやり直すのではなく、USBケーブルを抜き差ししてブートローダーモードに入り直してから再度コピーします。
- macOSではコピー後にエラーが表示される場合がありますが、`XIAO-SENSE`ドライブが消えて再起動していれば書き込みは完了しています。

### Bluetoothに表示されない

- 左右両方の電源スイッチがONになっているか確認します。
- PCやスマートフォン側に古い`CLEAVE HHJP`の登録が残っている場合は、OS側の登録を削除してから再検索します。キーボード側のペアリング情報も消す場合は`Ctrl` + `Fn` + `Backspace`で現在のプロファイルをクリアします。
- 初回セットアップでは、近くにある他のCLEAVE HHJPの電源を切り、1ペアだけを起動してペアリングします。
- 左右のUF2を書き込む前に`settings_reset`を書き込んだか確認します。未実施の場合は、左右とも`settings_reset`から書き込み直します。

### 左右が接続しない

- 左右に正しいUF2を書き込んでいるか確認します。左基板には左用、右基板には右用のUF2を書き込みます。
- 左右の電源を一度OFFにし、左側、右側の順に電源を入れ直します。
- 近くに別のCLEAVE HHJPがある場合は、他のペアの電源を切ってから再ペアリングします。
- それでも接続しない場合は、左右両方に`settings_reset`を書き込み、その後に左右それぞれのUF2を書き込み直します。

### 一部のキーが反応しない

- 反応しないキーのキースイッチがホットスワップソケットに正しく差し込まれているか確認します。スイッチのピンが曲がっている場合は、まっすぐに直して差し込み直します。
- 該当キーのホットスワップソケットのはんだ付けに浮きや未はんだがないか確認します。
- ダイオードの向きが正しいか確認します。スイッチングダイオードは、部品の線がフットプリントのコの字側に合っている必要があります。
- 複数のキーがまとまって反応しない場合は、XIAO nRF52840 Plus周辺のはんだブリッジや未はんだを確認します。
- 右側だけが反応しない場合は、左右間の接続が確立しているかを先に確認します。

## ステップの完了
おめでとうございます！これで基板単体でのファームウェア書き込みと動作確認が完了しました。
続いて、準備ガイドで決めたケース方式のガイドへ進み、常用できる状態に仕上げます。
- [前: 基板組み立てガイド](01-ASSEMBLY.md)
- [次（標準ケース）: 標準ケースビルドガイド](03-0-STANDARD_CASE.md)
- [次（簡易ケース）: 簡易ケースビルドガイド](03-1-SIMPLE_CASE.md)
- [次（オリジナルケース）: オリジナルケース作成ガイド](03-2-CUSTOM_CASE.md)
- [目次に戻る](README.md)

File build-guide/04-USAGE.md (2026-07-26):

# CLEAVE HHJP 完成後の使い方

[目次に戻る](README.md)

## 目次

- [基本操作](#基本操作)
- [ChocとMXを相互に交換する方法](#chocとmxを相互に交換する方法)
- [Bluetooth 接続](#bluetooth-接続)
- [充電](#充電)
- [キーマップ変更](#キーマップ変更)
- [周辺アクセサリ](#周辺アクセサリ)
- [使い始めの確認](#使い始めの確認)

## 基本操作

### デフォルトキーマップ

初期状態のキー割り当てはHHKBと同じ以下の通りです。

CLEAVE HHJPのデフォルトキーマップ

以下のリンクからキーテスターを使用することで正常に動作しているかを確認できます。

https://rimebeck.github.io/Keyboard-tester/?keyboard=wlsphhjp

### 電源スイッチ

左右のケース側面にある電源スイッチで、左右それぞれの電源をON/OFFします。キーボードとして使用する場合は、左右両方の電源をONにします。
電源スイッチをOFFにすると、その側のキーボード動作は停止します。USB Type-Cケーブル経由で給電している場合は、電源スイッチがOFFでも充電・動作できます。

### ステータスLEDの見方

左右それぞれのXIAO nRF52840 Plusには、キーボードの状態を示す内蔵LEDがあります。これは[充電 LED](#充電-led-の確認)とは別の表示です。

下の写真では、充電LEDを緑、ステータスLEDを橙で示しています。

XIAO nRF52840 Plusの充電LEDとステータスLEDの位置

電源をONにすると、内蔵LEDはバッテリー残量と接続状態を順に約1秒ずつ表示します。

| 順番 | 表示内容 | 色の意味 |
|---|---|---|
| 1回目 | バッテリー残量 | 緑: 80%以上<br>黄: 20〜80%<br>赤: 20%未満 |
| 2回目 | 接続状態 | 接続先によって意味が異なります。下の表を確認してください。 |

2回目の接続状態は、左右で示す対象が異なります。

| LED | 示す接続状態 | 色の意味 |
|---|---|---|
| 左側のLED | PCやスマートフォンとのBluetooth接続 | 青: 接続済み<br>黄: ペアリング待ち（ファーム書き込み直後や空プロファイル）<br>赤: 未接続 |
| 右側のLED | 左右のキーボード間の接続 | 青: 左側と接続済み<br>黄: 左側とのペアリング待ち（左側の電源が入っていない/見つからない）<br>赤: 左側と未接続 |

### USB 接続時の挙動

USB接続は以下の用途で使用します。

- ファームウェアの書き込み
- 充電
- ZMK Studioでのキーマップ変更（詳細は[カスタマイズガイド](05-CUSTOMIZE.md)を参照）

通常のキー入力はBluetooth接続で行います。ZMK Studioを使用する場合は、左側キーボードをUSB接続します。

## ChocとMXを相互に交換する方法

CLEAVE HHJPは、MX互換スイッチとChocV1/V2互換スイッチの両方のホットスワップソケットを実装している場合、スイッチを交換して相互に切り替えられます。トッププレートの扱いはケース方式によって異なります。

- 標準ケース: MX用とChoc用でトッププレートが異なります。
- 簡易ケースキット: 同じトッププレートを使用します。

交換時に用意・確認するトッププレートと固定ネジは以下の通りです。

| ケース方式 | トッププレート | Choc時の固定ネジ | MX時の固定ネジ | 参照先 |
|---|---|---|---|---|
| 標準ケース | Choc用とMX用で別 | M2 8mm | M2 10mm | [標準ケースビルドガイド](03-0-STANDARD_CASE.md) |
| 簡易ケースキット | Choc/MX共通 | M2 5mm | M2 8mm | [簡易ケースビルドガイド](03-1-SIMPLE_CASE.md) |
| オリジナルケース | 設計したケースに合わせる | 設計したケースに合わせる | 設計したケースに合わせる | [オリジナルケース作成ガイド](03-2-CUSTOM_CASE.md) |

### 用意するもの

- 交換先のスイッチとキーキャップ
- 使用しているケース方式と交換先のスイッチに合ったM2ネジ
- 標準ケースの場合: 交換先のスイッチに対応した左右のトッププレート
- 簡易ケースキットの場合: 交換先のスイッチに合ったスペーサー
- キーキャッププラー、ドライバーなど分解に使う工具

### 交換手順

1. 左右の電源スイッチをOFFにし、USB Type-Cケーブルを抜きます。
2. キーキャップを外します。
3. トップカバーのM2 4mmネジを外してトップカバーを外します。参照先はケース方式に合わせます。
   - 標準ケース: [標準ケースガイドの10. トップカバーの取り付け](03-0-STANDARD_CASE.md#10-トップカバーの取り付け)
   - 簡易ケースキット: [簡易ケースガイドの8. トップカバーの取り付け](03-1-SIMPLE_CASE.md#8-トップカバーの取り付け)
4. バッテリーコネクタを基板から外します。バッテリーそのものをケースから外す必要はありませんが、バッテリーを固定している両面テープを一時的に剥がす必要がある場合は、バッテリー本体やリード線に無理な力をかけないように慎重に作業します。
5. トッププレートを固定している4箇所のM2ネジを外し、PCB、トッププレート、キースイッチが一体になった部品をケース本体から慎重に取り出します。ケーブルを引っ掛けないように注意してください。
6. 古いスイッチを外します。スイッチのピンを曲げないように、まっすぐ外してください。
   - 標準ケース: スイッチ種別を変更する場合は、トッププレートも交換します。
   - 簡易ケースキット: トッププレートは同じものを使います。
7. 交換先のスイッチをトッププレートにはめ込みます。参照先はケース方式に合わせます。
   - 標準ケース: 交換先のスイッチに合ったトッププレートを使い、[標準ケースガイドの4. キースイッチ取り付け](03-0-STANDARD_CASE.md#4-キースイッチ取り付け)から進めます。
   - 簡易ケースキット: 同じトッププレートを使い、[簡易ケースガイドの4. キースイッチ取り付け](03-1-SIMPLE_CASE.md#4-キースイッチ取り付け)から進めます。
8. ケース方式ごとの手順に沿って組み直します。
   - 標準ケース: [5. トッププレートの取り付け](03-0-STANDARD_CASE.md#5-トッププレートの取り付け)、[7. PCBの取り付け](03-0-STANDARD_CASE.md#7-pcbの取り付け)、[8. バッテリーの固定](03-0-STANDARD_CASE.md#8-バッテリーの固定)、[10. トップカバーの取り付け](03-0-STANDARD_CASE.md#10-トップカバーの取り付け)、[11. キーキャップの取り付け](03-0-STANDARD_CASE.md#11-キーキャップの取り付け)を行います。
   - 簡易ケースキット: [5. トッププレートの取り付け](03-1-SIMPLE_CASE.md#5-トッププレートの取り付け)、[6. PCBの取り付け](03-1-SIMPLE_CASE.md#6-pcbの取り付け)、[7. バッテリーの固定](03-1-SIMPLE_CASE.md#7-バッテリーの固定)、[8. トップカバーの取り付け](03-1-SIMPLE_CASE.md#8-トップカバーの取り付け)を行います。
9. 組み直したあと、左右の電源をONにして、すべてのキーが入力できることを確認します。

**完了チェック**

- [ ] 標準ケースでは、交換先のスイッチに対応したトッププレートを使っている
- [ ] 簡易ケースキットでは、共通トッププレートに交換先のスイッチに合ったスペーサーを取り付けている
- [ ] スイッチがトッププレートにまっすぐ収まっている
- [ ] スイッチのピンが曲がらず、対応するホットスワップソケットに入っている
- [ ] トッププレートを、ケース方式とスイッチ種別に合った長さのM2ネジで固定した
- [ ] バッテリーコネクタを接続し直し、バッテリーやケーブルがケース内で挟まれていない
- [ ] キーキャップが隣のキーやケースに干渉していない
- [ ] 左右すべてのキーが入力できる

## Bluetooth 接続

左右の電源をONにすると、左右間の接続は自動で行われます。PCやタブレットなどのホスト機器には、Bluetooth設定から`CLEAVE HHJP`を選択して接続します。

### Bluetooth デバイス切り替え

CLEAVE HHJPは最大5つのBluetooth接続先を切り替えて使用できます。

接続先を切り替えるには、`Ctrl`を押しながら`Fn` + `1`〜`5`を押します。

| 操作 | 接続先 |
|---|---|
| `Ctrl` + `Fn` + `1` | Bluetoothプロファイル1 |
| `Ctrl` + `Fn` + `2` | Bluetoothプロファイル2 |
| `Ctrl` + `Fn` + `3` | Bluetoothプロファイル3 |
| `Ctrl` + `Fn` + `4` | Bluetoothプロファイル4 |
| `Ctrl` + `Fn` + `5` | Bluetoothプロファイル5 |

新しい機器とペアリングする場合は、空いているプロファイルに切り替えてから、接続先のBluetooth設定で`CLEAVE HHJP`を選択します。

### リセット方法の選び方

| やりたいこと | 使う方法 | 消えるもの | 参照先 |
|---|---|---|---|
| 接続先のPCやスマートフォンとのペアリングをやり直す | 現在のBluetoothプロファイルをクリアする（キーマップ上では`&bt BT_CLR`） | 選択中のBluetoothプロファイルに記録された接続先情報 | [ペアリングリセット](#ペアリングリセット) |
| 左右の接続や永続化設定を初期化して、初回書き込みからやり直す | `settings_reset`用ファームウェアを書き込む | キーボード本体に保存されたBluetoothやZMKの永続化設定 | [ファームウェアの書き込み](02-FIRMWARE.md#ファームウェアの書き込み) |
| ZMK Studioで保存したキーマップを初期状態に戻す | ZMK StudioのRestore Stock Settingsを実行する | ZMK Studioで保存したキーマップ設定 | [カスタマイズガイドのトラブルシューティング](05-CUSTOMIZE.md#ファームウェアを書き込んだのにキーマップが変わらない) |

### ペアリングリセット

接続先の機器を変更したい場合や、以前のペアリング情報が残っていて接続できない場合は、現在選択中のBluetoothプロファイルをリセットします。

1. リセットしたいBluetoothプロファイルに切り替えます。
2. `Ctrl`を押しながら`Fn` + `Backspace`を押します。
3. 接続先のOS側に残っている`CLEAVE HHJP`の登録を削除します。
4. もう一度Bluetooth設定から`CLEAVE HHJP`を選択してペアリングします。

複数のCLEAVE HHJPを同時にセットアップする場合は、意図しない組み合わせで左右がペアリングされないように、1ペアずつ電源を入れて設定してください。

## 充電

### 充電方法

左右それぞれのXIAO nRF52840 PlusにUSB Type-Cケーブルを接続して充電します。左右のバッテリーは独立しているため、必要に応じて片側ずつ充電できます。

充電はXIAO nRF52840 Plusの充電ICによって自動で制御されます。USB給電中は、電源スイッチがOFFの状態でも充電・動作できます。

### 充電 LED の確認

充電状態はXIAO nRF52840 Plusの充電LEDで確認します。

| 充電LED | 状態 |
|---|---|
| 緑色点灯 | 充電中 |
| 消灯 | 充電完了 |

充電LEDはキーボードの動作状態を示すLEDとは別のLEDです。USBケーブルを接続しても充電LEDが点灯しない場合（満充電で消灯している場合を除く）は、ケーブル、USBポート、バッテリーコネクタの接続を確認してください。

## キーマップ変更

日常的なキー割り当ての変更は、左側キーボードをUSB接続してZMK Studioで行います。初期キーマップ、レイヤー構成、マクロ、Bluetooth設定などファームウェア側の定義を変更したい場合は、このリポジトリをフォークしてUF2ファイルをビルドします。

詳しい手順は、[CLEAVE HHJP カスタマイズガイド](05-CUSTOMIZE.md)を参照してください。

## 周辺アクセサリ

### マグネット変換アダプタ

USB Type-Cケーブルを頻繁に抜き差しする場合は、マグネット式の変換アダプタを使うと、XIAO nRF52840 PlusのUSBポートへの負荷を減らせます。マイコンのUSBポートの破損（モゲ）や、ポート摩耗の予防になります。ファームウェア書き込みやZMK Studioでも使う場合は、データ通信対応品を選んでください。

購入例: [マグネット変換アダプタ](https://www.amazon.co.jp/dp/B0FJ22NG8D)

マグネット変換アダプタを取り付けたUSB Type-Cポート

### 持ち運び用ポーチ

Choc版の持ち運び用ポーチとして、[エレコム トラベルポーチ BMA-F01XNV](https://amzn.asia/d/06oVbq20)がちょうどよく収まります。（MX版は高さが足りないため、このポーチには収納できません。）

## 使い始めの確認

ケースまで組み立てたら、使い始めるタイミングで以下を確認します。
基板単体での確認はファームウェア書き込み時に行っているため、ここではケース組み立て後の最終確認を行います。

- [ ] 左右の電源スイッチをONにすると、左右それぞれのXIAO nRF52840 Plusが起動する
- [ ] PCのBluetooth設定に`CLEAVE HHJP`が表示される
- [ ] `CLEAVE HHJP`へBluetooth接続できる
- [ ] 左右のキーがどちらも入力できる
- [ ] USBケーブルを接続すると、充電LEDの表示を確認できる
- [ ] 充電中は充電LEDが緑色に点灯し、充電完了時は消灯する

### うまくいかない場合

| 症状 | 確認すること |
|---|---|
| PCのBluetooth設定に`CLEAVE HHJP`が表示されない | [ファームウェアガイドの「Bluetoothに表示されない」](02-FIRMWARE.md#bluetoothに表示されない)を確認します。 |
| `CLEAVE HHJP`へBluetooth接続できない | OS側の登録を削除してから、[ペアリングリセット](#ペアリングリセット)を行います。 |
| 左右どちらかのキーが入力できない | [ファームウェアガイドの「左右が接続しない」](02-FIRMWARE.md#左右が接続しない)を確認します。 |
| 一部のキーだけ反応しない | [ファームウェアガイドの「一部のキーが反応しない」](02-FIRMWARE.md#一部のキーが反応しない)を確認します。 |
| 充電LEDが点灯しない | 満充電で消灯している場合を除き、USBケーブル、USBポート、バッテリー固定を確認します。標準ケースは[標準ケースガイドのバッテリー固定](03-0-STANDARD_CASE.md#8-バッテリーの固定)、簡易ケースは[簡易ケースガイドのバッテリー固定](03-1-SIMPLE_CASE.md#7-バッテリーの固定)、オリジナルケースは[設計時のチェックポイント](03-2-CUSTOM_CASE.md#設計時のチェックポイント)を確認してください。 |

- [前（標準ケース）: 標準ケースビルドガイド](03-0-STANDARD_CASE.md)
- [前（簡易ケース）: 簡易ケースビルドガイド](03-1-SIMPLE_CASE.md)
- [前（オリジナルケース）: オリジナルケース作成ガイド](03-2-CUSTOM_CASE.md)
- [次: カスタマイズガイド](05-CUSTOMIZE.md)
- [目次に戻る](README.md)

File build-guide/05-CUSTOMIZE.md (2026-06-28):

# CLEAVE HHJP カスタマイズガイド

[目次に戻る](README.md)

この章ではCLEAVE HHJPのキーマップやファームウェア設定を変更する方法をまとめます。

> [!NOTE]
> 初期キーマップのまま使う場合、このガイドの作業は必須ではありません。
> キー配置やファームウェア設定を確認したくなったときに参照してください。

## 目次

- [カスタマイズ方法の選び方](#カスタマイズ方法の選び方)
- [ZMK Studioで変更する](#zmk-studioで変更する)
- [フォークしてファームウェアを変更する](#フォークしてファームウェアを変更する)
- [変更後の書き込みと確認](#変更後の書き込みと確認)
- [トラブルシューティング](#トラブルシューティング)
- [参考リンク](#参考リンク)

## カスタマイズ方法の選び方

| 方法 | 向いている変更 | 特徴 |
|---|---|---|
| ZMK Studio | キー割り当ての変更、既存レイヤー内の編集 | ファームウェアを再ビルドせずに変更できます。 |
| フォークして変更 | 初期キーマップ変更、レイヤー構成の変更、マクロやコンボの追加、スリープ時間やBluetooth設定の変更 | リポジトリ上の設定ファイルを編集し、GitHub ActionsでUF2ファイルを生成します。 |

### できることの比較

ZMK Studioで変更できる内容と、フォークが必要な内容の目安は以下の通りです。

| 変更内容 | ZMK Studioで変更 | フォークして変更 |
|---|---|---|
| 単一キーの割り当て変更 | ◯ | ◯ |
| 既存レイヤー内の複数キーの調整 | ◯ | ◯ |
| ファームウェアに定義済みの動作を別のキーへ割り当て | ◯ | ◯ |
| 新しいレイヤーを初期状態として追加 |  | ◯ |
| 新しいマクロ、コンボ、独自behaviorを定義 |  | ◯ |
| 物理レイアウトやマトリックス定義を変更 |  | ◯ |
| スリープ時間、Bluetooth接続数、BLE出力などを変更 |  | ◯ |

> [!IMPORTANT]
> ZMK Studioで保存した設定はキーボード本体の永続化領域に保存されます。
> その後に`cleave_hhjp.keymap`を変更したファームウェアを書き込んでも、ZMK Studioで保存した内容が優先される場合があります。
> ファームウェア側の初期キーマップに戻したい場合は、ZMK StudioのRestore Stock Settingsを実行するか、必要に応じて`settings_reset`用ファームウェアを書き込んでから左右用のUF2を書き込み直してください。

## ZMK Studioで変更する

以下の手順で、左側キーボードをZMK Studioに接続してキーマップを変更します。

> [!NOTE]
> CLEAVE HHJPではZMK Studioを左側キーボードで使用します。右側キーボードをUSB接続してもZMK Studioでは変更できません。

### 手順

1. 左側キーボードをUSB Type-CケーブルでPCに接続します。
2. [ZMK Studio](https://zmk.studio)を開きます。通常はブラウザ版を使用します。
3. `Connect`から`CLEAVE HHJP`を選択します。
4. キーマップを変更して保存します。
5. USBケーブルを抜き、Bluetooth接続で変更後のキーが動作することを確認します。

> [!NOTE]
> ZMK Studioにはブラウザ版とクライアント版があります。通常はブラウザ版で作業できますが、OSやブラウザのUSBシリアルポート権限、Web Serial APIの対応状況によって接続できない場合があります。その場合はクライアント版を使用してください。

## フォークしてファームウェアを変更する

リポジトリをフォークすると、自分用のコピーで設定ファイルを編集し、GitHub ActionsでCLEAVE HHJP用のUF2ファイルを生成できます。ローカルに専用のビルド環境を用意する必要はありません。

### 全体の流れ

| 段階 | やること |
|---|---|
| 1. Fork | GitHub上に自分用のリポジトリを作る |
| 2. Edit | キーマップや設定ファイルを変更する |
| 3. Build | GitHub ActionsでUF2ファイルを生成する |
| 4. Download | 生成された`firmware` artifactをダウンロードする |
| 5. Flash | 左右のXIAO nRF52840 PlusへUF2を書き込む |

GitHub Actionsは、GitHub上でファームウェアを自動ビルドする仕組みです。自分のPCにビルド環境を作らなくても、リポジトリに保存した変更からUF2ファイルを作成できます。

### 事前に用意するもの

- GitHubアカウント
- Webブラウザ
- UF2ファイルを書き込むためのUSB Type-Cケーブル
- ローカルで編集する場合は、Gitとテキストエディタ

GitHub上で直接ファイルを編集する場合は、Gitのコマンド操作は必須ではありません。GitHubのFork操作に慣れていない場合は、[GitHub公式のフォーク手順](https://docs.github.com/ja/pull-requests/collaborating-with-pull-requests/working-with-forks/fork-a-repo)も参照してください。

### 最初に変更するファイル

はじめてファームウェアを変更する場合は、まず`cleave_hhjp.keymap`だけを編集することを推奨します。

| 目的 | ファイル |
|---|---|
| キー割り当てを変更する | [`cleave_hhjp.keymap`](../config/cleave_hhjp.keymap) |
| スリープ時間やBluetooth関連の設定を変更する | [`cleave_hhjp.conf`](../config/boards/shields/cleave_hhjp/cleave_hhjp.conf) |
| 左右の配線やキーマトリックスを変更する | [`cleave_hhjp_left.overlay`](../config/boards/shields/cleave_hhjp/cleave_hhjp_left.overlay) / [`cleave_hhjp_right.overlay`](../config/boards/shields/cleave_hhjp/cleave_hhjp_right.overlay) |

通常のキーマップ変更では、`.overlay`、`build.yaml`、`west.yml`は変更しません。

### 最小限の変更例

たとえば、左上の`Esc`キーを`Tab`キーに変更する場合は、`cleave_hhjp.keymap`の`default_layer`内にある以下の割り当てを変更します。

変更前:

```dts
&kp ESC
```

変更後:

```dts
&kp TAB
```

このように、`&kp`の後ろにあるキーコードを別のキーコードへ置き換えます。キーの数は増減させず、1つの割り当てを1つの割り当てに置き換えてください。

> [!IMPORTANT]
> `bindings`内の割り当てはCLEAVE HHJPの70キー分あります。
> 追加や削除で数が変わるとビルドに失敗します。
> `<`、`>`、`;`、`{`、`}`も消さないようにしてください。

### ビルドしてUF2をダウンロードする

1. GitHubで[CLEAVE-HHJPリポジトリ](https://github.com/Rimebeck/Cleave-HHJP)を開き、`Fork`から自分のアカウントへフォークします。
2. フォークしたリポジトリでActionsが無効になっている場合は、`Actions`タブからワークフローを有効化します。
3. GitHub上で直接編集する場合は、対象ファイルを開いて鉛筆アイコンから編集します。ローカルで編集する場合は、フォークしたリポジトリをcloneして`cleave_hhjp.keymap`などの設定ファイルを編集します。
4. GitHub上で直接編集した場合は`Commit changes`で保存します。ローカルで編集した場合はcommitしてフォークしたリポジトリへpushします。
5. `Actions`タブで`Build ZMK firmware`の最新の実行結果を開きます。
6. ビルドが成功したら、`Artifacts`から`firmware`をダウンロードします。
7. ダウンロードしたファイルを展開します。
8. [ファームウェアのダウンロード・書き込み・接続確認](02-FIRMWARE.md)と同じ手順で、生成されたUF2ファイルを左右それぞれのXIAO nRF52840 Plusへ書き込みます。

> [!NOTE]
> GitHub Actionsの画面やartifactのダウンロード方法は、ZMK公式の[Installing ZMK](https://zmk.dev/docs/user-setup)にも説明があります。

### 変更対象ファイルの早見表

| やりたいこと | 見るファイル | 難易度 | 備考 |
|---|---|---|---|
| キーを入れ替えたい | [`cleave_hhjp.keymap`](../config/cleave_hhjp.keymap) | はじめて向け | まずはこのファイルだけを変更します。 |
| Fnレイヤーの割り当てを変えたい | [`cleave_hhjp.keymap`](../config/cleave_hhjp.keymap) | はじめて向け | `fn_layer`内の割り当てを変更します。 |
| スリープ時間などを変えたい | [`cleave_hhjp.conf`](../config/boards/shields/cleave_hhjp/cleave_hhjp.conf) | 中級 | 数値や設定名の意味を確認してから変更します。 |
| 左右別の設定を変えたい | [`cleave_hhjp_left.conf`](../config/boards/shields/cleave_hhjp/cleave_hhjp_left.conf) / [`cleave_hhjp_right.conf`](../config/boards/shields/cleave_hhjp/cleave_hhjp_right.conf) | 中級 | 変更したい側のファイルだけを編集します。 |
| 配線やマトリックスを変えたい | [`cleave_hhjp_left.overlay`](../config/boards/shields/cleave_hhjp/cleave_hhjp_left.overlay) / [`cleave_hhjp_right.overlay`](../config/boards/shields/cleave_hhjp/cleave_hhjp_right.overlay) | 上級 | 通常のカスタマイズでは触りません。 |
| ビルド対象を変えたい | [`build.yaml`](../build.yaml) | 上級 | 生成するUF2の種類を変える場合に編集します。 |
| ZMKや関連モジュールの依存を変えたい | [`west.yml`](../config/west.yml) | 上級 | 通常のキーマップ変更では触りません。 |

### キーマップ変更の考え方

キーマップは`cleave_hhjp.keymap`の`keymap`ノード内で定義されています。CLEAVE HHJPでは標準の`default_layer`と、`Fn`キーで使う`fn_layer`が定義されています。

主な記法は以下の通りです。

| 記法 | 内容 |
|---|---|
| `&kp A` | `A`キーを送信します。 |
| `&kp ESC` | `Esc`キーを送信します。 |
| `&mo 1` | 押している間だけレイヤー1を有効にします。 |
| `&trans` | 下のレイヤーの動作をそのまま通します。 |
| `&bt BT_SEL 0` | Bluetoothプロファイル1を選択します。 |
| `&bt BT_CLR` | 現在のBluetoothプロファイルをクリアします。 |

各レイヤーの`bindings`には、CLEAVE HHJPの70キー分の割り当てを定義します。数が不足していたり、余っていたり、セミコロンや括弧が抜けているとビルドに失敗します。

キーコードやbehaviorを詳しく調べたい場合は、ZMK公式の[Keymaps & Behaviors](https://zmk.dev/docs/keymaps)と[List of Keycodes](https://zmk.dev/docs/keymaps/list-of-keycodes)を参照してください。

## 変更後の書き込みと確認

Actionsの`firmware` artifactには、以下のUF2ファイルが含まれます。

- `settings_reset-seeeduino_xiao_ble-zmk.uf2`
- `cleave_hhjp_left rgbled_adapter-seeeduino_xiao_ble-zmk.uf2`
- `cleave_hhjp_right rgbled_adapter-seeeduino_xiao_ble-zmk.uf2`

書き込み方法は[ファームウェアのダウンロード・書き込み・接続確認](02-FIRMWARE.md)と同じです。左側には左側用UF2、右側には右側用UF2を書き込みます。

ZMK Studioで保存した設定を消してファームウェア側の初期キーマップを確認したい場合や、左右の接続を最初からやり直す場合は、先に左右へ`settings_reset`を書き込み、その後に左右それぞれのUF2を書き込み直します。

**完了チェック**

- [ ] 左側に左側用UF2を書き込んだ
- [ ] 右側に右側用UF2を書き込んだ
- [ ] 必要に応じて`settings_reset`から書き込み直した
- [ ] PC側に古いBluetooth登録が残っている場合は削除した
- [ ] Bluetoothで`CLEAVE HHJP`に接続できる
- [ ] 変更したキーが意図した通りに入力される
- [ ] FnレイヤーやBluetoothプロファイル切り替えが動作する

## トラブルシューティング

### ZMK Studioに表示されない

- 左側キーボードをUSB接続しているか確認します。右側キーボードを接続してもZMK Studio用のデバイスとしては使用しません。
- USB Type-Cケーブルがデータ通信に対応しているか確認します。
- ブラウザでZMK StudioにUSBシリアルポートへのアクセスを許可しているか確認します。
- ブラウザ版で接続できない場合は、[ZMK Studioのダウンロードページ](https://zmk.studio/download)からクライアント版をインストールして試します。
- うまく接続できない場合は、USBケーブルを抜き差しして左側キーボードを再接続してから、再度`Connect`を試します。

### ファームウェアを書き込んだのにキーマップが変わらない

- ZMK Studioで保存したキーマップがキーボード本体に残っている可能性があります。ZMK StudioのRestore Stock Settingsを実行するか、`settings_reset`を書き込んでから左右用UF2を書き込み直します。
- 左右のUF2を取り違えていないか確認します。左側には`cleave_hhjp_left...uf2`、右側には`cleave_hhjp_right...uf2`を書き込みます。
- OS側に古いBluetooth情報が残っている場合は、`CLEAVE HHJP`の登録を削除してから再ペアリングします。

### GitHub Actionsが動かない

- フォークしたリポジトリでActionsが有効になっているか確認します。
- GitHub上で直接編集した場合は、`Commit changes`で保存できているか確認します。
- ローカルで編集した場合は、フォークしたリポジトリへpushできているか確認します。
- `Actions`タブで最新の`Build ZMK firmware`を開いているか確認します。

### ビルドが失敗する

- `cleave_hhjp.keymap`の各レイヤーに70キー分の`bindings`があるか確認します。
- `<`、`>`、`;`、`{`、`}`の抜けや余りがないか確認します。
- 使っているキーコードやbehavior名がZMKで定義されているか確認します。
- 新しいマクロやコンボを追加した場合は、参照名と定義名が一致しているか確認します。

### Bluetooth接続が不安定になった

- PC側のBluetooth設定から`CLEAVE HHJP`を削除して再ペアリングします。
- 現在選択中のBluetoothプロファイルをクリアしてから再ペアリングします。
- それでも改善しない場合は、左右両方へ`settings_reset`を書き込み、その後に左右用UF2を書き込み直します。

## 参考リンク

- [ZMK Studio](https://zmk.studio)
- [ZMK Studio ダウンロードページ](https://zmk.studio/download)
- [GitHub公式: リポジトリをフォークする](https://docs.github.com/ja/pull-requests/collaborating-with-pull-requests/working-with-forks/fork-a-repo)
- [GitHub公式: GitHub Actions](https://docs.github.com/ja/actions)
- [ZMK公式: Installing ZMK](https://zmk.dev/docs/user-setup)
- [ZMK公式: Customizing ZMK](https://zmk.dev/docs/customization)
- [ZMK公式: Keymaps & Behaviors](https://zmk.dev/docs/keymaps)
- [ZMK公式: List of Keycodes](https://zmk.dev/docs/keymaps/list-of-keycodes)
- [ファームウェアのダウンロード・書き込み・接続確認](02-FIRMWARE.md)
- [標準ケースビルドガイド](03-0-STANDARD_CASE.md)
- [簡易ケースビルドガイド](03-1-SIMPLE_CASE.md)
- [オリジナルケース作成ガイド](03-2-CUSTOM_CASE.md)
- [PCB外形データ](../models/pcb)
- [ケースの3Dモデル](../models)
- [ファームウェア設計書](../docs/firmware_design.md)

- [前: 完成後の使い方](04-USAGE.md)
- [目次に戻る](README.md)

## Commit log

2026-01-02 Fix ZMK build error: Update board name from seeeduino_xiao_ble to xiao_ble
    - Changed board identifier to the correct ZMK board name 'xiao_ble'
    for Seeed Studio XIAO nRF52840 in all configuration files
    - Updated GitHub Actions workflow to use correct board name
    - Updated build.yaml with correct board identifier
    - Reverted unnecessary matrix_transform changes
    This fixes the "Invalid BOARD" CMake error in CI builds.
2026-01-02 Fix RC macro conflict: Move matrix transform from keymap to dtsi
    The build was failing due to RC macro namespace collision:
    - ZMK's modifiers.h defines RC(keycode) for Right Control modifier
    - Matrix transforms use RC(row,col) for position mapping
    Solution:
    - Moved default_transform definition from cleave_hhjp.keymap to cleave_hhjp.dtsi
    - The dtsi file includes <dt-bindings/zmk/matrix_transform.h> which provides
    the correct RC(row,col) macro for matrix transforms
    - The keymap file now only contains keymaps and behaviors, avoiding the
    macro conflict with <dt-bindings/zmk/keys.h>
    This follows ZMK's standard practice where device tree files handle hardware
    definitions (including matrix tr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
2026-01-02 Fix devicetree parse error: Move keymap to config root
    Root cause: The keymap file was located in boards/shields/ directory,
    causing ZMK to treat it as a devicetree overlay file. This resulted in
    parse errors when the devicetree parser encountered keymap-specific syntax.
    - Moved cleave_hhjp.keymap from config/boards/shields/cleave_hhjp/ to config/
    - Reverted unnecessary matrix_transform changes in cleave_hhjp.dtsi
    - Matrix transform remains in keymap file (will not be parsed as devicetree)
    File structure now follows ZMK standard:
    - config/cleave_hhjp.keymap - Keymap definitions (auto-detected by ZMK)
    - config/boards/shields/cleave_hhjp/ - Hardware devicetree files only
    This fixe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
2026-01-02 Fix keymap location: Move to shield directory per ZMK documentation
    Root cause: Keymap file was in wrong location (config/ instead of shield directory)
    According to ZMK official documentation:
    "For 'shield keyboards', this should be placed in the
    boards/shields/my_keyboard/my_keyboard.keymap file."
    The keymap file must be inside the shield directory, not at config root.
    When placed at config root, ZMK's build system treats it as a devicetree
    overlay instead of a keymap file, causing parse errors.
    - Moved cleave_hhjp.keymap from config/ to config/boards/shields/cleave_hhjp/
    - This matches ZMK's official pattern for shield keyboards
    - ZMK will now correctly recognize and process t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
2026-01-02 Fix devicetree parse error: Replace Unicode box-drawing with ASCII
    Root cause: Devicetree compiler (dtc) does not support Unicode characters
    within bindings blocks, even in comments. The Unicode box-drawing characters
    (┌─┬┐├┼┤└┴┘) were causing parse errors at column 447 on line 63.
    Solution: Replaced all Unicode box-drawing characters with ASCII equivalents
    in the bindings = <...> blocks:
    - ┌┬┐└┴┘ → + (corners and junctions)
    - ─ → - (horizontal lines)
    - ├┼┤ → | (vertical junctions)
    Changed in both layers:
    - default_layer bindings (lines 62-72)
    - fn_layer bindings (lines 79-89)
    This follows the pattern used by official ZMK keyboards (Corne, Kyr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
2026-01-02 Trigger CI rebuild: force cache refresh
    Previous builds may have cached the old devicetree processing results.
    This empty commit forces GitHub Actions to re-run the build with the
    latest keymap file that has ASCII-only comments.
2026-01-05 Add ZMK Studio support with physical layout
    Implemented ZMK Studio compatibility for dynamic keymap configuration:
    - Added physical layout definition with 70 keys positioned according to HHKB JP split layout
    - Enabled Studio RPC over USB UART for central (left) side
    - Disabled Studio locking to always allow keymap changes
    - Added storage configuration (SETTINGS, NVS, FLASH) for persisting changes
    - Configured chosen node to reference physical layout
    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
2026-01-05 Fix physical layout binding specification
    Fixed devicetree binding errors in physical layout definition:
    - Changed compatible from "zmk,physical-layout-position" to "zmk,key-physical-attrs"
    - Changed property from #physical-layout-cells to #key-cells
    - Updated cell count from 5 to 7 parameters
    - Reordered all 70 key parameters from (x, y, width, height, r) to (width, height, x, y, r, rx, ry)
    - Added rotation origin parameters (rx, ry) for all keys (set to 0 for non-rotated keys)
    Based on official ZMK binding specification:
    zmk/app/dts/bindings/zmk,key-physical-attrs.yaml
    Fixes build error: "devicetree error: <Node /key_physical_attrs> lacks #key-cells"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
2026-01-05 Change Studio RPC snippet from UART to CDC
    Changed snippet from studio-rpc-usb-uart to studio-rpc-usb-cdc to enable proper serial port enumeration for ZMK Studio web interface.
    Issue: Keyboard was recognized as USB device but not appearing in browser's serial port selection dialog.
    Root cause: studio-rpc-usb-uart does not create a CDC (Communications Device Class) serial port that browsers can access via Web Serial API.
    Solution: studio-rpc-usb-cdc creates proper CDC serial device that appears in browser's port selection.
2026-01-05 Fix ZMK Studio configuration per official documentation
    Fixed ZMK Studio connectivity issues by correcting snippet name and applying it via GitHub Actions workflow.
    Changes:
    1. build.yaml: Changed snippet from studio-rpc-usb-cdc (non-existent) to studio-rpc-usb-uart (official)
    2. GitHub Actions: Added -S studio-rpc-usb-uart flag to west build command
    3. GitHub Actions: Added -DCONFIG_ZMK_STUDIO=y to cmake-args
    Issue: Keyboard was recognized as USB device but not appearing in ZMK Studio serial port selection.
    Root cause:
    - studio-rpc-usb-cdc snippet does not exist in ZMK repository
    - GitHub Actions workflow was not applying the snippet (-S flag missing)
    - CONFIG_ZMK_STUDIO was set in .conf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
2026-01-05 Fix physical layout coordinate units for ZMK Studio
    Changed from incorrect millimeter-based values (1905 = 1U) to correct
    centi-keyunit values (100 = 1U). Previous coordinates were 19.05x too
    large, causing keys to render outside the visible area in ZMK Studio.
    Coordinate conversions:
    - 1U keys: 1905 → 100
    - 1.25U keys: 2381 → 125
    - 1.5U Tab: 2858 → 150
    - 1.75U Ctrl: 3334 → 175
    - 2U Shift: 3810 → 200
    - All X/Y positions: divided by 19.05
    This fixes the blank key display issue in ZMK Studio.
2026-01-05 Disable ZMK Studio locking in left side configuration
    Moved CONFIG_ZMK_STUDIO configuration from common config to
    side-specific configs per ZMK official documentation.
    - cleave_hhjp.conf: Removed CONFIG_ZMK_STUDIO=y and LOCKING=n
    - cleave_hhjp_left.conf: Added CONFIG_ZMK_STUDIO=y
    - cleave_hhjp_right.conf: Added CONFIG_ZMK_STUDIO=n
    For split keyboards, ZMK Studio should only be enabled on the
    central (left) side. This prevents both halves from appearing
    as separate Studio devices.
    Reference: https://zmk.dev/docs/features/studio
    "For split keyboards, you should do this only for your central/left side"
    Co-Authored-B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
2026-01-05 Restructure/official zmk layout (#1)
    * Prepare for directory restructure: update to matrix build workflow
    This workflow will be further updated after restructuring to official ZMK layout.
    * Restructure: Move to official ZMK directory layout
    - Move firmware/build.yaml → build.yaml (root level)
    - Move firmware/config/ → config/ (root level)
    - Move firmware/firmware_design.md → docs/firmware_design.md
    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
2026-01-05 Restructure/official zmk layout (#2)
    - Move firmware/README.md → README_FIRMWARE.md
    - Update GitHub Actions workflow paths:
    - Triggers: firmware/** → config/** + build.yaml
    - build.yaml path reference
    - Cache paths for west modules
    - Remove working-directory: firmware (work from root)
    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
2026-01-25 fix: use correct battery driver for XIAO nRF52840 (#3)
    Change battery driver from zmk,battery-nrf-vddh to zmk,battery-voltage-divider.
    The XIAO nRF52840 uses an external voltage divider circuit (1MΩ/510kΩ)
    on P0.31 (AIN7), controlled by P0.14, not the nRF52840's internal VDDH
    measurement used by nice!nano and similar boards.
    This fix enables accurate battery level reporting on XIAO nRF52840.
2026-04-16 fix: バッテリー充電不具合の修正 (GPIO_OPEN_DRAIN 追加) (#4)
    * fix: add GPIO_OPEN_DRAIN to vbatt power-gpios for battery charging
    - Add GPIO_OPEN_DRAIN flag to P0.14 in cleave_hhjp.dtsi to match ZMK
    official xiao_ble board definition
    - Without this flag, P0.14 is driven HIGH (push-pull) when inactive,
    interfering with BQ25100 charge IC and disabling battery charging
    - With GPIO_OPEN_DRAIN, P0.14 becomes high-impedance when inactive,
    preventing charge IC interference and P0.31 damage risk
    - Update README_FIRMWARE.md board name from seeeduino_xiao_ble to
    xiao_ble to match build.yaml
    * fix: define LED aliases directly to fix rgbled_adapter compatibility
    The zmk-rgbled-w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
2026-05-27 Add CLEAVE HHJP build guide documentation (#6)
    * init
    * commit
    * commit
    * commit
    * Update README.md
    * test
    * test
    * Update 1.jpg
    * Update README.md
    * Update README.md
    * 中間コミット
    * Update README.md
    * Update README.md
    * Update README.md
    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
    [base_case_left.stl, base_case_right.stl, power_switch_knob.stl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]
2026-05-28 位置合わせ用ピンヘッダの説明を更新 (#7)
    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
2026-05-29 add cut shape
    [left.step, right.step]
2026-05-30 部品名表記を修正
2026-06-17 簡易ケースビルドガイドの追加 (#8)
    * Create 03-1-SIMPLE_CASE.md
    * Update 03-1-SIMPLE_CASE.md
    * Update 00-PREPARE.md
    * fix ルート
    * restructure
    * restructure
    * Update 04-USAGE.md
    * Update 00-PREPARE.md
    * Update 00-PREPARE.md
    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
2026-06-17 画像のサイズ最適化
2026-07-21 お手軽キット用ビルドガイドを追加 (#9)
    * Add easy kit build guide
    * Format easy kit requirements as table
    * Separate easy kit materials and tools
    * Clarify easy kit assembly headings
    * Update 03-EASY_KIT.md
